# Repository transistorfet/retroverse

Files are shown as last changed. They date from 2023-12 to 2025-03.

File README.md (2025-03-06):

RetroVerse
==========

###### *Started August 06, 2023*

A collection of computer cards using the [VME bus](https://en.wikipedia.org/wiki/VMEbus) as a common
backplane, in the style of modular computer equipment, laboratory test equipment, and industrial
controls systems.  The project name is a combination of Retro-computers (newly designed and built
computers that are based on old CPUs and parts), and Versa (the V in VME, which stands for Versa
Module Eurocard).

I've always liked the VME bus for its adaptability.  It's an asynchronous bus with dynamic sizing,
so it can support both controllers and peripherals that require different signaling speeds and bus
widths to communicate, without requiring a specialized bus interface chip.  It supports multiple
controllers without the need for a special slot on the backplane, because it uses daisy chained
priority bus arbitration.  It's based on the Eurocard standard form factor, and uses standard and
readily available DIN41612 connectors, comes in a 3U variant, and it's possible to still buy
equipment that conforms to the standard, namely card cases and power supplies.  The 3U Eurocard
standard, which uses 160x100mm boards, is also fairly affordable for PCB printing, and it's possible
to make not-quite-standard 100x100mm cards, which can be printed for as low as $2.  The bus is
perhaps slow by modern standards, but for CPUs that are below 100MHz, it's the perfect bus to build
16-bit and 32-bit retro computers around.

So far, I have bought an off-the-shelf desktop card case from
[Schroff](https://schroff.nvent.com/en-de/products/enc24576-106) via Digikey (backordered), a used
Schroff 3U 11-slot backplane from eBay, and an affordable [MeanWell power
supply](https://www.meanwell.com/productPdf.aspx?i=488) to power it.  I've designed and built a CPU
card with a Motorola MC68030, onboard static RAM and Flash memory, and two serial ports, a small
16-bit memory card with up to 4MB of static RAM, and a board for handling the bus arbitration and
interrupt signals on the bus (separate from the CPU card since I intend to use multiple CPU cards in
the same system).  I've also built Tom Storey's CompactFlash card from
[COMET](https://github.com/tomstorey/COMET) to use as the main secondary storage for the system.
Before building these, I had also designed and built a generic card using an STM32 microcontroller
wired to the bus signals called
[BigBoy](https://github.com/transistorfet/retroverse/tree/main/components/bigboy), which I had hoped
to use as a bus analyzer, but it's a bit too slow for that, so I'll probably program it as a generic
peripheral instead.

I had originally intended to design and build my own backplane using 4-row connectors with some of
the P2 connector's signals on an extended P1, but I abandoned that idea in the interest of
interoperability with existing used VME equipment and ended up buying a used 11-slot Schroff
backplane from eBay.  Tom Storey has designed a 3-slot and 8-slot backplane as part of
[COMET](https://github.com/tomstorey/COMET) which is a good choice for those who wish to build their
own.

I also intend to eventually make an MC68010 version using only DIP chips and hopefully all hardwired
logic, so that there's no need for specialized PLD programmers.  I might also make cards with other
CPUs.  It should be possible for the system to support different CPUs in the same system at the same
time, running their own code.  My larger hope is for the VME bus to be used more broadly in the
hobbyist retro computer community as a common means of constructing systems.

Some of the design and build process was live-streamed and recordings are available at
[youtube.com/@transistorfet](https://www.youtube.com/@transistorfet)

Why VMEbus?
-----------

* it uses the eurocard form factor, and equipment such as cases can still be bought new or used

* it's asynchronous, so it can support devices operating at different speeds

* it supports dynamic bus sizing for 8-bit, 16-bit, and multiplexed 32-bit operations in 3U

* in the 6U form factor, it can also support full 32-bit or multiplexed 64-bit operations

* the DIN41612 connectors it uses are still widely available with solder tails

* supports cheap 3U board sizes of 100mm x 160mm or 100mm x 100mm

* also supports 6U board sizes for bigger and more complex devices

Why Not VMEBus?
---------------

* it can be a bit more complicated to interface to for simple 8-bit systems

* it's slower than newer buses like CompactPCI

* when using passive termination instead of active termination, it can draw a lot of current (2A+)
  with no cards

* each signal can draw a fair amount of current, which may be out of range for some logic chips (the
  standard requires that each pin can sink 48mA or more but typically it's <25mA in smaller and
  slower systems)

About VMEbus
------------

* [Understanding VMEBus](https://mdavidsaver.github.io/epics-doc/vme/understanding-vme.pdf)
* [VME FAQ from VITA](https://www.vita.com/VMEbus-FAQ)
* [VME P1 Connector Pinout](https://allpinouts.org/pinouts/connectors/buses/vme-versamodule-eurocard-p1/)
* [VME64](https://www.ge.infn.it/~musico/Vme/Vme64.pdf)

Other VME Projects
------------------

#### VMEbus prototyping card PCB:

* [https://github.com/rhaamo/VME](https://github.com/rhaamo/VME)

#### Proto Boards, Blanking Plates, Plate Adapters, ECB backplanes:

* [https://www.ebay.ca/usr/martenelectric](https://www.ebay.ca/usr/martenelectric)
* [https://www.martenelectric.cz/index.html](https://www.martenelectric.cz/index.html)

#### COMET backplane, prototyping card, and single board computer:

* [https://hackaday.io/project/192539-comet68k](https://hackaday.io/project/192539-comet68k)
* [https://github.com/tomstorey/COMET](https://github.com/tomstorey/COMET)
* computer card is missing bus arbitration, but the backplane supports it

[If you know of any other hobbyist VME components or projects that others can build, please get in
contact with me.  I'd love to add them to this list]

Single-CPU System
-----------------

This is generally where I'm at, as of March 2025.  I have a simple single-CPU system with
SystemBoard, k30p-VME, Tom Storey's CF Card, and MemBird Woodcock (although it's not used by the
software atm).  It can boot [Gloworm](https://github.com/transistorfet/gloworm), using the CF card
as the ATA device, and the FTDIs on k30p as the TTY and a SLIP connection for networking.  I can
ping it from my computer over SLIP, and run applications off the CF card.

![alt text](images/complete-single-cpu-system-front.jpg "A schroff 3U 63HP PropacPro case, looking face on and a bit downward at the front, which is trimmed in a very dark grey aluminum piece with two straight dull blue rounded aluminum top and bottom trim above and below where the cards are inserted.  The top of the case, which is barely showing, is light grey.  It has space for 15 slots spaced out horizontally, where cards can be inserted, oriented vertically, along bright red plastic guide rails.  Only 7 of the 10 guide rails are showing, with the others blocked by the front panels of 3 of the cards, with a gap of 3 slots between the second and third one.  The right 5 slots don't have guide rails.  The left-most slot has a blank aluminum plate with a few holes in it that allow a bright deep green LED inside to shine through.  Next to it is a white aluminum panel with black text that shows a partially obscured ComputieVME with a Motorola logo and k30p-VME below that.  It has 4 rows of pairs of LEDs and buttons, two USB-C ports with a mauve and a teal green cable plugged into each, and a white trapezoid handle below.  There's an empty slot and then Tom Storey's CF card is next to that with a CompactFlash card inserted in the front and no front panel.  Membird is next to it but not visible except for the dull green power LED.  BigBoy with a similar custom white aluminum front panel is next to it, with BigBoy in black text, 2 x 2 blue LEDs, a microSD slot, microB USB and RJ-11 jack labelled Ethernet on the front panel.  The right half of the 11-slot VME backplane is just visible, mounted in the left part of the case, with a space visible in the back where the remaining 4-slots-worth of space shows the back of the case, and the rear of the black power entry module.  Mounted in the right-most side of the case is a Meanwell powersupply taking up 8HP (2 slots), and the full 3U of height, wrapped in a thin metal shell with a diagonal pattern of round holes that expose most of the inside.  An 8HP blank plate with 4 knurled thumb-screws in the 4 corners and a trapezoid handle at the bottom and a protective film with 2 vertical blue lines still covering it, is mounted in the right most spot to block the power supply.")
![alt text](images/basic-single-cpu-system-angle.jpg "A green PCB backplane that says Schroff with white DIN41612 connectors, and 4 cards plugged into the first 4 of 11 slots.  The first and last are short 100mm long cards with the last being red and shown clearly while the first is black and is mostly obscured by the others.  The second card is purple with a white aluminum frontpanel that says 'ComputieVME', a Motorola logo, and 'k30p-VME' near the top in black text, with a trapezoid grey handle at the bottom, and two USB-C cables coming out of the frontpanel, the top one being a mauve and the the bottom being a light teal green.  The third card is green and has a compact flash card sticking out the top with no frontpanel.  The view is looking mostly down and to the left with the backplane flat on a black metal shelving unit about waist high, with the cards sticking upwards.  An oscilloscope can be be seen on the same shelf behind the backplane, and a small white fan is just out of view.")
![alt text](images/basic-single-cpu-system-side-angle.jpg "A green PCB backplane with white DIN41612 connectors, and 4 cards plugged into the first 4 of 11 slots.  The first and last are short 100mm long cards with the last being red and can mostly been seen while the first is black and is mostly obscured by the others.  The second card is purple with a white aluminum frontpanel with a trapezoid grey handle at the bottom, and two USB-C cables coming out of the frontpanel, the top one being a mauve and the the bottom being a light teal green.  The third card is green and has a compact flash card sticking out the top with no frontpanel.  The view is looking mostly sideways and a bit to the left, with backplane flat on a black metal shelving unit about waist high, with the cards sticking upwards.  An oscilloscope can be be seen on the same shelf behind the backplane, partially obscured by the cards.  A small white fan is just out of view, and a small teal desk lamp is in the foreground shining on the cards.")

Desktop Case
------------

I bought a brand new Schroff PropacPro 3U 63HP 266mm deep Unshielded Complete Desktop case.  I
initially requested a quote from Schroff, but unsurprisingly they sent me back a list of authorized
redistributors instead.  It turned out that Digikey did actually have the cases available for
backorder but the listing was uncategorized, so you had to search specifically for the part number
to find it.

* [https://schroff.nvent.com/en-ca/products/enc24576-006](https://schroff.nvent.com/en-ca/products/enc24576-006)
* [https://www.digikey.ca/en/products/detail/schroff/24576006/24659562](https://www.digikey.ca/en/products/detail/schroff/24576006/24659562)

I also bought a [Schurter Power Entry
Module](https://www.digikey.ca/en/products/detail/schurter-inc/4304-6091/2645678) and cut a hole in
the back aluminum panel to install it.  It's wired to the Meanwell RT-85B power supply, and power
from that is wired to the backplane.  I'd like to eventually add a current meter on the front,
mounted in an 8HP blanking plate I've bought, but I'm still waiting for parts to arrive.

![alt text](images/Schroff-case-and-backplane.jpg "A 3U 63HP desktop case with very dark grey front front and dull blue trim pieces made of rounded aluminum above and below the front card mounting rails, which have many small M2.5 screw holes horizontally, top and bottom, and are bright bare aluminum.  The left most 10-slots out of a maximum 15 have bright red card guides.  The case is empty of cards, but a Schroff 11-slot backplane is mounted in the rear of the case, most of the way back, and the rear panel is not in place.  The backplane is a green PCB with large white DIN41612 connectors that take up as much space as there is exposed green PCB.  The rest of the inside of the case is untreated bare aluminum.  A bundle of blue covered wire pair is just visible behind the case to the left, and a desk lamp and lego flowers are way in the background to the left, and a trans flag is barely visible to the right.")
![alt text](images/Schroff-case-and-backplane-rear.jpg "The rear of a 3U 63HP desktop case with no back panel looking inward, with a big green PCB with yellow silkscreen and yellow vertical through-hole resistor networks on the left and right sides, a white pin connector on the right most side, orange capacitors and metal screw terminals for power along the bottom edge, and the pins of the back sides of the DIN41612 sockets showing through.  It is covering most of the right side of the inside of the case, mounted on the rear rails inside the case.  The case is a light grey aluminum with vertical plastic rear feet/bumpers on the left and right sides.")
![alt text](images/Schroff-case-rear-panel-with-custom-switch.jpg "The rear of a 3U 63HP desktop case with no back panel looking inward, with a big green PCB with yellow silkscreen and yellow vertical through-hole resistor networks on the left and right sides, a white pin connector on the right most side, orange capacitors and metal screw terminals for power along the bottom edge, and the pins of the back sides of the DIN41612 sockets showing through.  It is covering most of the right side of the inside of the case, mounted on the rear rails inside the case.  The case is a light grey aluminum with vertical plastic rear feet/bumpers on the left and right sides.")

Backplane
---------

I bought a Schroff 23000-041 11-Slot backplane, used from eBay.  Luckily it has automatic
daisy-chaining, so when a slot doesn't have a card in it, the daisy-chained signals are shorted in
order to bypass that slot.  It also has active termination, which I have enabled with the jumpers,
so it takes only 10mA of 5V power without any cards connected.

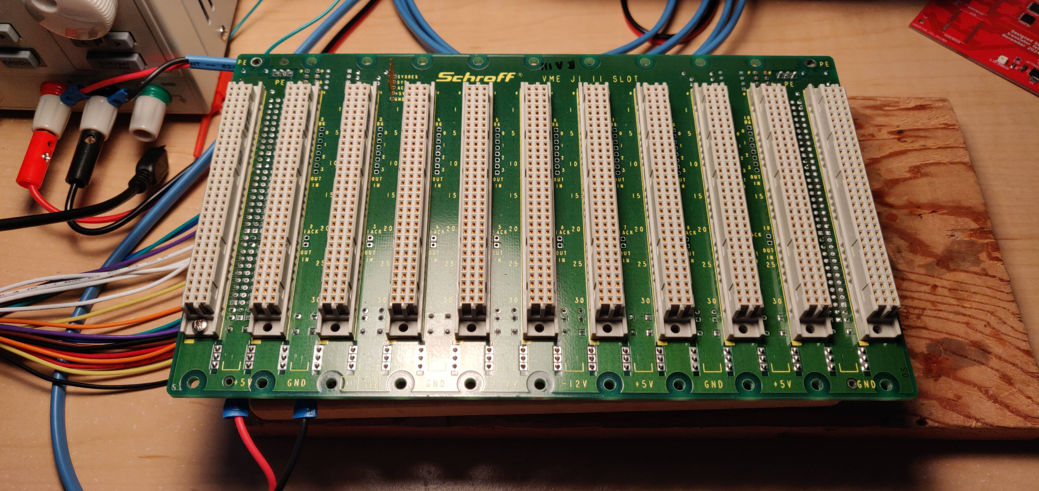
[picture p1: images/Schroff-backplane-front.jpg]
Schroff 23000-041 11-Slot VME Backplane with a green PCB and white DIN41612 connectors


k30p-VME
--------

A CPU card with a Motorola 68030 CPU, and an ATF1508AS CPLD for the control logic.  It has 2MB of
static RAM onboard, 512KB of Flash, a MC68681 dual serial port controller, with space for two
onboard FTDIs, and some push-button and LEDs that can be controlled by the serial controller.  The
CPLD can control the onboard transceivers to make a VME request from the CPU, based on the address
that the CPU is requesting.  I've tested it with 8-bit and 16-bit cycles, but I've designed it with
the transceivers that are required to make an A40/MD32 bus access, and hope to implement it soon
using BigBoy as the test peripheral.

While building the first revision, I found a number of issues.  The transceivers don't turn off when
the CPLD is being programmed, or when it's unprogrammed, and that means they write into each other,
and can damage each other.  I reworked in some pull-up resistors for the /OE signals to disable the
transceivers when the CPLD outputs are low or tri-stated.  I also originally had the FTDI powered by
the board, which meant it would disconnect from the computer every time the board was power cycled,
which was quite problematic when testing.  I tried to rework it so that it was powered by the USB
bus, but at first that didn't work.  After replacing the chip with an external FTDI, I tried
reworking it again and found that the USB-C cable only works in one orientation because I don't have
the main differential pair from each side of the USB-C connector jumped together.  The full errata
is here:
[k30p-VME-rev1-errata](https://github.com/transistorfet/retroverse/blob/main/components/computie-vme/hardware/k30p-VME/revisions/k30p-VME-rev1-errata.txt)

![alt text](images/k30p-VME-rev.1-reworked-assembled.jpg "The fully assembled and unplugged k30p-VME CPU Card, with purple solder mask, white silkscreen text, and a big greyish-white DIN41612 connector on the right side.  A big black plastic PGA chip in the centre reads MC68030RP33B.  There is some rework to the transceivers on the right, with some chip resistors and red 30AWG wire soldered in place, and some red 30AWG wire around the FTDIs on the left to power them from the USB bus.  A mauve-coloured USB-C cable is connected to the first USB port and a teal green USB-C cable is connected to the second USB port (bottom)")
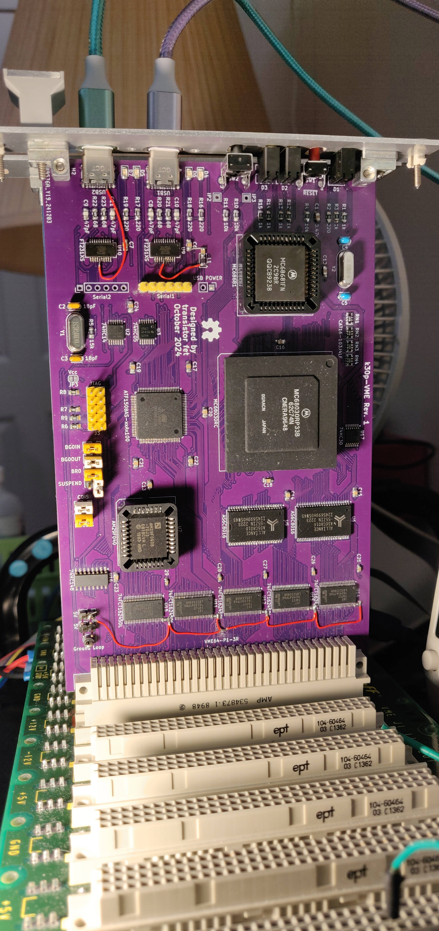
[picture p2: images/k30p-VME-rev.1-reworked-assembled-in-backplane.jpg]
The fully assembled k30p-VME CPU Card in the backplane, with purple solder mask and white silkscreen text

![alt text](images/k30p-rev.1-frontpanel.jpg "The bare aluminum back panel of the case, with vertical vent slots along the bottom.  The left ones have been cut away and a black power entry module is in the space, held in place by two screws above and below of the now-rotated module.  It has a big illuminated green rocket switch (powered off), a fuse holder, and a plug for an IEC power cable.  It's laying flat on the desk and just in view is the rear section of the inside frame of the case with the top and bottom panels removed showing the shiny aluminum rails with black silkscreen text showing the number markings from 1 to 63 HP, two rows which count in opposite directions and can be read in the orientation of ascending numbers (ie. the bottom row is right way up and the top row is upside down but could be read the right way from 1-63 if if the rail was turned around)")

MemBird Woodcock
----------------

A memory card with up to 4MB of either Static RAM or Pseudo-static RAM powered by either 5V or 3.3V,
which can be selected by a soldered jumper and by using different chips (memory and transceiver
chips in particular).  It can only respond to A24 cycles, and only 8-bit or 16-bit accesses, but
that should serve well enough as common memory for when I have multiple CPU cards.  In future I will
make another MemBird board with an FPGA and SDRAM to allow for 128MB+ of memory, but until then,
this will suffice.

The building of this board went really smoothly.  Soldering went better than normal for SMT parts.
I was using ChipQuik NoClean Liquid flux, which worked well.  I only had one chip that was visibly
unconnected on closer inspection, and I didn't find any unintended bridges.  The board was behaving
strangely when I first tested it before I cleaned the flux off, but once I cleaned it and let it dry
overnight, it worked perfectly.

It's named after the American Woodcock, a small bird that moves along with a slow rhythmic walk,
since this card only has a small amount of memory, and will be slower to access, being only 16-bits.

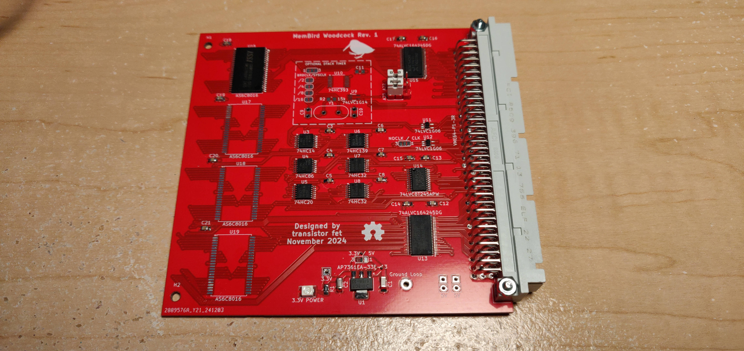
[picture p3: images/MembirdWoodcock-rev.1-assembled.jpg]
The fully assembled and unplugged MemBird Woodcock Memory Card, with red solder mask, white silkscreen text, and a big greyish-white DIN41612 connector on the right side. A silkscreen picture of an American Woodcock bird is near the top.

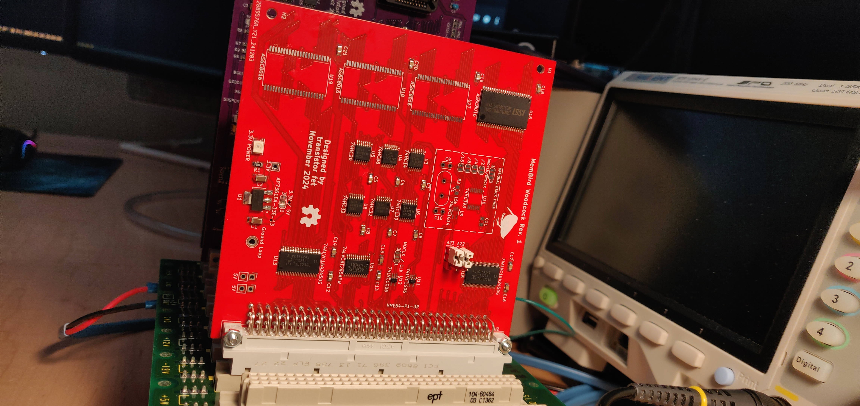
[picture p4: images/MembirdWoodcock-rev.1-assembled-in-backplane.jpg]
The fully assembled MemBird Woodcock Memory Card in the backplane, with red solder mask and white silkscreen text


SystemboardSMT
--------------

A system board with an ATF1508AS in the centre, and a clock, and that's about it.  It's primary
function is to handle the bus arbitration logic, but I can also use it as a dummy 8-bit peripheral
for testing.

I designed and built this board second, before the k30p and MemBird Woodcock, because it was simple
and would act as a test for the ATF1508, which I hadn't used before (other than in the devkit I
bought from Atmel).  The initial logic for the bus arbitration state machine turned out to be very
wrong, and that was causing problems for the k30p, which was hanging indefinitely.  I thought it was
the k30p's logic, but it turned out it wasn't receiving the bus grant from this card.

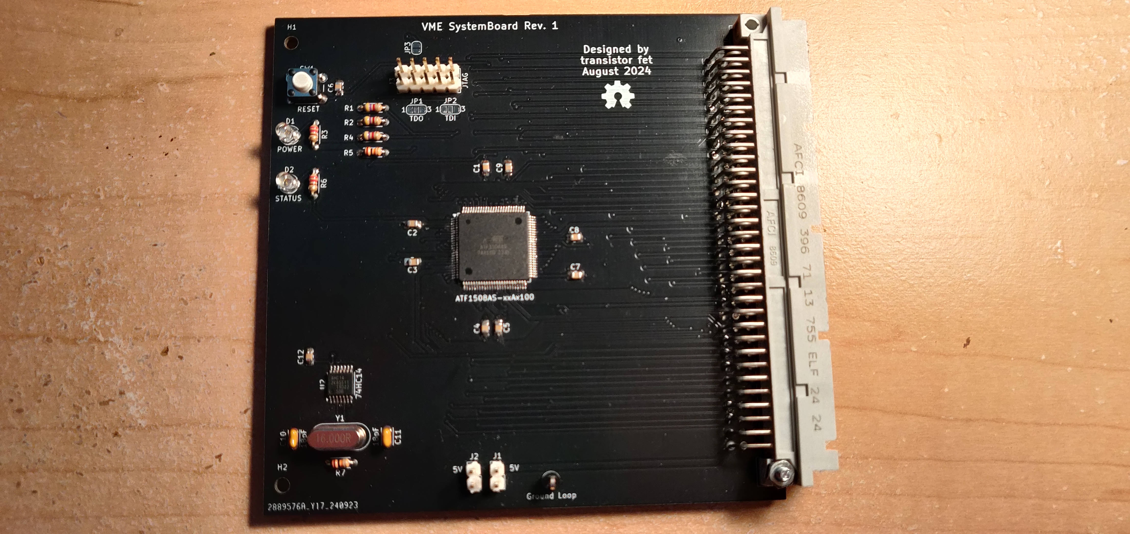
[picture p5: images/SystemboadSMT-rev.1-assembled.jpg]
The fully assembled and unplugged SystemboardSMT System Card, with matte black solder mask, white silkscreen text, and a big greyish-white DIN41612 connector on the right side.

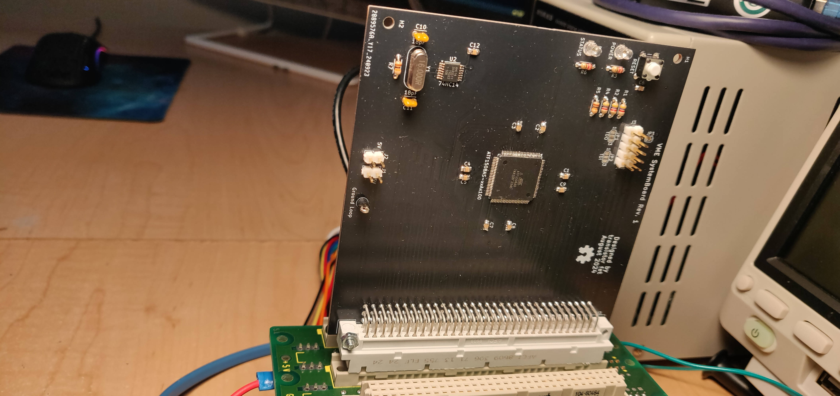
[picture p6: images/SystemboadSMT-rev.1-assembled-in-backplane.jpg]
The fully assembled SystemboardSMT System Card in the backplane, with matte black solder mask, white silkscreen text


BigBoy
------

This was the first card I made and I intended to use it as a bus analyzer among other things, but
it's a bit too slow to catch most cycles, so I think I'll need an FPGA card instead for that
function, but it can work as a slow peripheral.  It has an STM32H743 microcontroller in a 208 pin
QFP package in the centre with the 5V tolerant I/O connected directly to the VME bus for the control
signals, and through transceivers for the data and address signals.  On the board is also a 100BaseT
ethernet interface, a full speed USB port (so 12Mbps I assume is the fastest), a microSD card slot
(where I accidentally put the footprint on backwards), and a few headers for external FTDIs, I2C,
and SPI devices.

It's called BigBoy because it has the big boy microcontroller in the largest QFP package available,
with a big 4-row DIN41612 connector which was an idea to add an extra row to P1 for the upper data
and address signals of a 32-bit system, which is optional (the 4-row connector can be plugged into a
3-row or 4-row backplane).  I've mostly abandoned this idea in favour of sticking to the standard,
and using the A40/MD32 cycle on a 3U system, or perhaps eventually making a 6U system and cards if I
want full-sized, higher speed, 32- or 64-bit systems in the future, all while maintaining
interoperability with existing used backplanes.  The logo is of [Bronson the
Cat](https://www.instagram.com/iambronsoncat/?hl=en) who is *such a big boy*





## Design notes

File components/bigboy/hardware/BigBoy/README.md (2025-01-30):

BigBoy
======

Status: Built & Tested but with design issues (see errata)

Latest: Rev. 1

### About

A generic card with an STM32H7 microcontroller on it that interfaces to the VME bus using GPIO.
I had intended to use it as a bus analyzer, but it's a bit too slow for the k30p CPU at 12.5MHz.

The logo is of [Bronson the Cat](https://www.instagram.com/iambronsoncat/?hl=en)

[Revision 1 Notes & Errata](revisions/BigBoy-rev1-errata.txt)

[Revision 1 Schematic](revisions/BigBoy-rev1.pdf)

[Revision 1 Gerbers](revisions/BigBoy-rev1.zip)



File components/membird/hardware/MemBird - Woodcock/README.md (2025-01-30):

MemBird - Woodcock
==================

Status: Built & Tested

Latest: Rev. 1

### About

A 16-bit VME memory card with 4MB of Static RAM at either 5V or 3.3V

It's named after the American Woodcock, a small bird that moves along with a slow rhythmic walk,
since this card only has a small amount of memory, and will be slower to access, being only 16-bits.

They are very cute birds, with an adorable walk, and a funny call
https://www.youtube.com/watch?v=fpCO6CUH8Zc
https://www.youtube.com/watch?v=97nnyyvXzmA

[Revision 1 Notes & Errata](revisions/MemBird%20-%20Woodcock-rev1-errata.txt)

[Revision 1 Schematic](revisions/MemBird%20-%20Woodcock-rev1.pdf)

[Revision 1 Gerbers](revisions/MemBird%20-%20Woodcock-rev1.zip)

The fully assembled and unplugged MemBird Woodcock Memory Card, with red solder mask, white silkscreen text, and a big greyish-white DIN41612 connector on the right side. A silkscreen picture of an American Woodcock bird is near the top.
The fully assembled MemBird Woodcock Memory Card in the backplane, with red solder mask and white silkscreen text

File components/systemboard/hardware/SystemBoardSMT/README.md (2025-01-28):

SystemBoard
===========

Status: Built & Tested, with minor issues (see errata)

Latest: Rev. 1

### About

A somewhat generic card with an ATF1508 programmable logic device, which is intended to act as the
system board of the VME bus, handling the resolution and granting of the bus during bus
arbitration, and interrupt acknowledging.  It has a clock and a reset button, which can be
programmed in the logic to reset all devices on the bus.

[Revision 1 Notes & Errata](revisions/SystemBoardSMT-rev1-errata.txt)

[Revision 1 Schematic](revisions/SystemBoardSMT-rev1.pdf)

[Revision 1 Gerbers](revisions/SystemBoardSMT-rev1.zip)

The fully assembled and unplugged SystemboardSMT System Card, with matte black solder mask, white silkscreen text, and a big greyish-white DIN41612 connector on the right side.

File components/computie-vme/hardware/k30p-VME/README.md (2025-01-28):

k30p-VME
========

Status: Built & Tested but with many design issues (see errata)

Latest: Rev. 1

### About

A CPU card for a VME-based computer system using an MC68030 with some onboard RAM and Flash, and a
onboard serial ports with integrated FTDI Serial-to-USB controllers, and a programmable ATF1508
CPLD for glue logic.  The 'p' in the name stands for Programmable due to the CPLD.

I've built and tested Rev. 1 but had to do some rework to get it running, and there are some
uncorrectable issues with the design that will require a new revision.  The full list of issues is
available in the errata linked below.  I intend to make a Rev. 2 in the next few months

[Revision 1 Notes & Errata](revisions/k30p-VME-rev1-errata.txt)

[Revision 1 Schematic](revisions/k30p-VME-rev1.pdf)

[Revision 1 Gerbers](revisions/k30p-VME-rev1.zip)



Sourcing Parts
--------------

- MC68681
    - eBay, AliExpress, or other resellers are the only sources for these chips
- MC68030RC or MC68030RP:
    - eBay, AliExpress, or other resellers are the only sources for these chips

- 128-pin 13x13 PGA Socket
    - Phoenix Enterprise Connectors: https://www.peconnectors.com/sockets-pga-cpu-and-memory/hws4514/
    - Digikey: https://www.digikey.ca/en/products/detail/mill-max-manufacturing-corp/510-43-128-13-041001/7753825
    - Mouser: https://www.mouser.ca/ProductDetail/Aries-Electronics/128-PGM13039-10
    - (Not sure if correct pin arrangement) https://www.mouser.ca/ProductDetail/Preci-dip/510-87-128-13-041101

- everything else is currently in production (as of 2025) and should be available at Digikey or Mouser

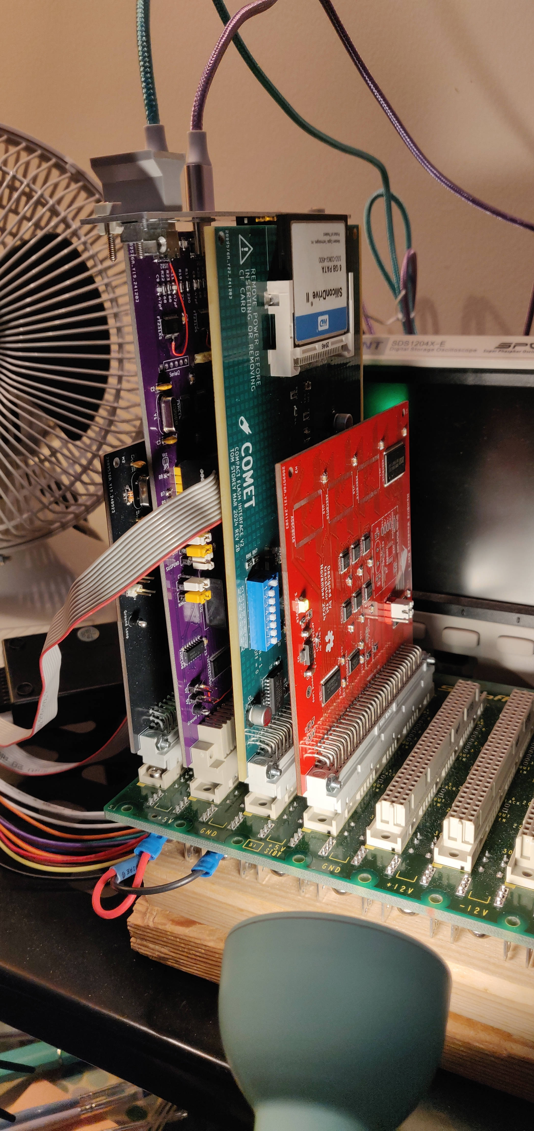
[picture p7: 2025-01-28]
images/basic-single-cpu-system-side-angle.jpg

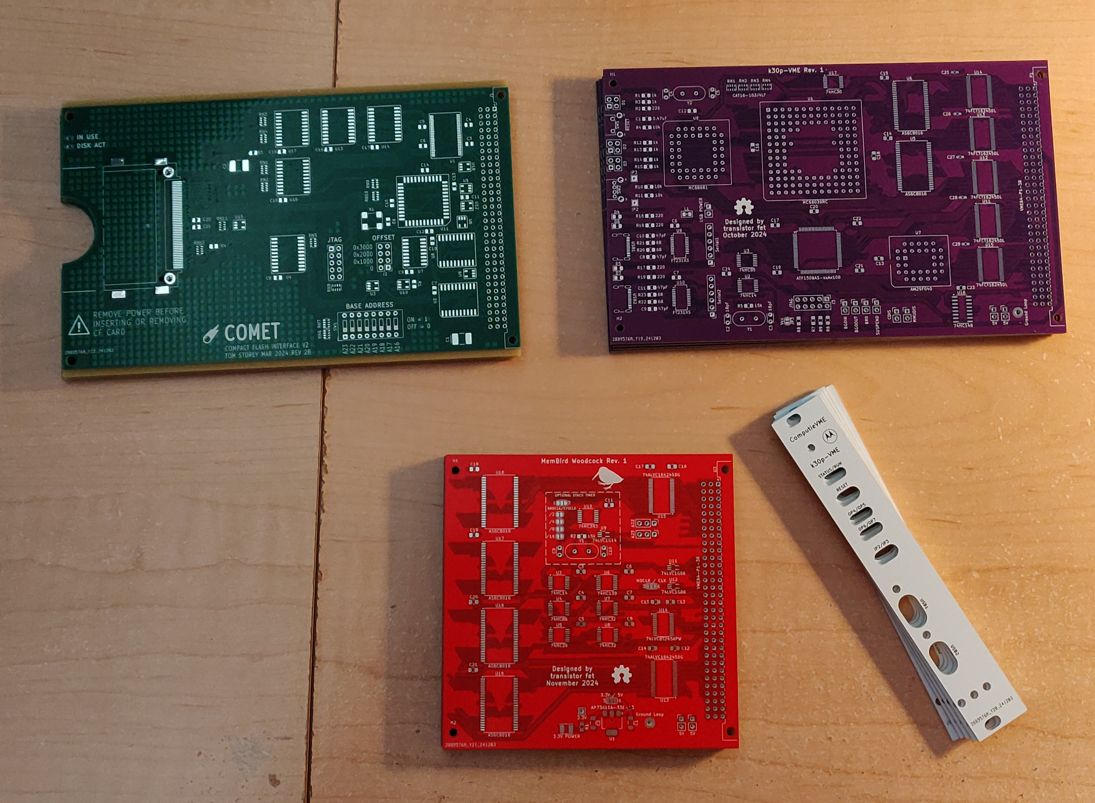
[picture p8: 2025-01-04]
images/boards.jpg

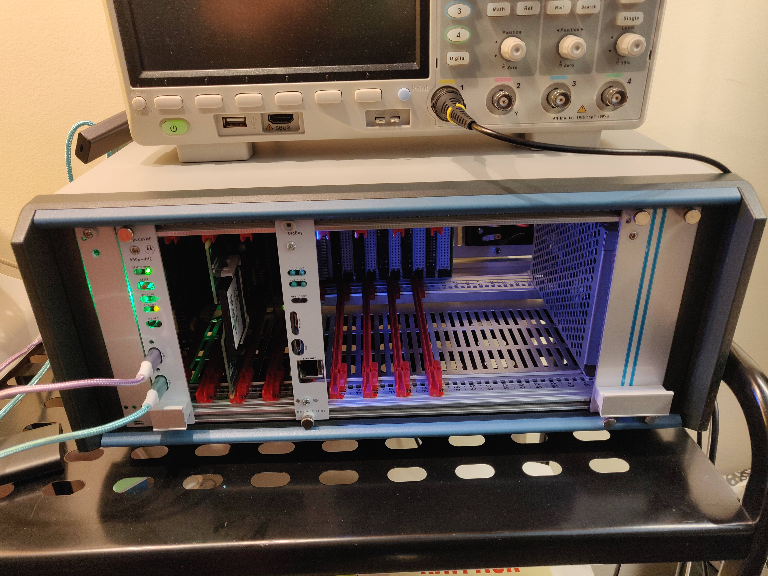
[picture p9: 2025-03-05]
images/complete-single-cpu-system-front-wide.jpg

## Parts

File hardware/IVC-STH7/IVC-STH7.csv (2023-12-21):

Source: | /media/work/ivy/hardware/IVC-STH7/IVC-STH7.kicad_sch
Date: | Tue 19 Dec 2023 10:53:34 AM
Tool: | Eeschema 7.0.9+dfsg-1
Generator: | /usr/share/kicad/plugins/bom_csv_grouped_by_value_with_fp.py
Component Count: | 120
Ref | Qnty | Value | Cmp name | Footprint | Description | Vendor | DNP
C1, C2 | 2 | 4.7uF | C_Small | Capacitor_SMD:C_1206_3216Metric_Pad1.33x1.80mm_HandSolder | Unpolarized capacitor, small symbol
C3, C5, C7, C8, C10, C11, C12, C13, C14, C15, C16, C17, C18, C19, C20, C21, C22, C23, C24, C25, C28, C29, C30, C31, C32, C34, C35, C36, C37, C38, C39, C40, C41, C42, C43, C44 | 36 | 0.1uF | C_Small | Capacitor_SMD:C_0805_2012Metric_Pad1.18x1.45mm_HandSolder | Unpolarized capacitor, small symbol
C4 | 1 | 1uF | C_Small | Capacitor_SMD:C_0805_2012Metric_Pad1.18x1.45mm_HandSolder | Unpolarized capacitor, small symbol
C6, C9 | 2 | 2.2uF | C_Small | Capacitor_SMD:C_0805_2012Metric_Pad1.18x1.45mm_HandSolder | Unpolarized capacitor, small symbol
C26, C27 | 2 | 5pF | C_Small | Capacitor_SMD:C_0805_2012Metric_Pad1.18x1.45mm_HandSolder | Unpolarized capacitor, small symbol
C33 | 1 | 10uF | C_Small | Capacitor_SMD:C_0805_2012Metric_Pad1.18x1.45mm_HandSolder | Unpolarized capacitor, small symbol
D1 | 1 | POWER | LED | LED_SMD:LED_PLCC-2_3.4x3.0mm_KA | Light emitting diode
D2 | 1 | Dialight 5530188F | LED_Dual_KAKA | Computie_Miscellaneous:Dialight 553-0xxxF | Dual LED, cathodes on pins 1 and 3
D3 | 1 | Dialight 5530177F | LED_Dual_KAKA | Computie_Miscellaneous:Dialight 553-0xxxF | Dual LED, cathodes on pins 1 and 3
H1, H2 | 2 | MountingHole | MountingHole | MountingHole:MountingHole_2.7mm_M2.5_DIN965 | Mounting Hole without connection
J1, J2, J4 | 3 | 5V | Conn_01x02 | Connector_PinHeader_2.54mm:PinHeader_1x02_P2.54mm_Vertical | Generic connector, single row, 01x02, script generated (kicad-library-utils/schlib/autogen/connector/)
J3, J5 | 2 | 3.3V | Conn_01x02 | Connector_PinHeader_2.54mm:PinHeader_1x02_P2.54mm_Vertical | Generic connector, single row, 01x02, script generated (kicad-library-utils/schlib/autogen/connector/)
J6 | 1 | Conn_ST_STDC14 | Conn_ST_STDC14 | Connector_PinHeader_1.27mm:PinHeader_2x07_P1.27mm_Vertical_SMD | ST Debug Connector, standard ARM Cortex-M SWD and JTAG interface plus UART
J7 | 1 | Hirose DM3D-S | Micro_SD_Card_Det1 | Connector_Card:microSD_HC_Hirose_DM3D-SF | Micro SD Card Socket with one card detection pin
J8 | 1 | Amphenol 10118194-0001LF | USB_B_Micro | Connector_USB:USB_Micro-B_Amphenol_10118194_Horizontal | USB Micro Type B connector
J9 | 1 | Bel SI-60062-F | RJ45_Bel_SI-60062-F | Connector_RJ:RJ45_Bel_SI-60062-F | 1 Port RJ45 Magjack Connector Through Hole 10/100 Base-T, AutoMDIX
J10 | 1 | SPI2 | Conn_01x06 | Connector_PinHeader_2.54mm:PinHeader_1x06_P2.54mm_Vertical | Generic connector, single row, 01x06, script generated (kicad-library-utils/schlib/autogen/connector/)
J11 | 1 | USART1 | Conn_01x06 | Connector_PinHeader_2.54mm:PinHeader_1x06_P2.54mm_Vertical | Generic connector, single row, 01x06, script generated (kicad-library-utils/schlib/autogen/connector/)
J12 | 1 | I^{2}C1 | Conn_01x04 | Connector_PinHeader_2.54mm:PinHeader_1x04_P2.54mm_Vertical | Generic connector, single row, 01x04, script generated (kicad-library-utils/schlib/autogen/connector/)
J13 | 1 | USART2 | Conn_01x06 | Connector_PinHeader_2.54mm:PinHeader_1x06_P2.54mm_Vertical | Generic connector, single row, 01x06, script generated (kicad-library-utils/schlib/autogen/connector/)
JP1 | 1 | BOOT | Jumper_3_Bridged12 | Connector_PinHeader_2.54mm:PinHeader_1x03_P2.54mm_Vertical | Jumper, 3-pole, pins 1+2 closed/bridged
JP2 | 1 | USB POWER | Jumper_2_Open | Connector_PinHeader_2.54mm:PinHeader_1x02_P2.54mm_Vertical | Jumper, 2-pole, open
JP3 | 1 | USART1 | Jumper_3_Bridged12 | Connector_PinHeader_2.54mm:PinHeader_1x03_P2.54mm_Vertical | Jumper, 3-pole, pins 1+2 closed/bridged
JP4 | 1 | SPI1 | Jumper_3_Bridged12 | Connector_PinHeader_2.54mm:PinHeader_1x03_P2.54mm_Vertical | Jumper, 3-pole, pins 1+2 closed/bridged
JP5 | 1 | USART2 | Jumper_3_Bridged12 | Connector_PinHeader_2.54mm:PinHeader_1x03_P2.54mm_Vertical | Jumper, 3-pole, pins 1+2 closed/bridged
JP6 | 1 | I^{2}C1 | Jumper_3_Bridged12 | Connector_PinHeader_2.54mm:PinHeader_1x03_P2.54mm_Vertical | Jumper, 3-pole, pins 1+2 closed/bridged
L1, L2 | 2 | 600Ω @ 100MHz (MI0805K601R-10) | L_Ferrite_Small | PCM_Ferrite_SMD_Handsoldering_AKL:Ferrite_0805_2012Metric_Pad1.15x1.40mm_BigPads | Inductor with ferrite core, small symbol
R1, R3, R8, R9, R14, R15, R16, R21, R22, R31, R32 | 11 | 10k | R_Small | Resistor_SMD:R_0805_2012Metric_Pad1.20x1.40mm_HandSolder | Resistor, small symbol
R2, R4, R5, R6, R7, R33, R34 | 7 | 220 | R_Small | Resistor_SMD:R_0805_2012Metric_Pad1.20x1.40mm_HandSolder | Resistor, small symbol
R10, R11, R12, R17, R18, R19, R20 | 7 | 33 | R_Small | Resistor_SMD:R_0805_2012Metric_Pad1.20x1.40mm_HandSolder | Resistor, small symbol
R13 | 1 | 51 | R_Small | Resistor_SMD:R_0805_2012Metric_Pad1.20x1.40mm_HandSolder | Resistor, small symbol
R23 | 1 | 1.5k | R_Small | Resistor_SMD:R_0805_2012Metric_Pad1.20x1.40mm_HandSolder | Resistor, small symbol
R24 | 1 | 12.1k | R_Small | Resistor_SMD:R_0805_2012Metric_Pad1.20x1.40mm_HandSolder | Resistor, small symbol
R25, R26, R27, R28 | 4 | 50 | R_Small | Resistor_SMD:R_0805_2012Metric_Pad1.20x1.40mm_HandSolder | Resistor, small symbol
R29, R30 | 2 | 68 | R_Small | Resistor_SMD:R_0805_2012Metric_Pad1.20x1.40mm_HandSolder | Resistor, small symbol
R35, R36 | 2 | 4.7k | R_Small | Resistor_SMD:R_0805_2012Metric_Pad1.20x1.40mm_HandSolder | Resistor, small symbol
SW1 | 1 | UB1/2 | SW_Push_Dual_x2 | Computie_Miscellaneous:E-Switch TL2243 | Push button switch, generic, separate symbols, four pins
SW2 | 1 | ~{RESET} | SW_Push | Button_Switch_THT:SW_PUSH_6mm | Push button switch, generic, two pins
TP1 | 1 | 3.3V | TestPoint | TestPoint:TestPoint_THTPad_2.0x2.0mm_Drill1.0mm | test point
U1 | 1 | AP7361EA-33E-13 | AP7361C-33E | Package_TO_SOT_SMD:SOT-223 | 1A Low Dropout regulator, positive, 3.3V fixed output, SOT-223
U2 | 1 | STM32H743BITx | STM32H743BITx | Package_QFP:LQFP-208_28x28mm_P0.5mm | STMicroelectronics Arm Cortex-M7 MCU, 2048KB flash, 1024KB RAM, 480 MHz, 1.62-3.6V, 168 GPIO, LQFP208
U3 | 1 | KC3225Z25.0000C1KX00 | KC2520Z | Crystal:Crystal_SMD_3225-4Pin_3.2x2.5mm_HandSoldering | 1.8432MHz ~ 125MHz Crystal Oscillator
U4 | 1 | LAN8742A | LAN8742A | Package_DFN_QFN:VQFN-24-1EP_4x4mm_P0.5mm_EP2.5x2.5mm_ThermalVias | LAN8720 Ethernet PHY with RMII interface, QFN-24
U5, U6, U7, U8, U9 | 5 | 74ALVC16245DG | 74ALVC16245DG | Computie_SMT:TSSOP-48_6.1x12.5mm_P0.5mm | 16-Bit Dual Supply Bidirectional Translating Transceiver with 5V Tolerant Inputs and Outputs, TSSOP-48
U10 | 1 | Hirose PCN10-128P-2.54DS(72) | VME64-P1-4R-NS | Computie_Connectors:DIN41612_C_4x32_Male_Horizontal_THT | VME64 P1 (Board-side Headers), 4 Row (Non-Standard) DIN41612 Connector
Y1 | 1 | 32,768Hz | Crystal | Crystal:Crystal_SMD_3225-4Pin_3.2x2.5mm_HandSoldering | Two pin crystal

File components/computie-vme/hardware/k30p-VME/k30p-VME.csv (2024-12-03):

Reference | Value | Datasheet | Footprint | Qty | DNP
C1 | 0.47uF | ~ | Capacitor_SMD:C_0805_2012Metric_Pad1.18x1.45mm_HandSolder | 1
C2,C3 | 18pF | ~ | Capacitor_THT:C_Disc_D3.0mm_W2.0mm_P2.50mm | 2
C4 | 15pF | ~ | Capacitor_THT:C_Disc_D3.0mm_W2.0mm_P2.50mm | 1
C5 | 5pF | ~ | Capacitor_THT:C_Disc_D3.0mm_W2.0mm_P2.50mm | 1
C6,C7,C12,C13,C14,C15,C16,C17,C18,C19,C20,C21,C22,C23,C24,C25,C26,C27,C28,C29,C30,C31,C32,C33 | 0.1uF | ~ | -- mixed values -- | 24
C8,C9,C10,C11 | 47pF | ~ | Capacitor_SMD:C_0805_2012Metric_Pad1.18x1.45mm_HandSolder | 4
D1 | Harvatek HV-32H307B | ~ | Computie_Miscellaneous:Harvatek_HV-32312-260-2SUB | 1
D2,D3 | Harvatek HV-32312 | ~ | Computie_Miscellaneous:Harvatek_HV-32312-260-2SUB | 2
D4,D5 | IN | ~ | LED_SMD:LED_0805_2012Metric_Pad1.15x1.40mm_HandSolder | 2
D6,D7 | OUT | ~ | LED_SMD:LED_0805_2012Metric_Pad1.15x1.40mm_HandSolder | 2
H1,H2 | MountingHole | ~ | MountingHole:MountingHole_2.7mm_M2.5_DIN965 | 2
J1,J2 | 5V | ~ | Connector_PinHeader_2.54mm:PinHeader_1x02_P2.54mm_Vertical | 2
J3 | JTAG | ~ | Connector_PinHeader_2.54mm:PinHeader_2x05_P2.54mm_Vertical | 1
J4 | Serial1 | ~ | Connector_PinHeader_2.54mm:PinHeader_1x06_P2.54mm_Vertical | 1
J5 | Serial2 | ~ | Connector_PinHeader_2.54mm:PinHeader_1x06_P2.54mm_Vertical | 1
JP1 | CDIS | ~ | Connector_PinHeader_2.54mm:PinHeader_1x02_P2.54mm_Vertical | 1
JP2 | MMUDIS | ~ | Connector_PinHeader_2.54mm:PinHeader_1x02_P2.54mm_Vertical | 1
JP4 | USB POWER | ~ | Connector_PinHeader_2.54mm:PinHeader_1x02_P2.54mm_Vertical | 1
JP5 | BG0IN | ~ | Connector_PinHeader_2.54mm:PinHeader_1x02_P2.54mm_Vertical | 1
JP6 | BG0OUT | ~ | Connector_PinHeader_2.54mm:PinHeader_1x02_P2.54mm_Vertical | 1
JP7 | BR0 | ~ | Connector_PinHeader_2.54mm:PinHeader_1x02_P2.54mm_Vertical | 1
JP8 | SUSPEND | ~ | Connector_PinHeader_2.54mm:PinHeader_1x02_P2.54mm_Vertical | 1
L1 | MI0805K601R-10 | ~ | PCM_Ferrite_SMD_Handsoldering_AKL:Ferrite_0805_2012Metric_Pad1.15x1.40mm_BigPads | 1
P1 | VME64-P1-3R |  | Connector_DIN:DIN41612_C_3x32_Male_Horizontal_THT | 1
R1,R3,R12,R13,R14,R15 | 1k | ~ | Resistor_SMD:R_0805_2012Metric_Pad1.20x1.40mm_HandSolder | 6
R2,R16,R17,R18,R19 | 220 | ~ | Resistor_SMD:R_0805_2012Metric_Pad1.20x1.40mm_HandSolder | 5
R4,R9,R10,R11 | 10k | ~ | Resistor_SMD:R_0805_2012Metric_Pad1.20x1.40mm_HandSolder | 4
R5 | 15k | ~ | Resistor_SMD:R_0805_2012Metric_Pad1.20x1.40mm_HandSolder | 1
R6,R7,R8 | 4.7k | ~ | Resistor_SMD:R_0805_2012Metric_Pad1.20x1.40mm_HandSolder | 3
R20,R21,R22,R23 | 68 | ~ | Resistor_SMD:R_0805_2012Metric_Pad1.20x1.40mm_HandSolder | 4
RN1,RN2,RN3,RN4 | CAT16-103J4LF | ~ | Resistor_SMD:R_Cat16-4 | 4
S1 | Logo_Open_Hardware_Small | ~ | Symbol:OSHW-Symbol_6.7x6mm_SilkScreen | 1
SW1 | ~{RESET} | ~ | Computie_Miscellaneous:E-Switch_TL1105 | 1
SW2 | E-Switch TL2243 | ~ | Computie_Miscellaneous:E-Switch_TL2243 | 1
TP1 | Ground Loop | ~ | TestPoint:TestPoint_Loop_D2.60mm_Drill1.6mm_Beaded | 1
TP5 | IP3 | ~ | TestPoint:TestPoint_THTPad_2.0x2.0mm_Drill1.0mm | 1
TP6 | IP2 | ~ | TestPoint:TestPoint_THTPad_2.0x2.0mm_Drill1.0mm | 1
U1 | MC68030RC |  | Computie_THT:PGA-128_13x13_THT-Socket | 1
U2 | 74HC14 | http://www.ti.com/lit/gpn/sn74HC14 | Package_SO:TSSOP-14_4.4x5mm_P0.65mm | 1
U3 | 74HC05 | http://www.ti.com/lit/gpn/sn74LS05 | Package_SO:TSSOP-14_4.4x5mm_P0.65mm | 1
U4 | ATF1508AS-xxAx100 | https://ww1.microchip.com/downloads/en/DeviceDoc/doc0784.pdf | Package_QFP:TQFP-100_14x14mm_P0.5mm | 1
U5,U6 | AS6C8016 | https://www.alliancememory.com/wp-content/uploads/pdf/lp_sram/AS6C8016.pdf | Package_SO:TSOP-II-44_10.16x18.41mm_P0.8mm | 2
U7 | AM29F040 | https://www.mouser.ca/datasheet/2/196/spansion_inc_am29f040b_eol_21445e8-3004346.pdf | Package_LCC:PLCC-32_THT-Socket | 1
U8 | MC68681 |  | Package_LCC:PLCC-44_THT-Socket | 1
U9,U10 | FT231XS | https://www.ftdichip.com/Support/Documents/DataSheets/ICs/DS_FT231X.pdf | Package_SO:SSOP-20_3.9x8.7mm_P0.635mm | 2
U11,U12,U13,U14,U15 | 74FCT16245DL | https://www.renesas.com/en/document/dst/5474fct16245t-datasheet | Package_SO:TSSOP-48_6.1x12.5mm_P0.5mm | 5
U16 | 74HC148 | http://www.ti.com/lit/gpn/sn74LS148 | Package_SO:SOIC-16_3.9x9.9mm_P1.27mm | 1
U17 | 74HC30 | http://www.ti.com/lit/gpn/sn74LS30 | Package_SO:TSSOP-14_4.4x5mm_P0.65mm | 1
USB1,USB2 | USB_C_Plug_USB2.0 | https://www.usb.org/sites/default/files/documents/usb_type-c.zip | Connector_USB:USB_C_Receptacle_GCT_USB4105-xx-A_16P_TopMnt_Horizontal | 2
Y1,Y2 | Crystal | ~ | Crystal:Crystal_HC49-4H_Vertical | 2

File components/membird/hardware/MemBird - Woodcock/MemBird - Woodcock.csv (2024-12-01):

Reference | Value | Datasheet | Footprint | Qty | DNP
C1,C2 | 4.7uF | ~ | Capacitor_SMD:C_1206_3216Metric_Pad1.33x1.80mm_HandSolder | 2
C3,C4,C5,C6,C7,C8,C11,C12,C13,C14,C15,C16,C17,C18,C19,C20,C21 | 0.1uF | ~ | Capacitor_SMD:C_0805_2012Metric_Pad1.18x1.45mm_HandSolder | 17
C9,C10 | 18pF | ~ | Capacitor_THT:C_Disc_D3.0mm_W2.0mm_P2.50mm | 2
D1 | POWER | ~ | LED_SMD:LED_PLCC-2_3.4x3.0mm_KA | 1
H1,H2 | MountingHole | ~ | MountingHole:MountingHole_2.7mm_M2.5_DIN965 | 2
J2,J3 | 5V | ~ | Connector_PinHeader_2.54mm:PinHeader_1x02_P2.54mm_Vertical | 2
R1 | 220 | ~ | Resistor_SMD:R_0805_2012Metric_Pad1.20x1.40mm_HandSolder | 1
R2 | 15k | ~ | Resistor_SMD:R_0805_2012Metric_Pad1.20x1.40mm_HandSolder | 1
S1 | Logo_Open_Hardware_Small | ~ | Symbol:OSHW-Symbol_6.7x6mm_SilkScreen | 1
TP1 | Ground Loop | ~ | TestPoint:TestPoint_Loop_D2.60mm_Drill1.6mm_Beaded | 1
TP2 | 3.3V | ~ | TestPoint:TestPoint_THTPad_2.0x2.0mm_Drill1.0mm | 1
U1 | AP7361EA-33E-13 | https://www.diodes.com/assets/Datasheets/AP7361C.pdf | Package_TO_SOT_SMD:SOT-223 | 1
U2 | VME64-P1-3R |  | Connector_DIN:DIN41612_C_3x32_Male_Horizontal_THT | 1
U3 | 74HC14 | http://www.ti.com/lit/gpn/sn74HC14 | Package_SO:TSSOP-14_4.4x5mm_P0.65mm | 1
U4 | 74HC86 | http://www.ti.com/lit/gpn/sn74HC86 | Package_SO:TSSOP-14_4.4x5mm_P0.65mm | 1
U5 | 74HC20 | http://www.ti.com/lit/gpn/sn74LS20 | Package_SO:TSSOP-14_4.4x5mm_P0.65mm | 1
U6 | 74HC139 | http://www.ti.com/lit/ds/symlink/sn74ls139a.pdf | Package_SO:TSSOP-16_4.4x5mm_P0.65mm | 1
U7,U8 | 74HC32 | http://www.ti.com/lit/gpn/sn74LS32 | Package_SO:TSSOP-14_4.4x5mm_P0.65mm | 2
U9 | 74LVC1G14 | https://www.diodes.com/assets/Datasheets/74LVC1G14.pdf | Package_TO_SOT_SMD:SOT-353_SC-70-5_Handsoldering | 1
U10 | 74LS393 | 74xx\74LS393.pdf | Package_SO:TSSOP-14_4.4x5mm_P0.65mm | 1
U11,U12 | 74LVC1G06 | https://assets.nexperia.com/documents/data-sheet/74LVC1G06.pdf | Package_TO_SOT_SMD:SOT-353_SC-70-5_Handsoldering | 2
U13,U15 | 74ALVC164245DG | https://assets.nexperia.com/documents/data-sheet/74ALVC164245.pdf | Package_SO:TSSOP-48_6.1x12.5mm_P0.5mm | 2
U14 | 74LVC8T245APW | https://assets.nexperia.com/documents/data-sheet/74LVC_LVCH8T245.pdf | Package_SO:TSSOP-24_4.4x7.8mm_P0.65mm | 1
U16,U17,U18,U19 | AS6C8016 | https://www.alliancememory.com/wp-content/uploads/pdf/lp_sram/AS6C8016.pdf | Package_SO:TSOP-II-44_10.16x18.41mm_P0.8mm | 4
Y1 | Crystal | ~ | Crystal:Crystal_HC49-4H_Vertical | 1

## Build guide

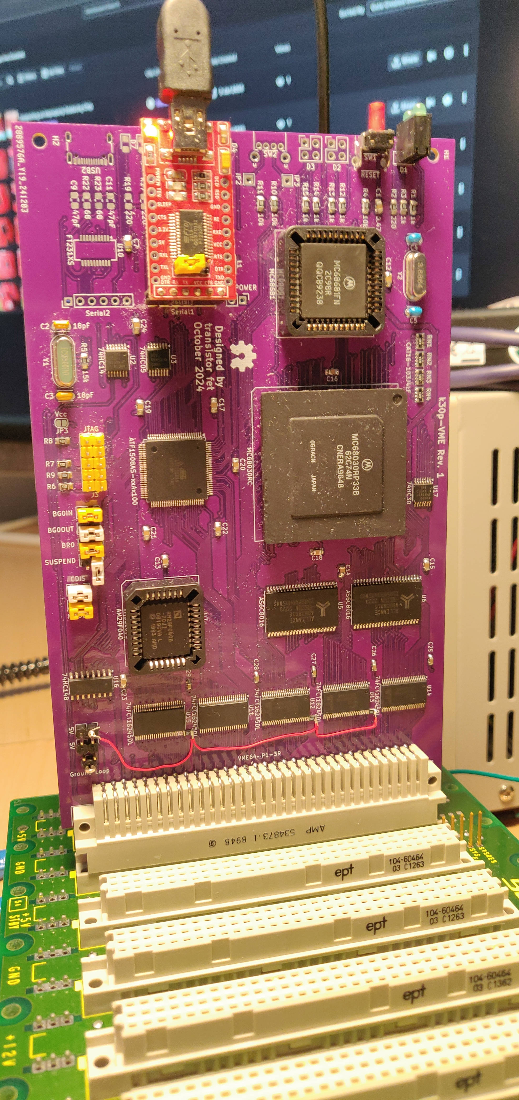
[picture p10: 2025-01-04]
images/k30p-VME-rev.1-assembled-in-backplane.jpg

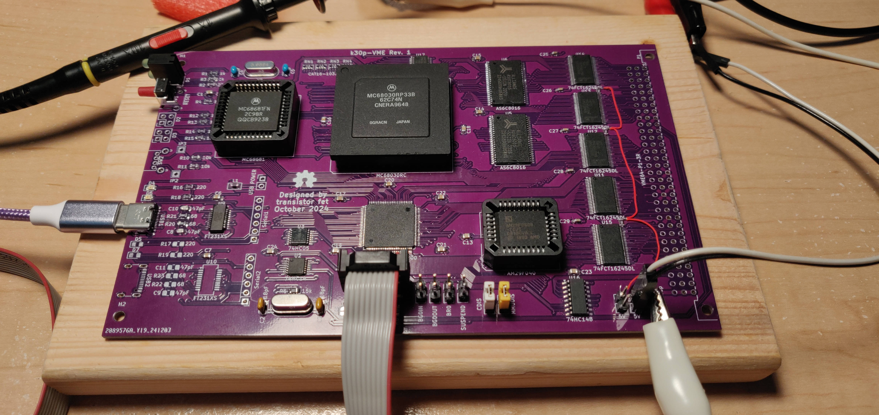
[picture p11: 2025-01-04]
images/k30p-VME-rev.1-assembled-bench.jpg

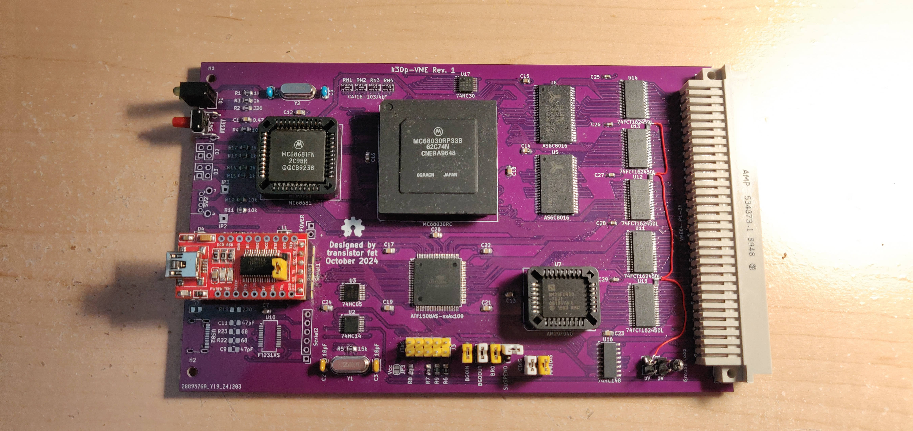
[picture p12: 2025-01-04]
images/k30p-VME-rev.1-assembled.jpg

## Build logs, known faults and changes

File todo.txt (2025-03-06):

* update the cover picture on jabberwocky.ca
* update the pictures of k30p with ones after the FTDI rework

* add damping resistors to the clock lines

* figure out why it doesn't boot correctly when first powered on.  Maybe the CPLD needs a special reset line, or it needs to be
  programmed to reset more than it does, or it needs to hold the reset low or something.  If it can't be solved in logic, I'll need
  to find a hardware solution

* add support for interrupts on the VME bus, which will require those extra address pins you connected
* add the unmapped address thing which should cause a bus error on unmapped
* make a simple peripheral with bigboy, possibly even a dummy ATA device to help with driver writing

* commit changes to CF Card and put it on github
* design a frontpanel for the CF Card, or else you could try cutting one, but I don't expect it to be easy or pretty if I do (do I
  need to build my own CNC machine?)

* make an extension board for membird that extend it to 160mm without needing the connectors that the riser board has
  It could have a power switch so the board under test can be cycled without cycling the system, and add headers near the front so
  you can connect a logic analyzer without needing to open the back of the case
* make an extension board that goes on the other end of the board, unlike the one with the two connectors, which cost more.  Just
  make one that somehow bolts to the existing 100mm card's frontpanel holes, and then has its own frontpanel bracket holes for the
  actual bracket and frontpanel

* test one of the real VME cards to see if it has the BERR blip too when AS is asserted too fast (I think it does)
* can you somehow fix the glitch on membird woodcock with berr being asserted.  Is the actual fix to delay the assertion of AS on
  the CPU card, since it's supposed to be 35ns delay, which would be more than enough to avoid this race condition

* add support for the A40 cycle to CPU card
* turn bigboy into an ethernet card

* figure out how you want to fix the upper addressing issue with the CPLD

* write a post about something

* design sdram card with ice40 fpga, printed in yellow?  called MemBird - Raven?  Something else if it's not black solder mask?
* design a board that uses a raspi compute module?  so basically the VME interface?
* make a breakout board, which you can design now and use with the components on order, to connect a logic analyzer

* if you put a right angle toggle switch for power on the front of the board (I guess bottom frontpanel would be easiest), then you
  could power off the board when it's in the slot, and pull it out without powering off the whole backplane.  It's probably only
  useful for CPU cards and might be more hassle in routing than it's worth, but would be a nice feature
* could add a microcontroller that monitors power and halt and resets the CPU after a period if it's locked up, and possibly other
  functions.  It might not be easy to make it accessible to the CPU on the controller card, but it could possibly be hooked up to
  the serial bus and communicate with other peripherals

BigBoy:

    * add ADC voltage monitor to big boy or a bus arbiter board to give a failure signal if the voltage is not within range I've had
      issues in testing where the voltage sagged due to the wire I was using, which could have been low enough to damage a sensitive
      board, so best if I had a signal for that
    * for future revisions, add a voltage and current monitoring circuit (at least current that bigboy is using)
    * should you replace the microUSB with USB-C?  I probably have a bunch of existing microUSB-B connectors, since I used that on fidget...
    * add detection for the extra bus pins on the 4th row.  If there's no power or something present, then assume it's not connected and
      the onboard logic can only do multiplexed operations

68k DIP Board:

    * for a future 68k cpu card, use a gpio from the serial controller to swap ram and flash, so it can be used for ProcessorTests validation

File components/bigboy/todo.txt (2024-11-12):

* in order to prevent transceivers from driving the same outputs, you'd need a dual 2-4 decoder, some invertors, and maybe an or/and gate for taking into account direction

* make a mode that you can at least manually select, where an external device can write data to the local bus with the cpu suspended, either using the A24/D16 cycle or the A32/D32
  cycle.  The A40/MD32 cycle is not possible without additional latches for the address, unless... you can use a transparent bidirectional latch, there is 74ABT16646 but it's in a
  56-pin package, and requires a clock, which makes it less of a drop in replacement

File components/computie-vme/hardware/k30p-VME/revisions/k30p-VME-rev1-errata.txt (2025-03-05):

Revision 1 Errata and Notes
===========================

- I put all the surface mount chips on first without programming the CPLD, and it caused almost 1.5A
  of current draw from the transceivers outputting into each other (very bad).  This also happens
  when programming the CPLD, because the /OE signals are active low, and when those outputs (driven
  by the CPLD) are high impedence during programming, it causes them to output into eachother again
  and get hot enough to burn my fingers.  I absolutely need to add logic to only enable one at a
  time, or pull the /OE signals high when not driven low.

- the JTAG connector labels are misleading and there's no pin 1 indicator, so it would be easy to
  connect it backwards

- inrush current is about 1.4A even though in only takes 100mA without the socketed chips.  Maybe
  I should add a 100 ohm resistor to limit the inrush, at least for select components

- the oscillator with a 50MHz crystal seems to be running at 16.666 MHz instead, and I think it's
  related to the 15k resistor across the crystal.  I'm seeing 1M ohm or even higher used in a lot of
  places, but if I put a big resistor in parallel (which should actually reduce the resistance below
  15k), it starts running at 50MHz, so it's definitely related to the resistor, but I'll have to play
  with sizes.  It turns out a 1K worked instead

- I've hooked up the USB-C connector incorrectly.  I only wired up one differential pair, but I
  should have jumped them to the matching pair, which are broken out as separate pins, and I also
  needed to add 5.1k pull down resistors to the CC1 and CC2 signals.  Apparently these are required.
  That said, I'm using a cable that only has the 4 pin USB-A connector on the other end, so I'm not
  sure this alone can explain why it's not enumerating at all.  As it turned out, it's working now,
  and I haven't tested it since I reflowed the FTDI so maybe that fixed it. [Ed: I've since determined
  that it depends on what orientation the USB-C connector is connected in, since the adjacent pairs
  are not jumped on the board, and they seem to not be jumped in the cable or in the connector, which
  I would have expected given that it's supposed to be for USB 2.0, but I guess it's up to the board
  to choose to connect them]

- the FTDI disconnects whenever power is cycled to the board, unlike the other boards I've had.
  This is because I wired it up as a self-powered device and not a bus-powered device like the
  adapter boards I have.  This could be annoying in practice, so I should consider changing how the
  FTDI itself is powered

- the jumper silkscreen labels aren't clear with respect to the logic value, and the symbol doesn't
  reflect whether the jumper should be installed or not

- the VRESET signal was not connected to the bus, so it wasn't pulled up during initial bringup and
  that was causing the CPU to reset sporadically, which was difficult to narrow down except by
  recognizing that touching the board was somehow causing it, but unreliably, and looking at what
  was connected around those areas

- if I had a power jumper for all 5V for the board (on every board, not just this one), I could
  figure out which board is drawing what current

- the CPLD can't directly see the upper 8 address lines, besides knowing that they're all high, so
  it can't determine if all the upper 8 address lines are all low, which means it can't properly
  select the local peripherals leaving the A40 space free.  Instead, it can only keep the A24 space
  free but if any request is in the range of the local peripherals (XX00_0000 to XX30_0000 for rom
  and ram, XX70_0000 for serial), it will issue a local request instead of an A40 VME request

- the serial interrupt requires a pull-up resistor or else it will always register as low.  The
  ATF1508 does have internal pull-ups from the looks of it, so I'll have to install an external one.
  It was previously directly connected to the CPU's IPL1 signal

- the footprint for the FTDI 20-SSOP doesn't really have enough visible pad space for soldering
  properly, which might be why it needed to be reflowed.  A footprint with longer pads would really
  help with hand soldering

- now that I have the FTDIs powered by the USB cable, when I power cycle the CPU or especially when
  I first power it on, it either doesn't run or spits out garbage characters.  I think it's a
  problem with the reset not being long enough.  I'll need to investigate more

- it would be really handy if I could have a 100MHz clock somehow.  I don't think a crystal can go
  high enough, so I might need a dedicated clock PLL chip, which I'm hesitant to use

- it might be good to put some series damping resistors in the clock traces, which might improve
  the clock signal a bit

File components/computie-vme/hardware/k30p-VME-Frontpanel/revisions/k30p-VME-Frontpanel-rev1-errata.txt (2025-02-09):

Revision 1 Errata and Notes
===========================

- the holes that connect to the board are slightly too far apart, so the panel has a tendency to bow
  outwards unless the holes are manually adjusted with a file

- since I printed it in 1.6mm thick aluminum instead of 2mm thick like the VME spec uses, the
  alignment posts for the fixed handle that's part of the Schroff 20818018 3U 4HP frontpanel kit
  have to be filed down or else it will interfere with the metal bracket pieces and not lay flat

- the holes for the LEDs and two-button piece are slightly too far to the left.  The LEDs fit, but
  are right against the right-hand edge of the hole, and there's about a millimeter of space on the
  left-hand side, so sliding them over just a smidge to the right would help (or sliding the
  board mounting holes to the left a bit, but I'll have to check how it lines up with the case
  before I'll know which is the better solution)

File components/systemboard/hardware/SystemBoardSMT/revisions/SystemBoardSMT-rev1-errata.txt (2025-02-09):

Revision 1 Errata and Notes
===========================

- the reset button doesn't have a pull-up resistor on it, so it always reads as low

- the silkscreen label for JP3 doesn't say its function (VCC for JTAG)

- the capacitor on the reset button is way too low.  I need to test with some intermediate values,
  but 0.1 or even 0.47uF is too low for a power-on reset to be detected by the CPLD.  10uF
  definitely works and will reset the whole system when powered, but maybe a 1uF ceramic would be
  enough.  I'll have test more

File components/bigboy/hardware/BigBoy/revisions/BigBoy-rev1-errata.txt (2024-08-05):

Revision 1 Errata and Notes
===========================

- the text on the chip is aligned so that pin 1 is in the lower left corner, but that is the top of
  the chip on the board, so the text is upside down but it's a minor issue

- the UART headers are oriented the wrong way, such that the extension boards I have face inward
  towards the main chip.  I have other header cables, but it should be fixed on the next revision 

- the transceiver OE and DIR inputs for the address and data bus are swapped between address and
  data, so AL_OE and AL_DIR control the lower data bus signals, and the DL_OE and DL_DIR signals
  control the lower address bus signals.  In this case, it really only affects the labels since
  each of those transceiver control signals are driven directly by I/Os.  It's a good thing in
  hindsight that I didn't try to combine them using function-specific assumptions that would have
  required a more substantial workaround, but it came at the expense of more I/Os 

- a minor improvement would have been to route all the 5V from the bus through a jumper so, which
  would have allowed current measurements of what's being drawn from the bus.  Same for the 3.3V
  regulator, to know what the load on the LDO is at any given time.

- it would have helped to have an I/O connected to 5V through a resistor, so it could use it as an
  analog input and assert the SYSRESET signal in software until the voltage is above the minimum
  of 4.85V

- the microSD card slot is backwards, so the card has be inserted from the board-side, instead of
  the being accessible through the slot opening. It's still possible to get the card in, but hard
  to get it out.  I haven't tried accessing it though, so I don't know if it works electrically

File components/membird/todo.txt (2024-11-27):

* make an sdram card with fpga for the controller

TODO: if you did MD32, you'd have two more 16-bit transcievers
(these are using positive logic, so need to be translated)
B0OE <- CS_ANY & (!LWORD & !A1 | LWORD) & DS0
B1OE <- CS_ANY & (!LWORD & !A1 | LWORD) & DS1
B2LOE <- CS_ANY & !LWORD & A1 & DS0
B3LOE <- CS_ANY & !LWORD & A1 & DS1
B2UOE <- CS_ANY & LWORD
B3UOE <- CS_ANY & LWORD

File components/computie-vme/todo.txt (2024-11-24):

To Do for ComputieVME
=====================

- should you used 0603 caps for space saving?

- make a fully static design if possible, possibly removing the A40/MD32 cycle if it's too complex

- looking more into the other signals, DBEN doesn't look as valuable, because it mostly mirrors either AS or DS depending on a read or write
  but ECS might be valuable because it goes low before AS does, which could be used to request the bus and put the address information on the
  bus before the AS signal goes low (by one half clock)
- should you use the DBEN output or DS in the logic to control the data bus transceivers

- use AVEC to end an interrupt cycle
- use the serial controller's GPIO as flags to change the selected bus access type or just generally some kind of programmable hardware/register flag/switch, without needing the data bus on the PL

- do you need a phase locked loop to go even higher, to 100MHz? to drive the logic fast enough, or is it ok to go at a minimum of 3 clock cycles per operation
- You'll probably want a 50MHz clock, which you can convert either to a 25MHz clock, or just output it at 50MHz for the CPU, since the clock doesn't go directly to the CPU

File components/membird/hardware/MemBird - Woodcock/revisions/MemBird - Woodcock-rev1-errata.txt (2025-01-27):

Revision 1 Errata and Notes
===========================

- the logic that drives BERR has a ringing that dips below the ON threshold causing a small blip in
  BERR, which could very well be interpreted as a failure.  It doesn't seem to be caught in time by
  the k30p, but it's definitely incorrect.  It's likely caused by the delay between the two inputs,
  which have to both be on at the same time in order for the request to be "valid" (ie. not BERR).
  This may not actually be the fault of this card though, as the CPU card is not delaying the
  assertion of AS until 35ns after the address and address mod signals become active

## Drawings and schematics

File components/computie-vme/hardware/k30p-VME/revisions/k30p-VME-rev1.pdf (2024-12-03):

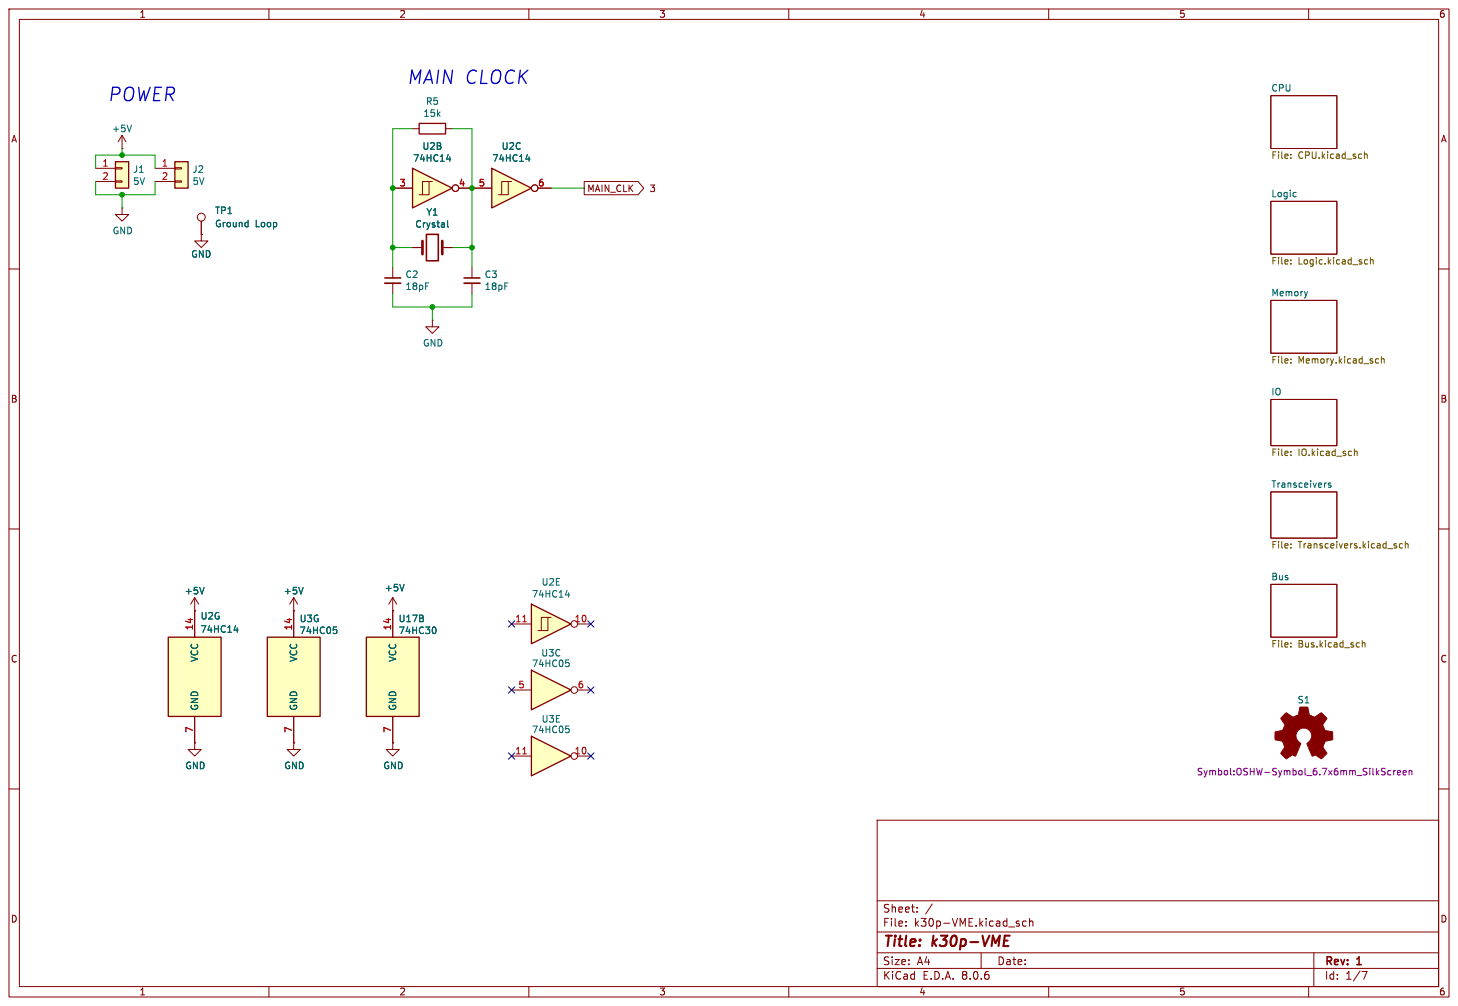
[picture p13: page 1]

CPU
Logic File: Logic.kicad_sch Transceivers File: Transceivers.kicad_sch Memory File: Memory.kicad_sch

74HC14 Y1 Crystal GND VCC 14 GND

File: IO.kicad_sch Bus File: Bus.kicad_sch +5V

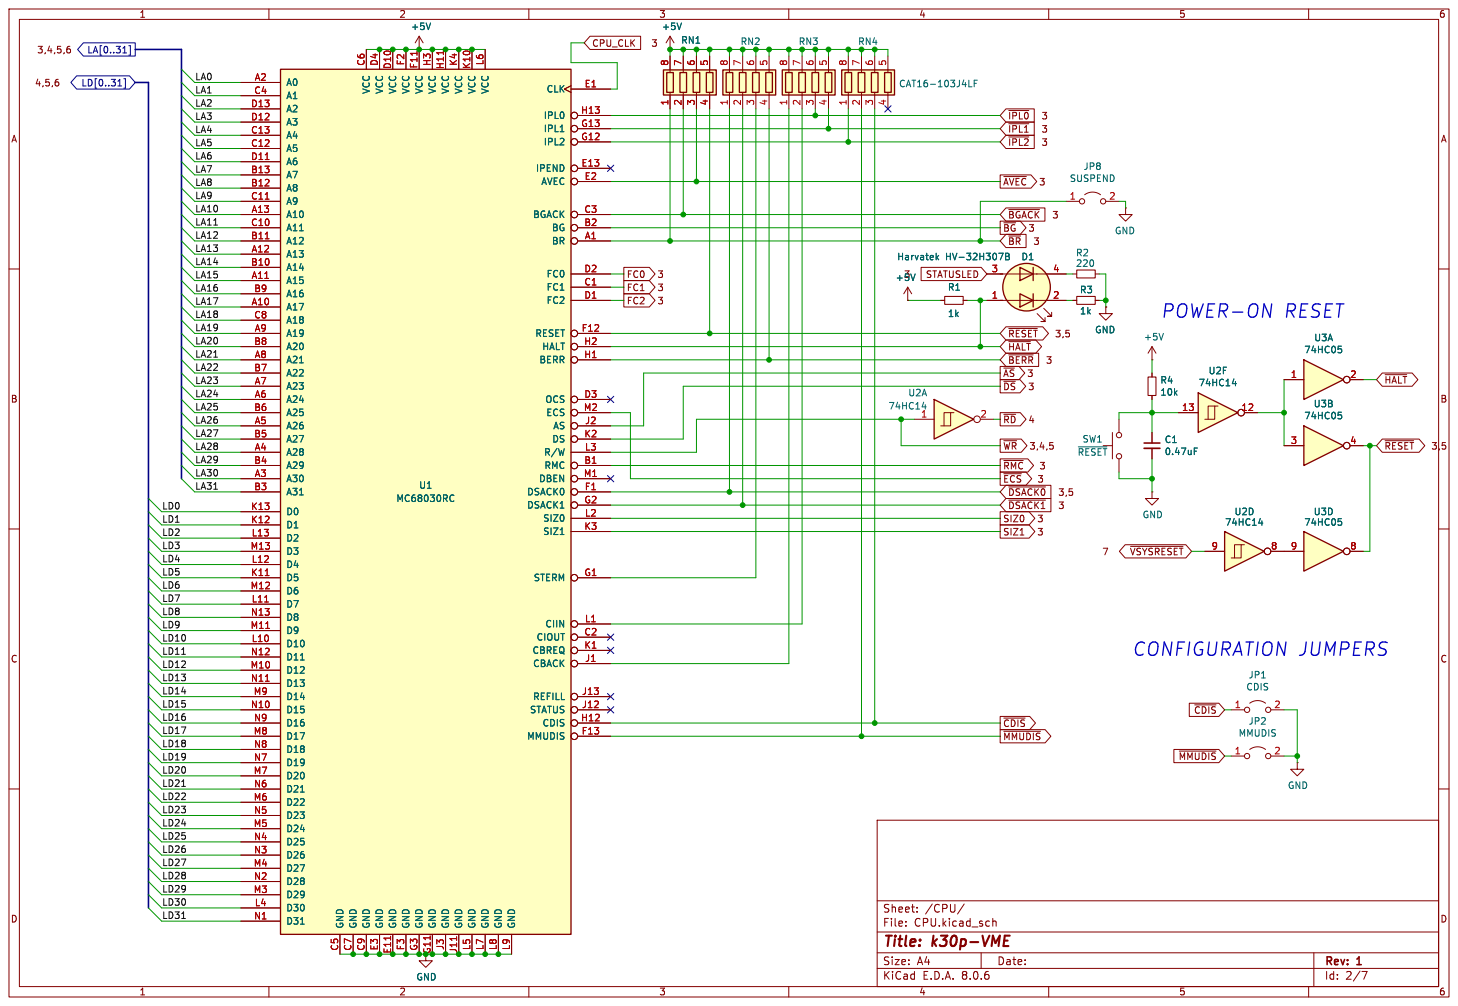
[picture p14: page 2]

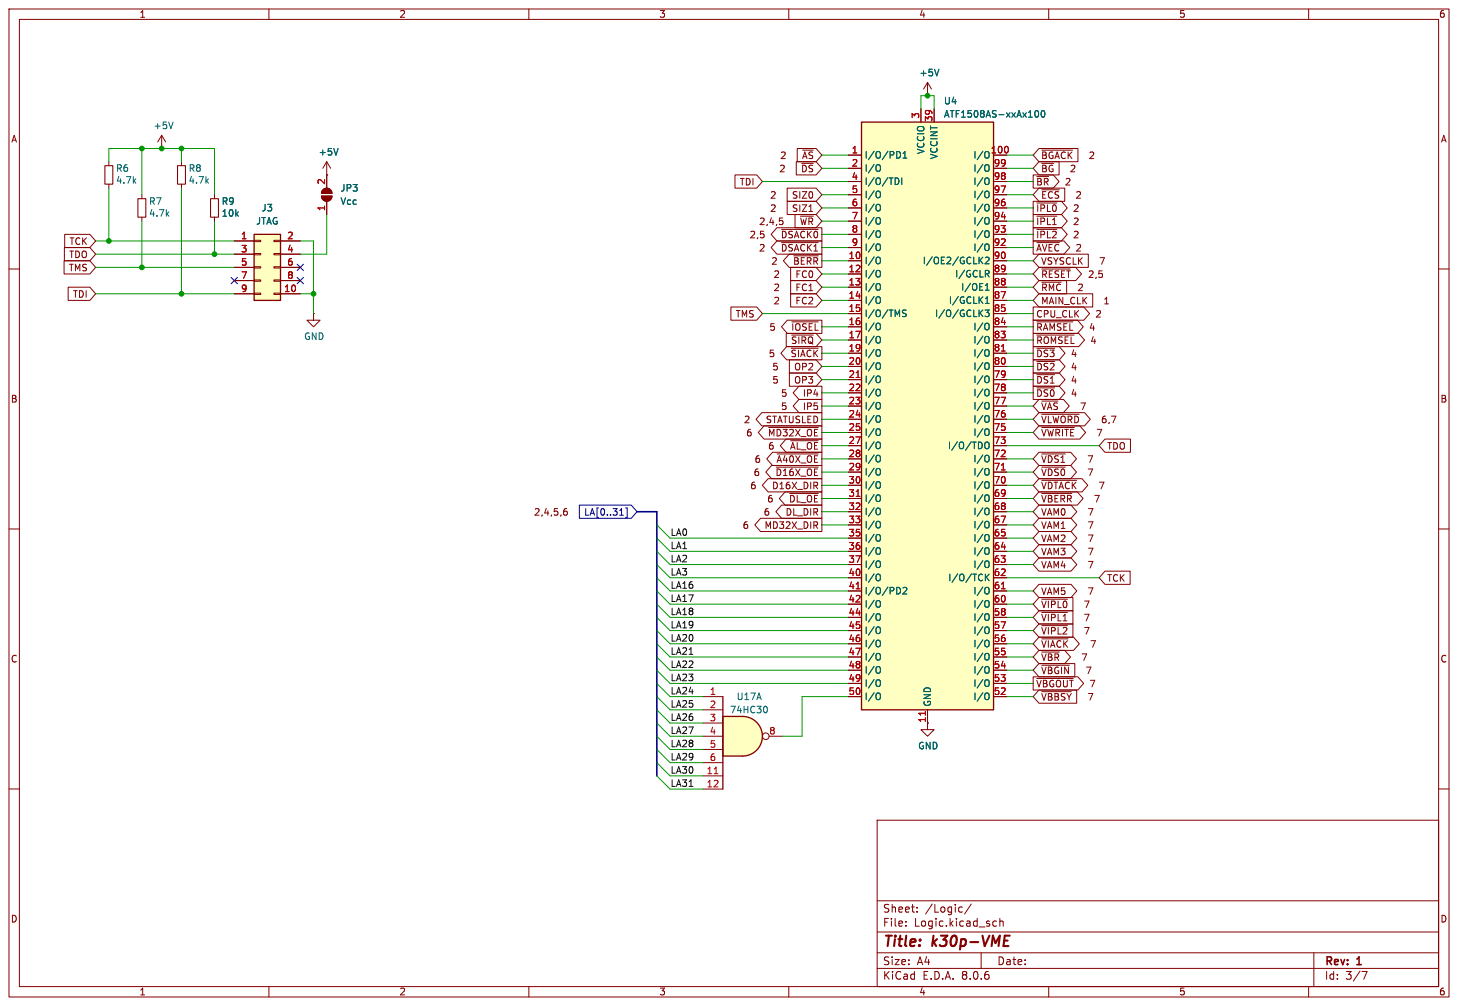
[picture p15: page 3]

File: Logic.kicad_sch Sheet: /Logic/ 1

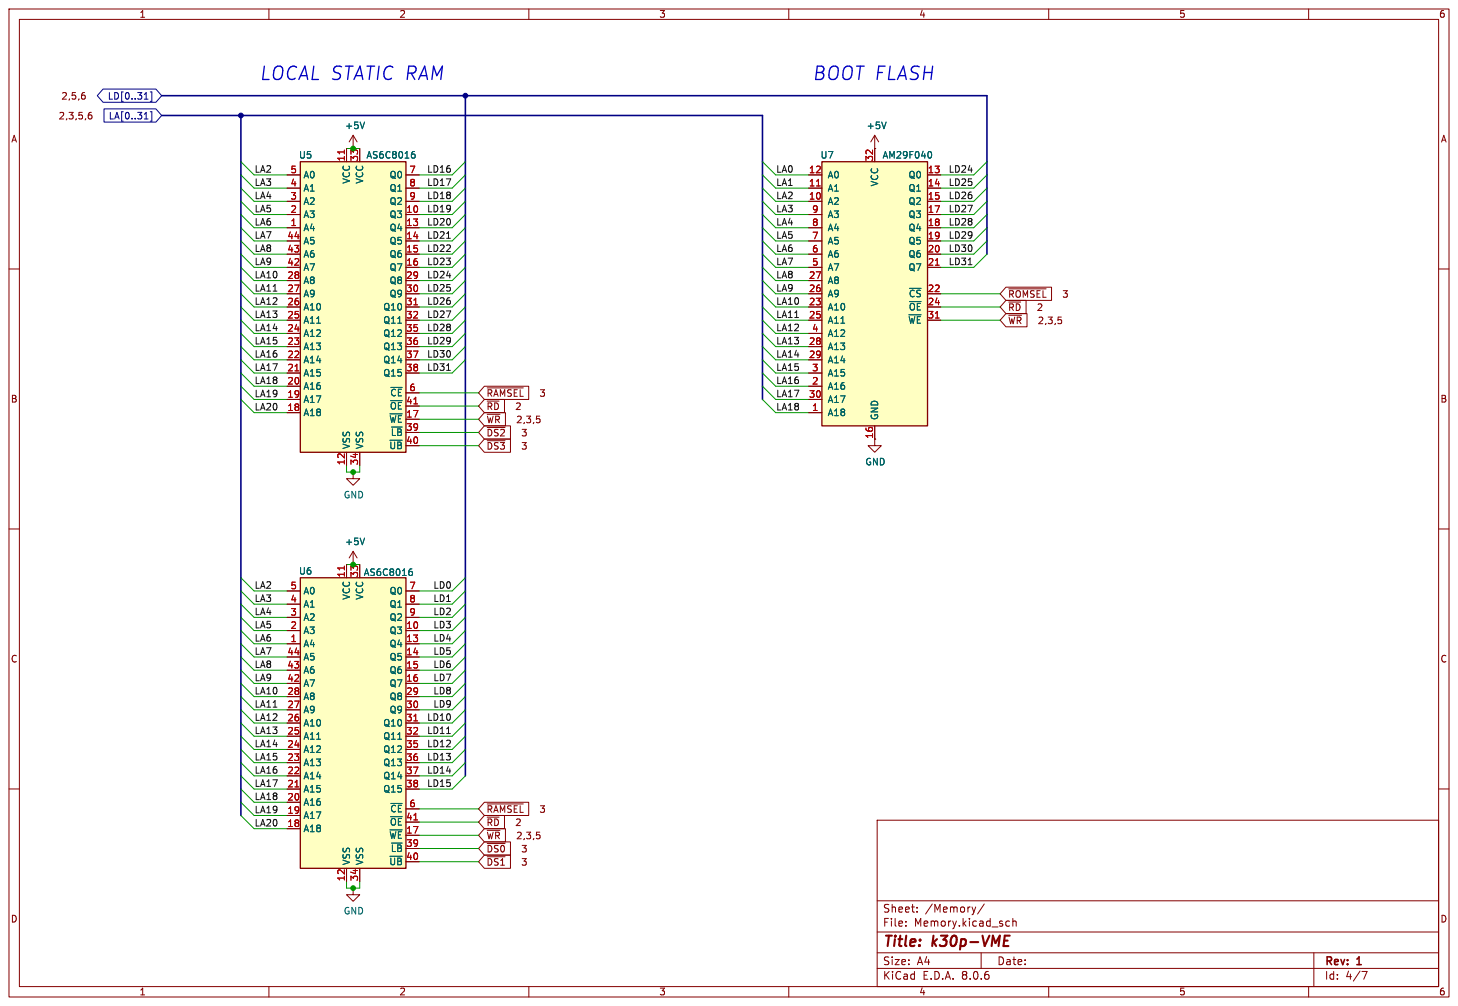
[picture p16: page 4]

File: Memory.kicad_sch Sheet: /Memory/
Id: 4/7 Title: k30p-VME

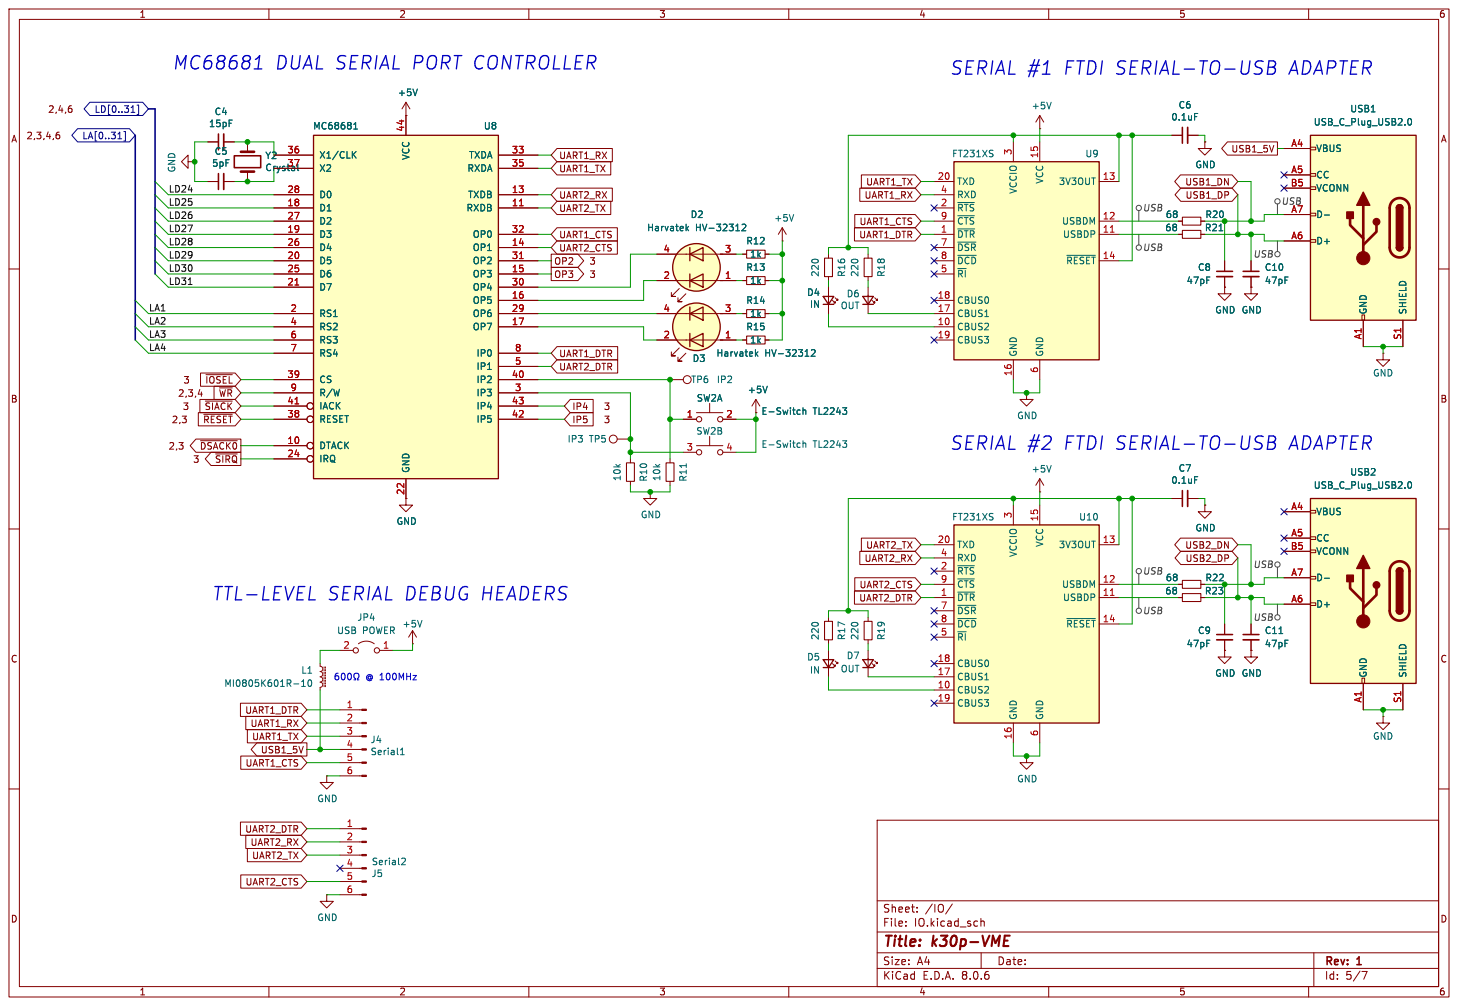
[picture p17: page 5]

File: IO.kicad_sch Sheet: /IO/
Id: 5/7 Title: k30p-VME

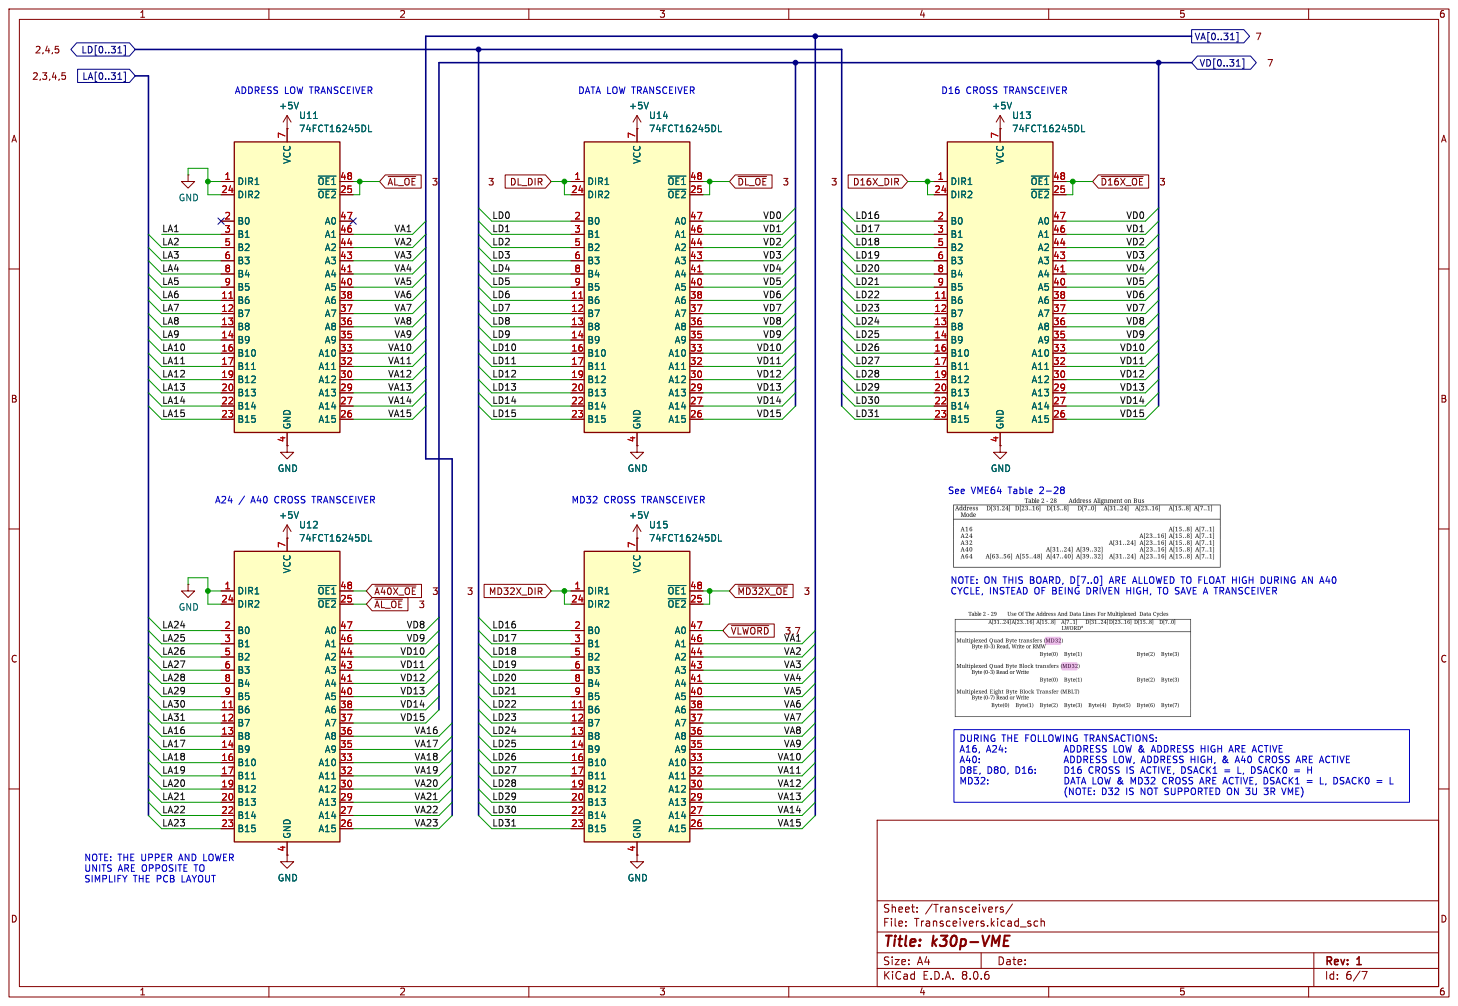
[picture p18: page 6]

DATA LOW TRANSCEIVER MD32 CROSS TRANSCEIVER

SIMPLIFY THE PCB LAYOUTA24 / A40 CROSS TRANSCEIVER

NOTE: THE UPPER AND LOWER
UNITS ARE OPPOSITE TO

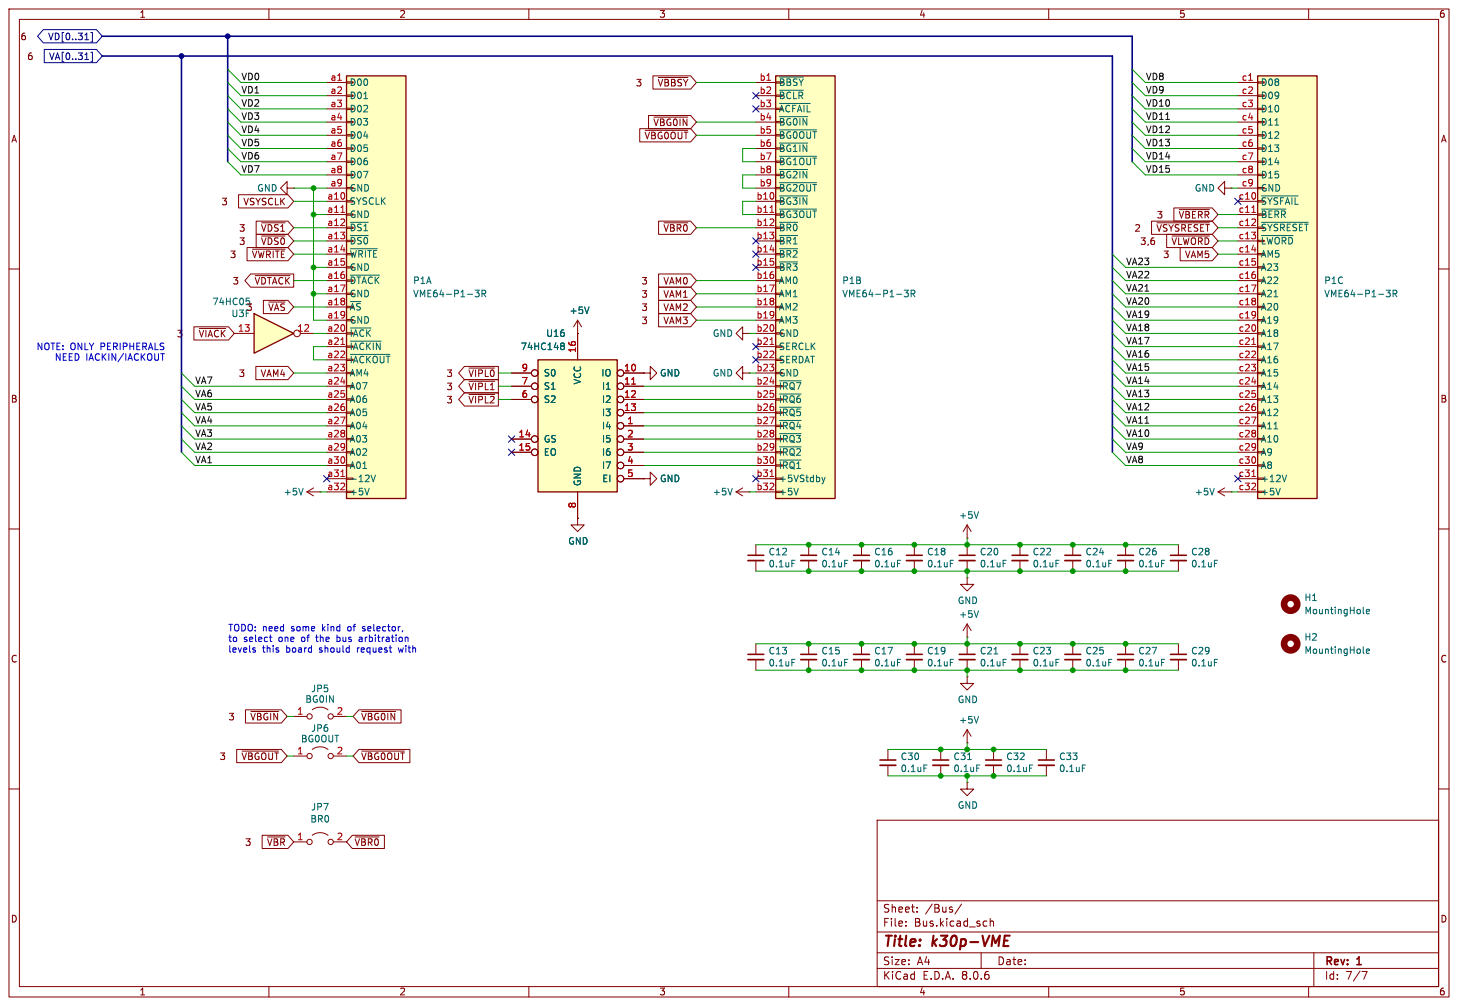
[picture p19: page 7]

D00 a1 SYSCLK a10 GND a11 ~{DS1} a12 ~{DS0} a13 ~{WRITE} a14 GND a15 ~{DTACK} a16 GND a17 ~{AS} a18 GND a19 D01 a2 ~{IACK} a20 ~{IACKIN} a21 ~{IACKOUT} a22 AM4 a23 A07 a24 A06 a25 A05 a26 A04 a27 A03 a28 A02 a29 D02 a3 A01 a30

TODO: need some kind of selector,
to select one of the bus arbitration

File: Bus.kicad_sch Sheet: /Bus/
Id: 7/7 Title: k30p-VME

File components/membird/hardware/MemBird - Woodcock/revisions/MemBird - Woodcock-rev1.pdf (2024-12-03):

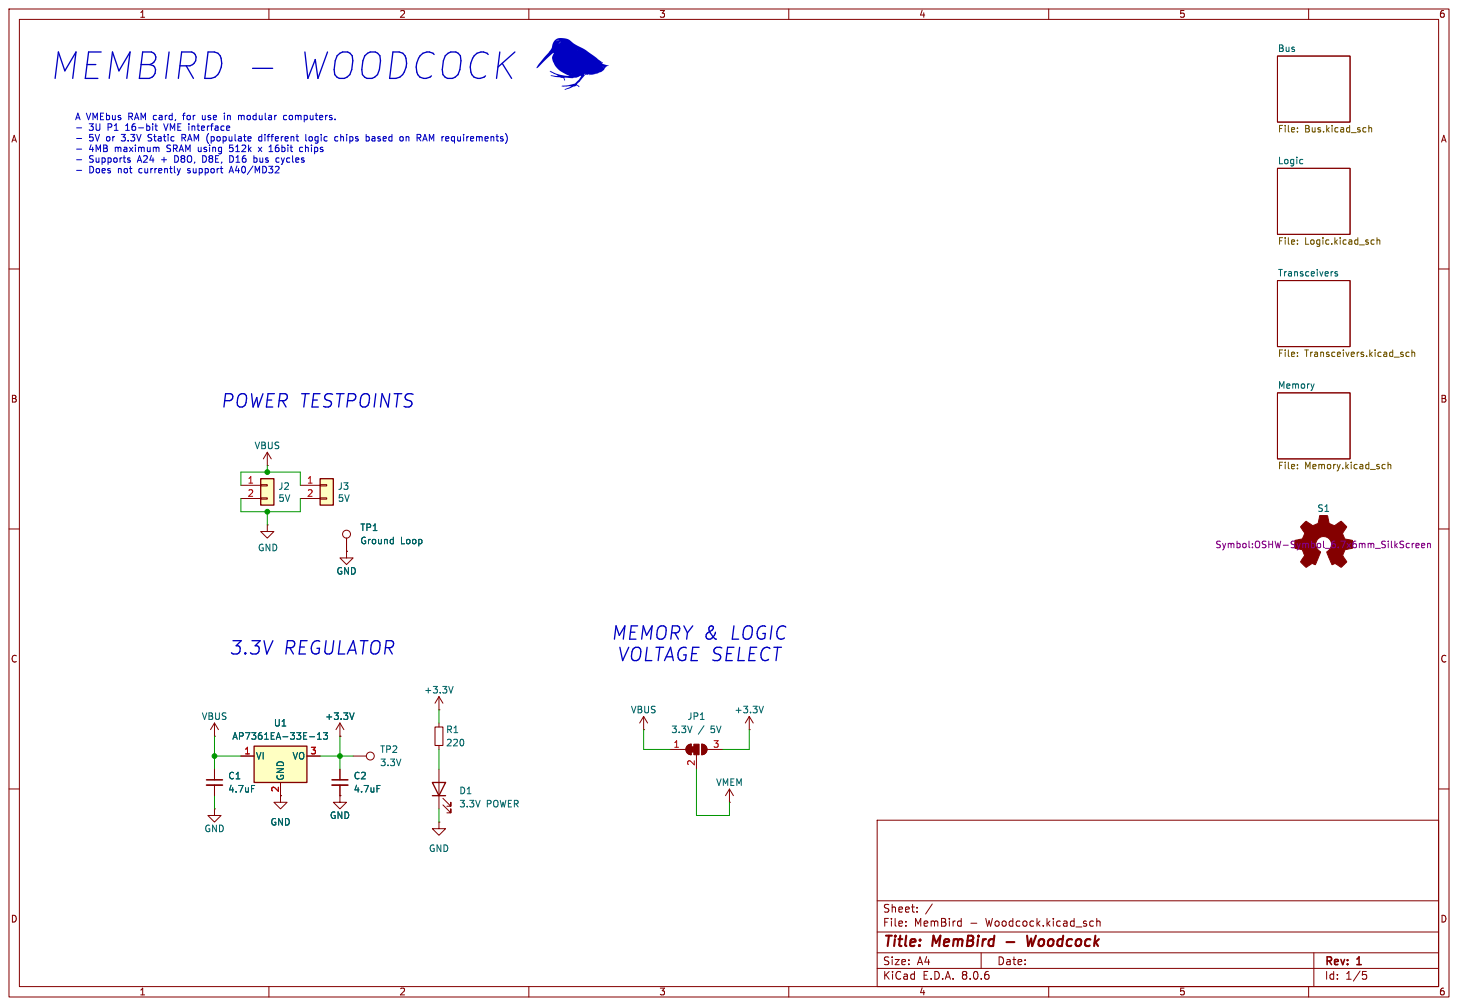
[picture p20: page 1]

TP1 Ground Loop GND MEMBIRD - WOODCOCK

Logic File: Logic.kicad_sch Transceivers File: Transceivers.kicad_sch Memory File: Memory.kicad_sch Bus File: Bus.kicad_sch GND GND

Id: 1/5 Title: MemBird - Woodcock

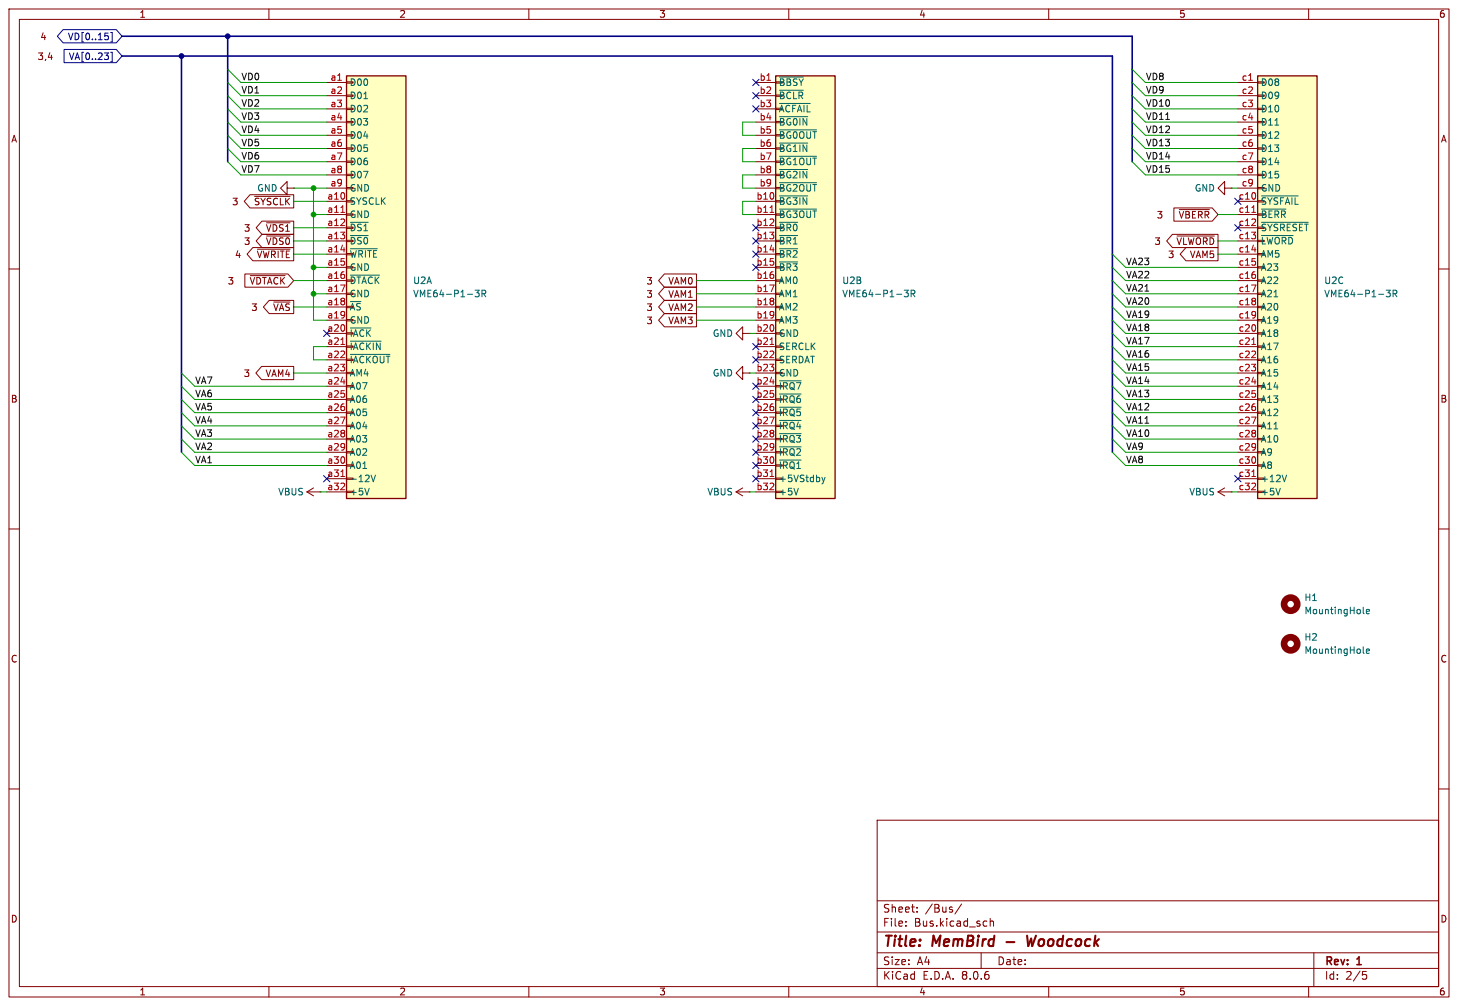
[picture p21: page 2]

File: Bus.kicad_sch Sheet: /Bus/
Id: 2/5 Title: MemBird - Woodcock

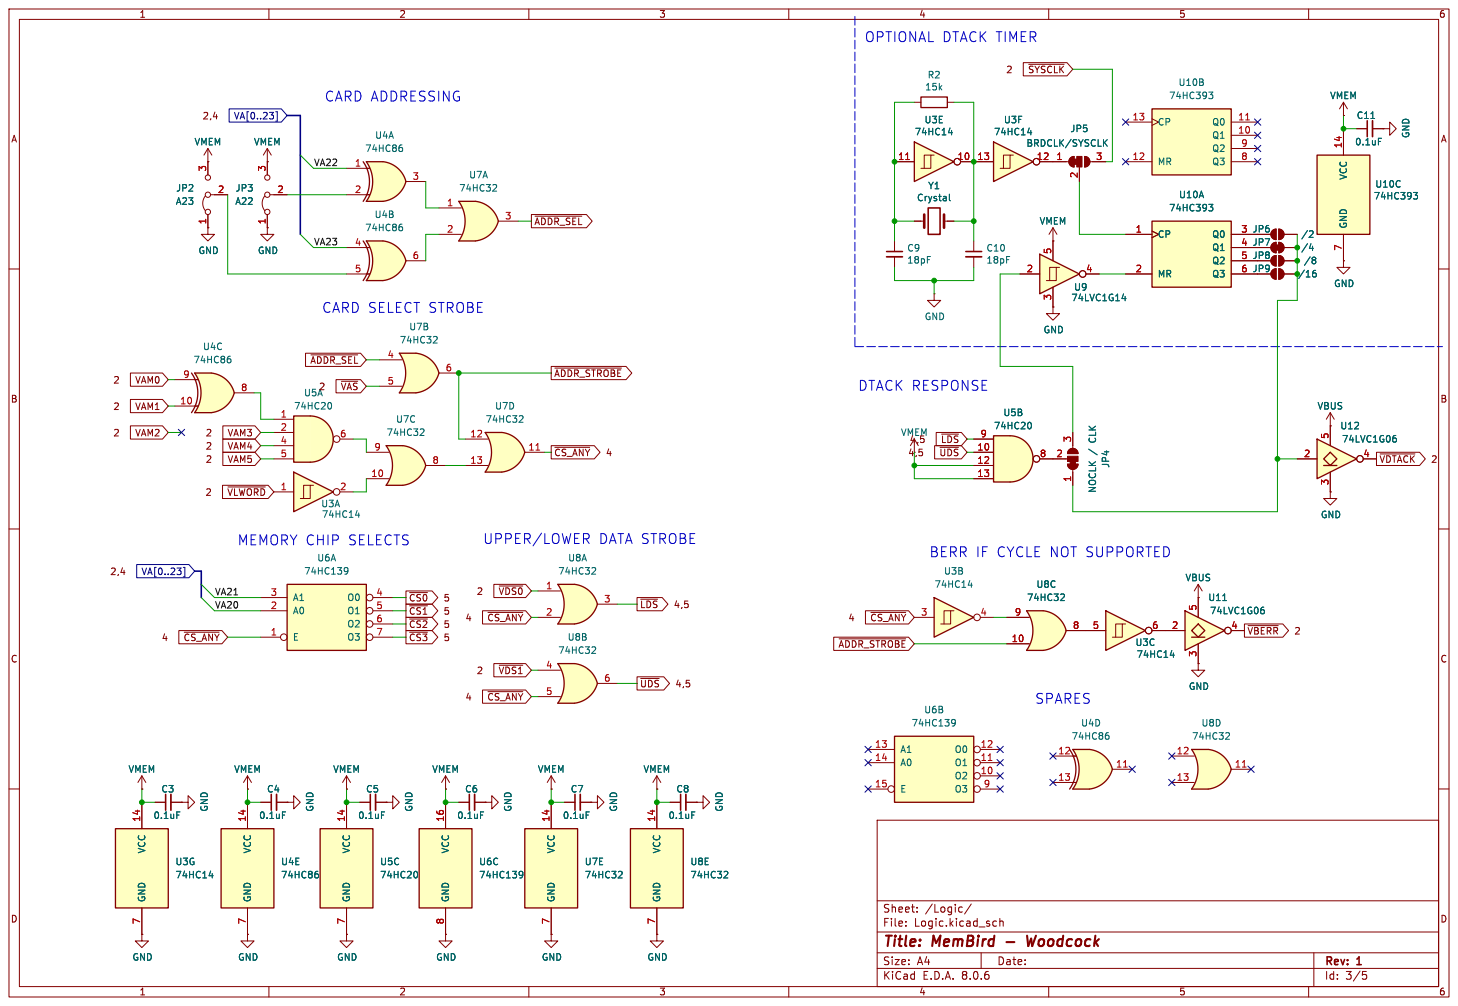
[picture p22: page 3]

UPPER/LOWER DATA STROBE

BERR IF CYCLE NOT SUPPORTED

File: Logic.kicad_sch Sheet: /Logic/
Id: 3/5 Title: MemBird - Woodcock

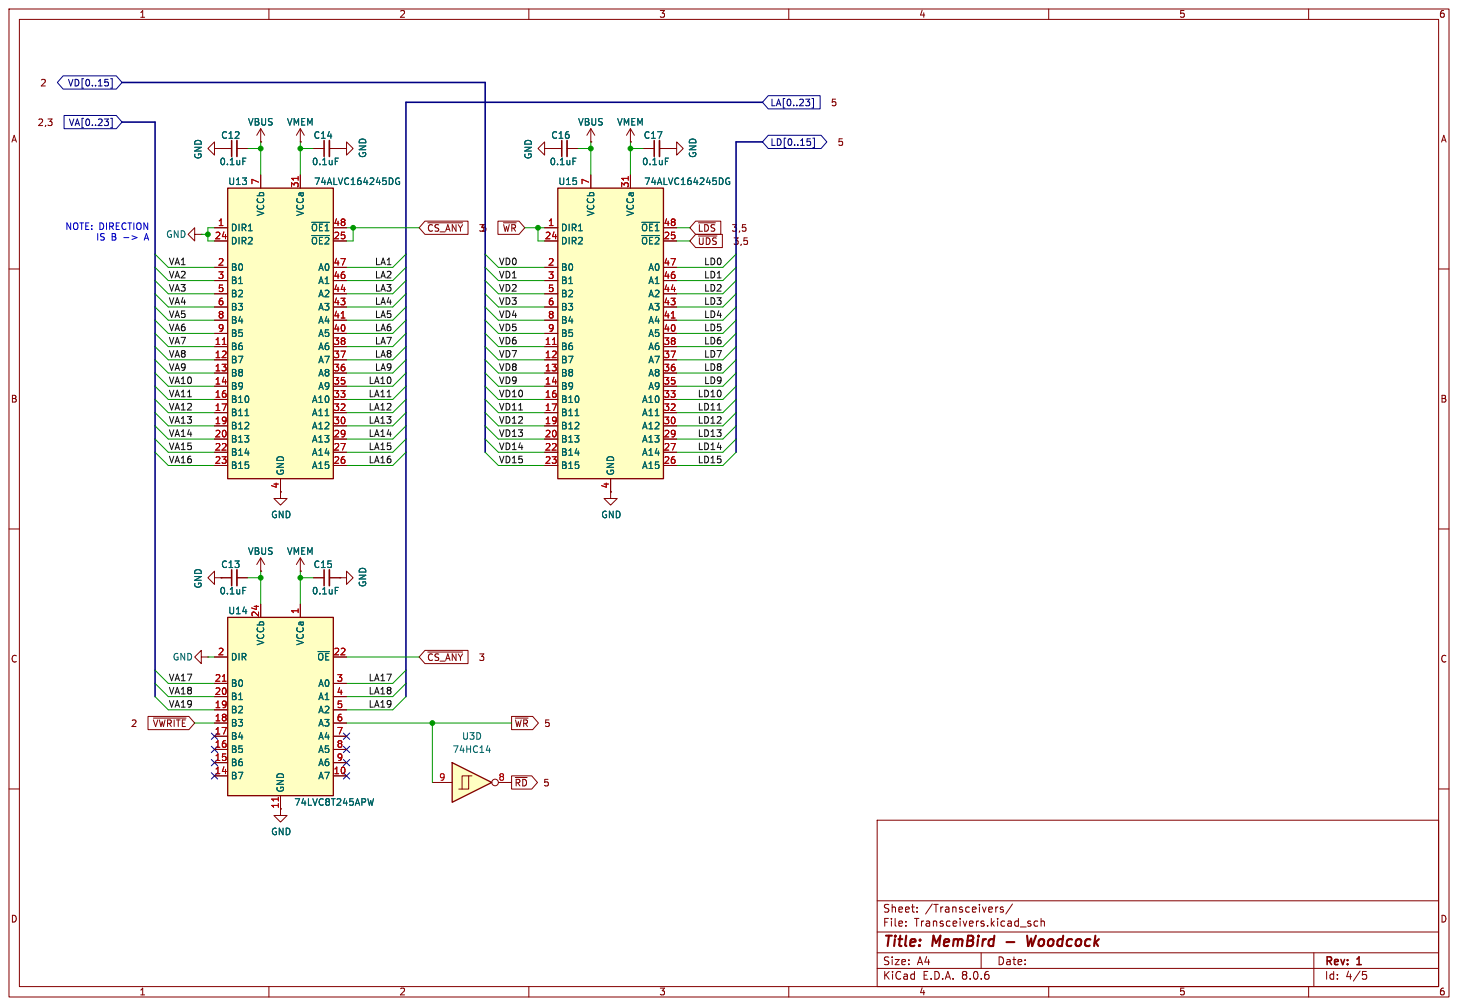
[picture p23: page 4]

1 A7 10 GND 11 B7 14 B6 15 B5 16 B4 17 B3 18 B2 19 DIR 2 B1 20 B0 21 ~{OE} 22 VCCb 24 A0 3 A1 4 A2 5 A3 6 A4 7 A5 8 A6 9 U14

1 A7 10 GND 11 B7 14 B6 15 B5 16 B4 17 B3 18 B2 19 DIR 2 B1 20 B0 21 ~{OE} 22 VCCb 24 A0 3 A1 4 A2 5 A3 6 A4 7 A5 8 A6 9 GND

File: Transceivers.kicad_sch Sheet: /Transceivers/
Id: 4/5 Title: MemBird - Woodcock

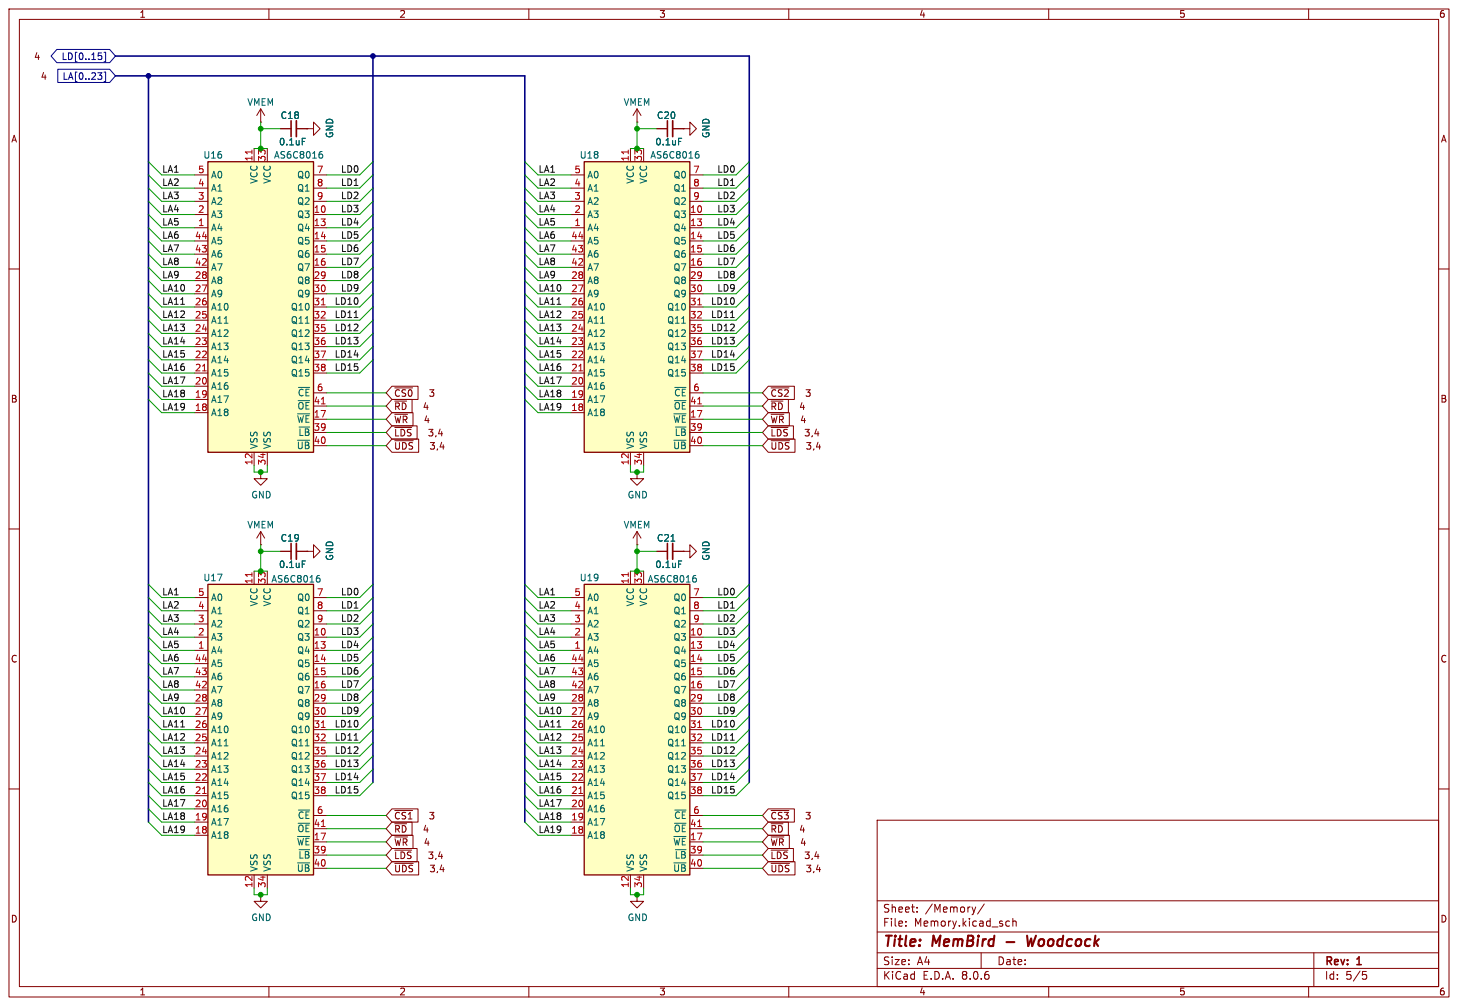
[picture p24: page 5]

Id: 5/5 Title: MemBird - Woodcock

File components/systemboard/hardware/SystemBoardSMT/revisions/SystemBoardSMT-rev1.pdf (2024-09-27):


Bus File: Bus.kicad_sch Y1 Crystal GND

File: SystemBoardSMT.kicad_sch Sheet: /
Id: 1/2 Title: VME SystemBoard


File: Bus.kicad_sch Sheet: /Bus/
Id: 2/2 Title: VME SystemBoard

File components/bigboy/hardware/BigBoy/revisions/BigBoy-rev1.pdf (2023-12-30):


Low ESR POWER SUPPLY
JP1 BOOT R7

Bus File: Bus.kicad_sch Controller File: Controller.kicad_sch

H1 MountingHole H2 MountingHole S1 Symbol:OSHW-Symbol_6.7x6mm_SilkScreen GND

File: IO.kicad_sch Transceivers File: Transceivers.kicad_sch

PROGRAMMING CONNECTOR POWER & RESET


File: Controller.kicad_sch Sheet: /Controller/
Id: 2/5 Title: BigBoy


LED2/~{INTSEL}2 TXN 20 TXP 21 RXN 22 RXP 23 RBIAS 24 VSS 25

1 RXER/PHYAD0 10 CRS_DV/MODE2 11 MDIO 12 MDC 13 ~{INT}/REFCLKO 14 ~{RST} 15 TXEN 16 TXD0 17 TXD1 18 VDD1A 19

CTS MicroSD CARD SLOT

File: IO.kicad_sch Sheet: /IO/
Id: 3/5 Title: BigBoy


File: Transceivers.kicad_sch Sheet: /Transceivers/ C38


D00 a1 SYSCLK a10 GND a11 ~{DS1} a12 ~{DS0} a13 ~{WRITE} a14 GND a15 ~{DTACK} a16 GND a17 ~{AS} a18 GND a19 D01 a2 ~{IACK} a20 ~{IACKIN} a21 ~{IACKOUT} a22 AM4 a23 A07 a24 A06 a25 A05 a26 A04 a27 A03 a28 A02 a29 D02 a3 A01 a30

File: Bus.kicad_sch Sheet: /Bus/ +5V

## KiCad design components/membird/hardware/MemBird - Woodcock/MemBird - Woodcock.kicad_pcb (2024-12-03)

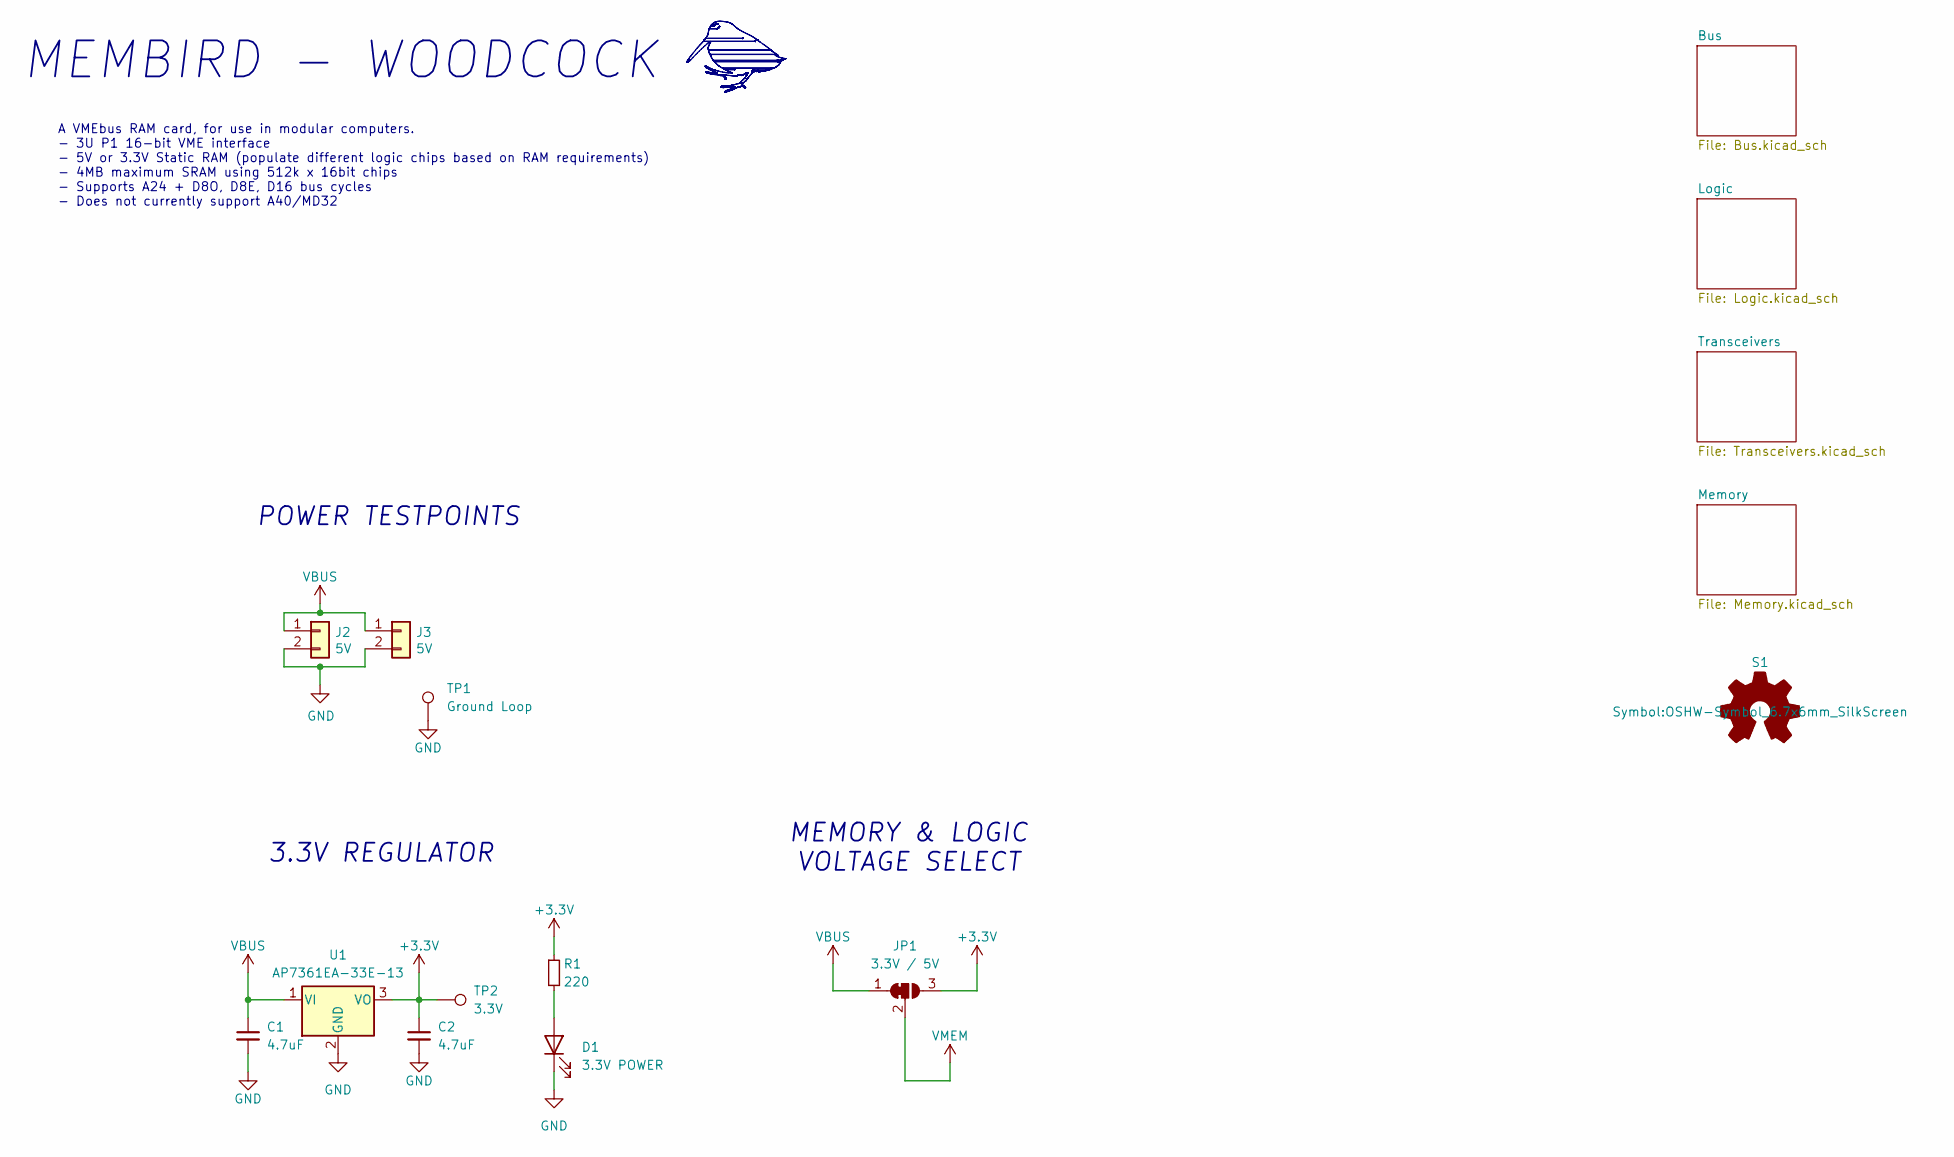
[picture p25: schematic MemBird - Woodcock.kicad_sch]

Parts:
C1, C2: 4.7uF; C_1206_3216Metric_Pad1.33x1.80mm_HandSolder
D1: 3.3V POWER; LED_PLCC-2_3.4x3.0mm_KA
J2, J3: 5V; PinHeader_1x02_P2.54mm_Vertical
JP1: 3.3V / 5V; SolderJumper-3_P1.3mm_Bridged12_RoundedPad1.0x1.5mm_NumberL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
R1: 220; R_0805_2012Metric_Pad1.20x1.40mm_HandSolder
S1: Logo_Open_Hardware_Small; OSHW-Symbol_6.7x6mm_SilkScreen
TP1: Ground Loop; TestPoint_Loop_D2.60mm_Drill1.6mm_Beaded
TP2: 3.3V; TestPoint_THTPad_2.0x2.0mm_Drill1.0mm
U1: AP7361EA-33E-13; SOT-223

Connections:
+3.3V: C2.1, JP1.3 (B), R1.1, TP2.1, U1.3 (VO)
GND: C1.2, C2.2, D1.1 (K), J2.2, J3.2, TP1.1, U1.2 (GND); also elsewhere on the board
unnamed: D1.2 (A), R1.2
VBUS: C1.1, J2.1, J3.1, JP1.1 (A), U1.1 (VI); also elsewhere on the board
VMEM: JP1.2 (C); also elsewhere on the board

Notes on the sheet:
MEMBIRD - WOODCOCK
A VMEbus RAM card, for use in modular computers. - 3U P1 16-bit VME interface - 5V or 3.3V Static RAM (populate different logic chips based on RAM requirements) - 4MB maximum SRAM using 512k x 16bit chips - Supports A24 + D8O, D8E, D16 bus cycles - Does not currently support A40/MD32
3.3V REGULATOR
POWER TESTPOINTS
MEMORY & LOGIC VOLTAGE SELECT

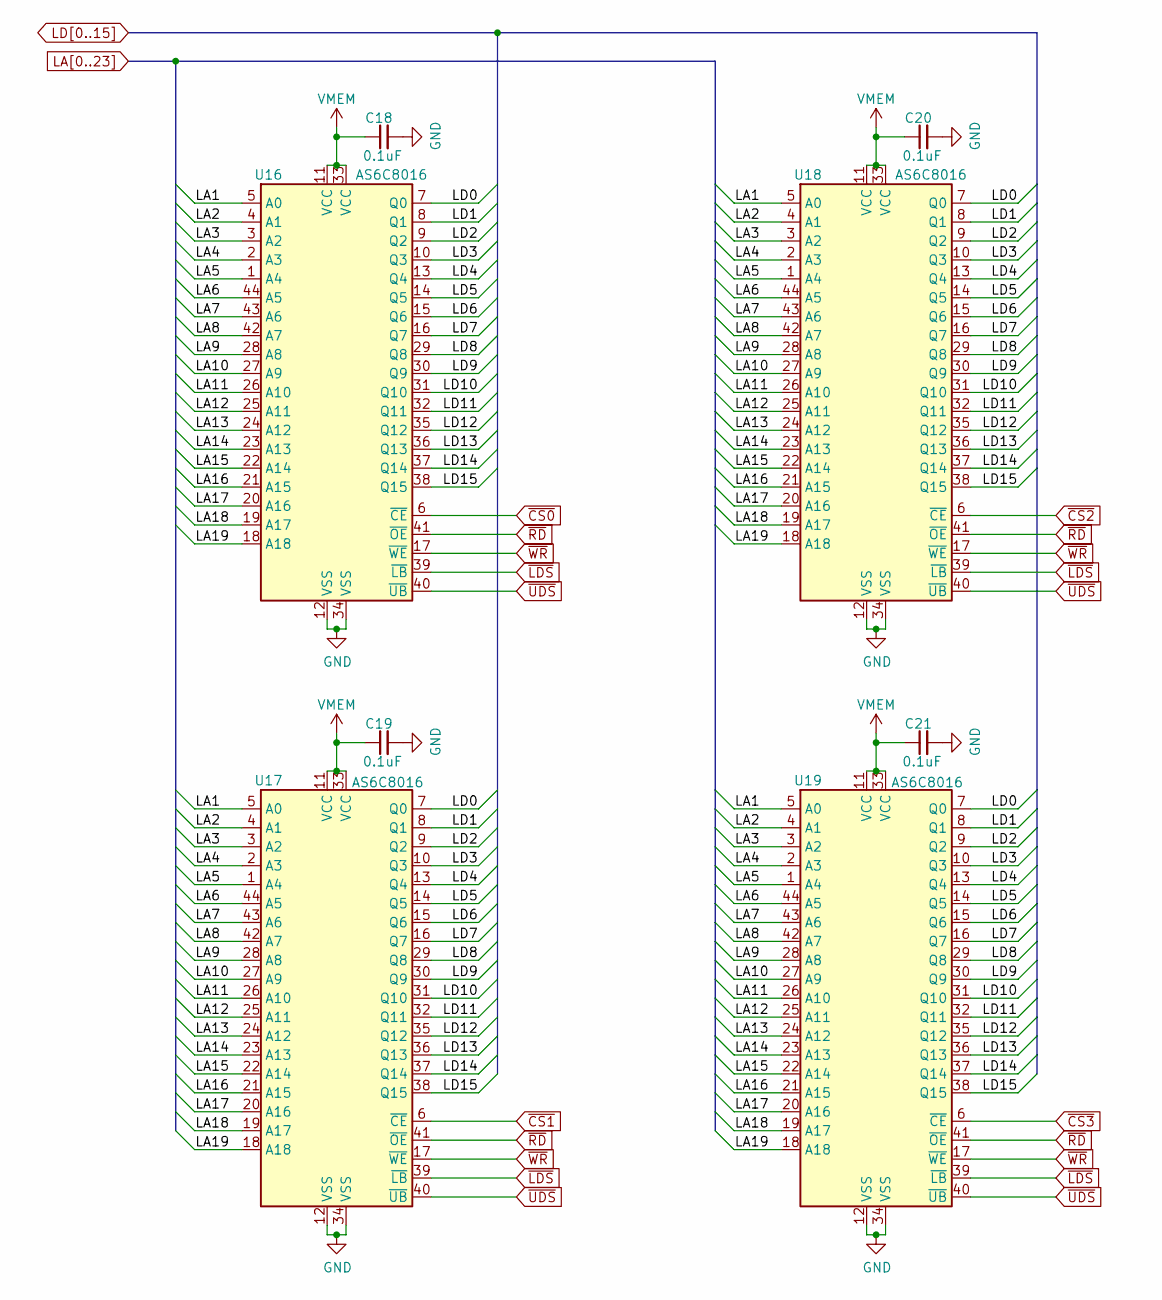
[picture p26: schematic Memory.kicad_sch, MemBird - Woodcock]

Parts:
C18, C19, C20, C21: 0.1uF; C_0805_2012Metric_Pad1.18x1.45mm_HandSolder
U16, U17, U18, U19: AS6C8016; TSOP-II-44_10.16x18.41mm_P0.8mm

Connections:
GND: C18.2, C19.2, C20.2, C21.2, U16.12 (VSS), U16.34 (VSS), U17.12 (VSS), U17.34 (VSS), U18.12 (VSS), U18.34 (VSS), U19.12 (VSS), U19.34 (VSS); also elsewhere on the board
LA1: U16.5 (A0), U17.5 (A0), U18.5 (A0), U19.5 (A0); also elsewhere on the board
LA2: U16.4 (A1), U17.4 (A1), U18.4 (A1), U19.4 (A1); also elsewhere on the board
LA3: U16.3 (A2), U17.3 (A2), U18.3 (A2), U19.3 (A2); also elsewhere on the board
LA4: U16.2 (A3), U17.2 (A3), U18.2 (A3), U19.2 (A3); also elsewhere on the board
LA5: U16.1 (A4), U17.1 (A4), U18.1 (A4), U19.1 (A4); also elsewhere on the board
LA6: U16.44 (A5), U17.44 (A5), U18.44 (A5), U19.44 (A5); also elsewhere on the board
LA7: U16.43 (A6), U17.43 (A6), U18.43 (A6), U19.43 (A6); also elsewhere on the board
LA8: U16.42 (A7), U17.42 (A7), U18.42 (A7), U19.42 (A7); also elsewhere on the board
LA9: U16.28 (A8), U17.28 (A8), U18.28 (A8), U19.28 (A8); also elsewhere on the board
LA10: U16.27 (A9), U17.27 (A9), U18.27 (A9), U19.27 (A9); also elsewhere on the board
LA11: U16.26 (A10), U17.26 (A10), U18.26 (A10), U19.26 (A10); also elsewhere on the board
LA12: U16.25 (A11), U17.25 (A11), U18.25 (A11), U19.25 (A11); also elsewhere on the board
LA13: U16.24 (A12), U17.24 (A12), U18.24 (A12), U19.24 (A12); also elsewhere on the board
LA14: U16.23 (A13), U17.23 (A13), U18.23 (A13), U19.23 (A13); also elsewhere on the board
LA15: U16.22 (A14), U17.22 (A14), U18.22 (A14), U19.22 (A14); also elsewhere on the board
LA16: U16.21 (A15), U17.21 (A15), U18.21 (A15), U19.21 (A15); also elsewhere on the board
LA17: U16.20 (A16), U17.20 (A16), U18.20 (A16), U19.20 (A16); also elsewhere on the board
LA18: U16.19 (A17), U17.19 (A17), U18.19 (A17), U19.19 (A17); also elsewhere on the board
LA19: U16.18 (A18), U17.18 (A18), U18.18 (A18), U19.18 (A18); also elsewhere on the board
LD0: U16.7 (Q0), U17.7 (Q0), U18.7 (Q0), U19.7 (Q0); also elsewhere on the board
LD1: U16.8 (Q1), U17.8 (Q1), U18.8 (Q1), U19.8 (Q1); also elsewhere on the board
LD2: U16.9 (Q2), U17.9 (Q2), U18.9 (Q2), U19.9 (Q2); also elsewhere on the board
LD3: U16.10 (Q3), U17.10 (Q3), U18.10 (Q3), U19.10 (Q3); also elsewhere on the board
LD4: U16.13 (Q4), U17.13 (Q4), U18.13 (Q4), U19.13 (Q4); also elsewhere on the board
LD5: U16.14 (Q5), U17.14 (Q5), U18.14 (Q5), U19.14 (Q5); also elsewhere on the board
LD6: U16.15 (Q6), U17.15 (Q6), U18.15 (Q6), U19.15 (Q6); also elsewhere on the board
LD7: U16.16 (Q7), U17.16 (Q7), U18.16 (Q7), U19.16 (Q7); also elsewhere on the board
LD8: U16.29 (Q8), U17.29 (Q8), U18.29 (Q8), U19.29 (Q8); also elsewhere on the board
LD9: U16.30 (Q9), U17.30 (Q9), U18.30 (Q9), U19.30 (Q9); also elsewhere on the board
LD10: U16.31 (Q10), U17.31 (Q10), U18.31 (Q10), U19.31 (Q10); also elsewhere on the board
LD11: U16.32 (Q11), U17.32 (Q11), U18.32 (Q11), U19.32 (Q11); also elsewhere on the board
LD12: U16.35 (Q12), U17.35 (Q12), U18.35 (Q12), U19.35 (Q12); also elsewhere on the board
LD13: U16.36 (Q13), U17.36 (Q13), U18.36 (Q13), U19.36 (Q13); also elsewhere on the board
LD14: U16.37 (Q14), U17.37 (Q14), U18.37 (Q14), U19.37 (Q14); also elsewhere on the board
LD15: U16.38 (Q15), U17.38 (Q15), U18.38 (Q15), U19.38 (Q15); also elsewhere on the board
VMEM: C18.1, C19.1, C20.1, C21.1, U16.11 (VCC), U16.33 (VCC), U17.11 (VCC), U17.33 (VCC), U18.11 (VCC), U18.33 (VCC), U19.11 (VCC), U19.33 (VCC); also elsewhere on the board
~CS0: U16.6 (~CE); also elsewhere on the board
~CS1: U17.6 (~CE); also elsewhere on the board
~CS2: U18.6 (~CE); also elsewhere on the board
~CS3: U19.6 (~CE); also elsewhere on the board
~LDS: U16.39 (~LB), U17.39 (~LB), U18.39 (~LB), U19.39 (~LB); also elsewhere on the board
~RD: U16.41 (~OE), U17.41 (~OE), U18.41 (~OE), U19.41 (~OE); also elsewhere on the board
~UDS: U16.40 (~UB), U17.40 (~UB), U18.40 (~UB), U19.40 (~UB); also elsewhere on the board
~WR: U16.17 (~WE), U17.17 (~WE), U18.17 (~WE), U19.17 (~WE); also elsewhere on the board

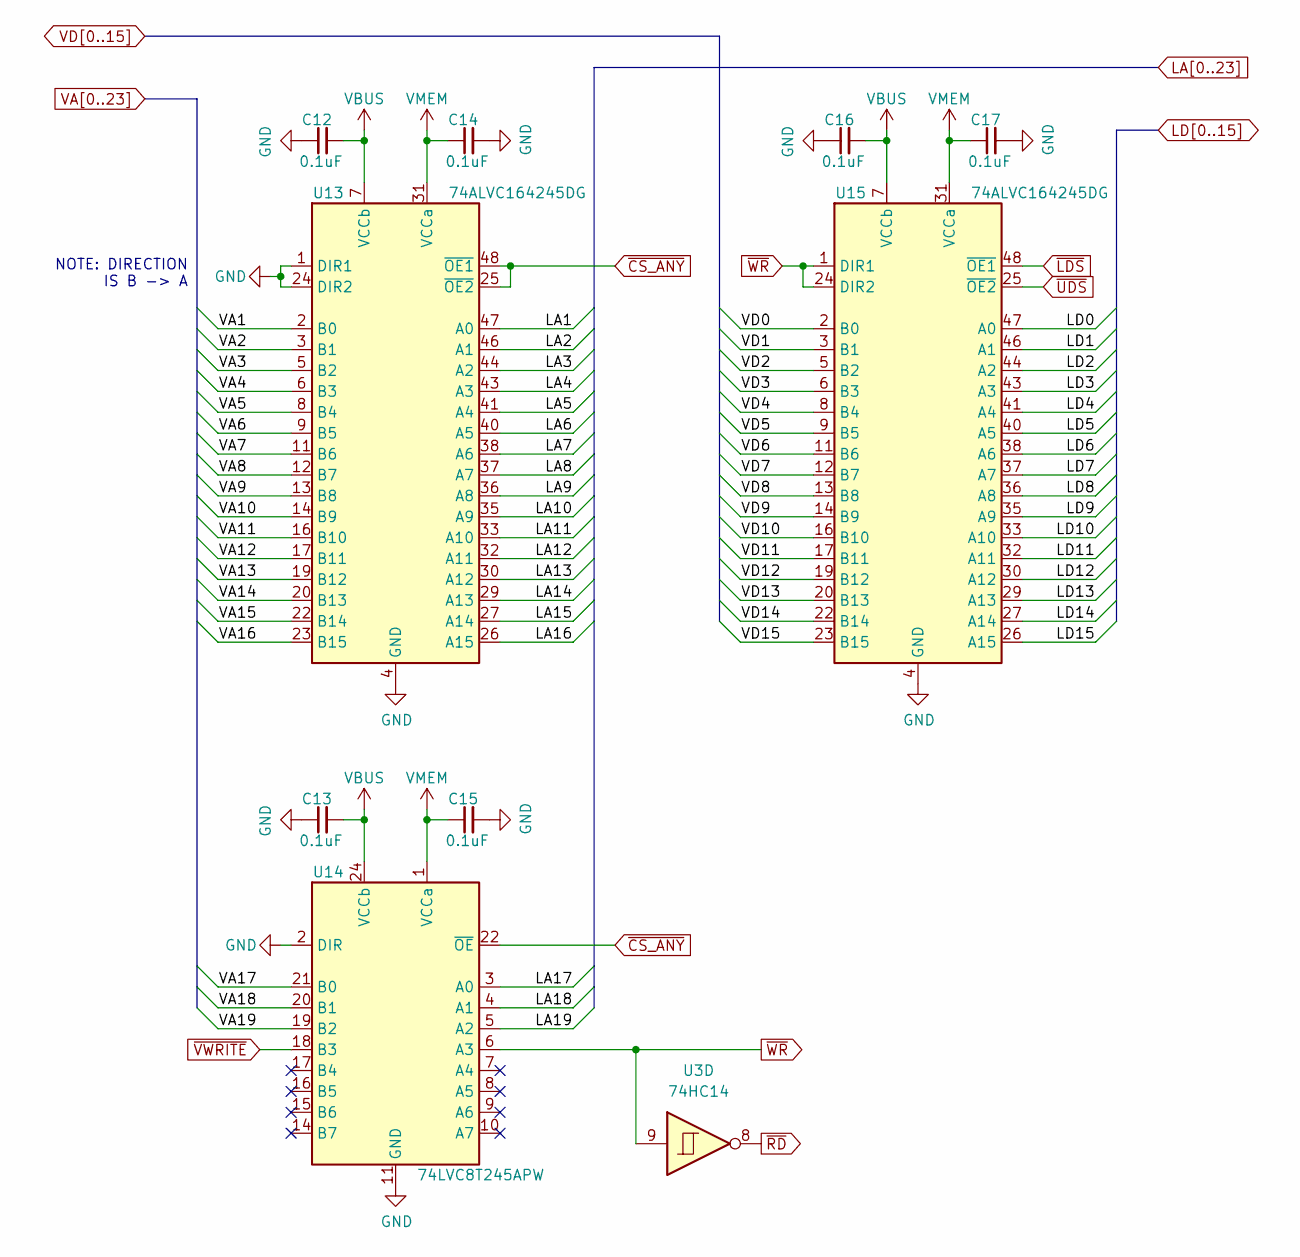
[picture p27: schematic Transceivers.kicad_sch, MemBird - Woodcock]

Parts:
C12, C13, C14, C15, C16, C17: 0.1uF; C_0805_2012Metric_Pad1.18x1.45mm_HandSolder
U3: 74HC14; TSSOP-14_4.4x5mm_P0.65mm
U13, U15: 74ALVC164245DG; TSSOP-48_6.1x12.5mm_P0.5mm
U14: 74LVC8T245APW; TSSOP-24_4.4x7.8mm_P0.65mm

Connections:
GND: C12.1, C13.1, C14.2, C15.2, C16.1, C17.2, U13.1 (DIR1), U13.4 (GND), U13.10 (GND), U13.15 (GND), U13.21 (GND), U13.24 (DIR2), U13.28 (GND), U13.34 (GND), U13.39 (GND), U13.45 (GND), U14.2 (DIR), U14.11 (GND), U14.12 (GND), U14.13 (GND), U15.4 (GND), U15.10 (GND), U15.15 (GND), U15.21 (GND), U15.28 (GND), U15.34 (GND), U15.39 (GND), U15.45 (GND); also elsewhere on the board
LA1: U13.47 (A0); also elsewhere on the board
LA2: U13.46 (A1); also elsewhere on the board
LA3: U13.44 (A2); also elsewhere on the board
LA4: U13.43 (A3); also elsewhere on the board
LA5: U13.41 (A4); also elsewhere on the board
LA6: U13.40 (A5); also elsewhere on the board
LA7: U13.38 (A6); also elsewhere on the board
LA8: U13.37 (A7); also elsewhere on the board
LA9: U13.36 (A8); also elsewhere on the board
LA10: U13.35 (A9); also elsewhere on the board
LA11: U13.33 (A10); also elsewhere on the board
LA12: U13.32 (A11); also elsewhere on the board
LA13: U13.30 (A12); also elsewhere on the board
LA14: U13.29 (A13); also elsewhere on the board
LA15: U13.27 (A14); also elsewhere on the board
LA16: U13.26 (A15); also elsewhere on the board
LA17: U14.3 (A0); also elsewhere on the board
LA18: U14.4 (A1); also elsewhere on the board
LA19: U14.5 (A2); also elsewhere on the board
LD0: U15.47 (A0); also elsewhere on the board
LD1: U15.46 (A1); also elsewhere on the board
LD2: U15.44 (A2); also elsewhere on the board
LD3: U15.43 (A3); also elsewhere on the board
LD4: U15.41 (A4); also elsewhere on the board
LD5: U15.40 (A5); also elsewhere on the board
LD6: U15.38 (A6); also elsewhere on the board
LD7: U15.37 (A7); also elsewhere on the board
LD8: U15.36 (A8); also elsewhere on the board
LD9: U15.35 (A9); also elsewhere on the board
LD10: U15.33 (A10); also elsewhere on the board
LD11: U15.32 (A11); also elsewhere on the board
LD12: U15.30 (A12); also elsewhere on the board
LD13: U15.29 (A13); also elsewhere on the board
LD14: U15.27 (A14); also elsewhere on the board
LD15: U15.26 (A15); also elsewhere on the board
VA1: U13.2 (B0); also elsewhere on the board
VA2: U13.3 (B1); also elsewhere on the board
VA3: U13.5 (B2); also elsewhere on the board
VA4: U13.6 (B3); also elsewhere on the board
VA5: U13.8 (B4); also elsewhere on the board
VA6: U13.9 (B5); also elsewhere on the board
VA7: U13.11 (B6); also elsewhere on the board
VA8: U13.12 (B7); also elsewhere on the board
VA9: U13.13 (B8); also elsewhere on the board
VA10: U13.14 (B9); also elsewhere on the board
VA11: U13.16 (B10); also elsewhere on the board
VA12: U13.17 (B11); also elsewhere on the board
VA13: U13.19 (B12); also elsewhere on the board
VA14: U13.20 (B13); also elsewhere on the board
VA15: U13.22 (B14); also elsewhere on the board
VA16: U13.23 (B15); also elsewhere on the board
VA17: U14.21 (B0); also elsewhere on the board
VA18: U14.20 (B1); also elsewhere on the board
VA19: U14.19 (B2); also elsewhere on the board
VBUS: C12.2, C13.2, C16.2, U13.7 (VCCb), U13.18 (VCCb), U14.23 (VCCb), U14.24 (VCCb), U15.7 (VCCb), U15.18 (VCCb); also elsewhere on the board
VD0: U15.2 (B0); also elsewhere on the board
VD1: U15.3 (B1); also elsewhere on the board
VD2: U15.5 (B2); also elsewhere on the board
VD3: U15.6 (B3); also elsewhere on the board
VD4: U15.8 (B4); also elsewhere on the board
VD5: U15.9 (B5); also elsewhere on the board
VD6: U15.11 (B6); also elsewhere on the board
VD7: U15.12 (B7); also elsewhere on the board
VD8: U15.13 (B8); also elsewhere on the board
VD9: U15.14 (B9); also elsewhere on the board
VD10: U15.16 (B10); also elsewhere on the board
VD11: U15.17 (B11); also elsewhere on the board
VD12: U15.19 (B12); also elsewhere on the board
VD13: U15.20 (B13); also elsewhere on the board
VD14: U15.22 (B14); also elsewhere on the board
VD15: U15.23 (B15); also elsewhere on the board
VMEM: C14.1, C15.1, C17.1, U13.31 (VCCa), U13.42 (VCCa), U14.1 (VCCa), U15.31 (VCCa), U15.42 (VCCa); also elsewhere on the board
~CS_ANY: U13.25 (~OE2), U13.48 (~OE1), U14.22 (~OE); also elsewhere on the board
~LDS: U15.48 (~OE1); also elsewhere on the board
~RD: U3.8; also elsewhere on the board
~UDS: U15.25 (~OE2); also elsewhere on the board
~VWRITE: U14.18 (B3); also elsewhere on the board
~WR: U3.9, U14.6 (A3), U15.1 (DIR1), U15.24 (DIR2); also elsewhere on the board

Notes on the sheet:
NOTE: DIRECTION IS B -> A

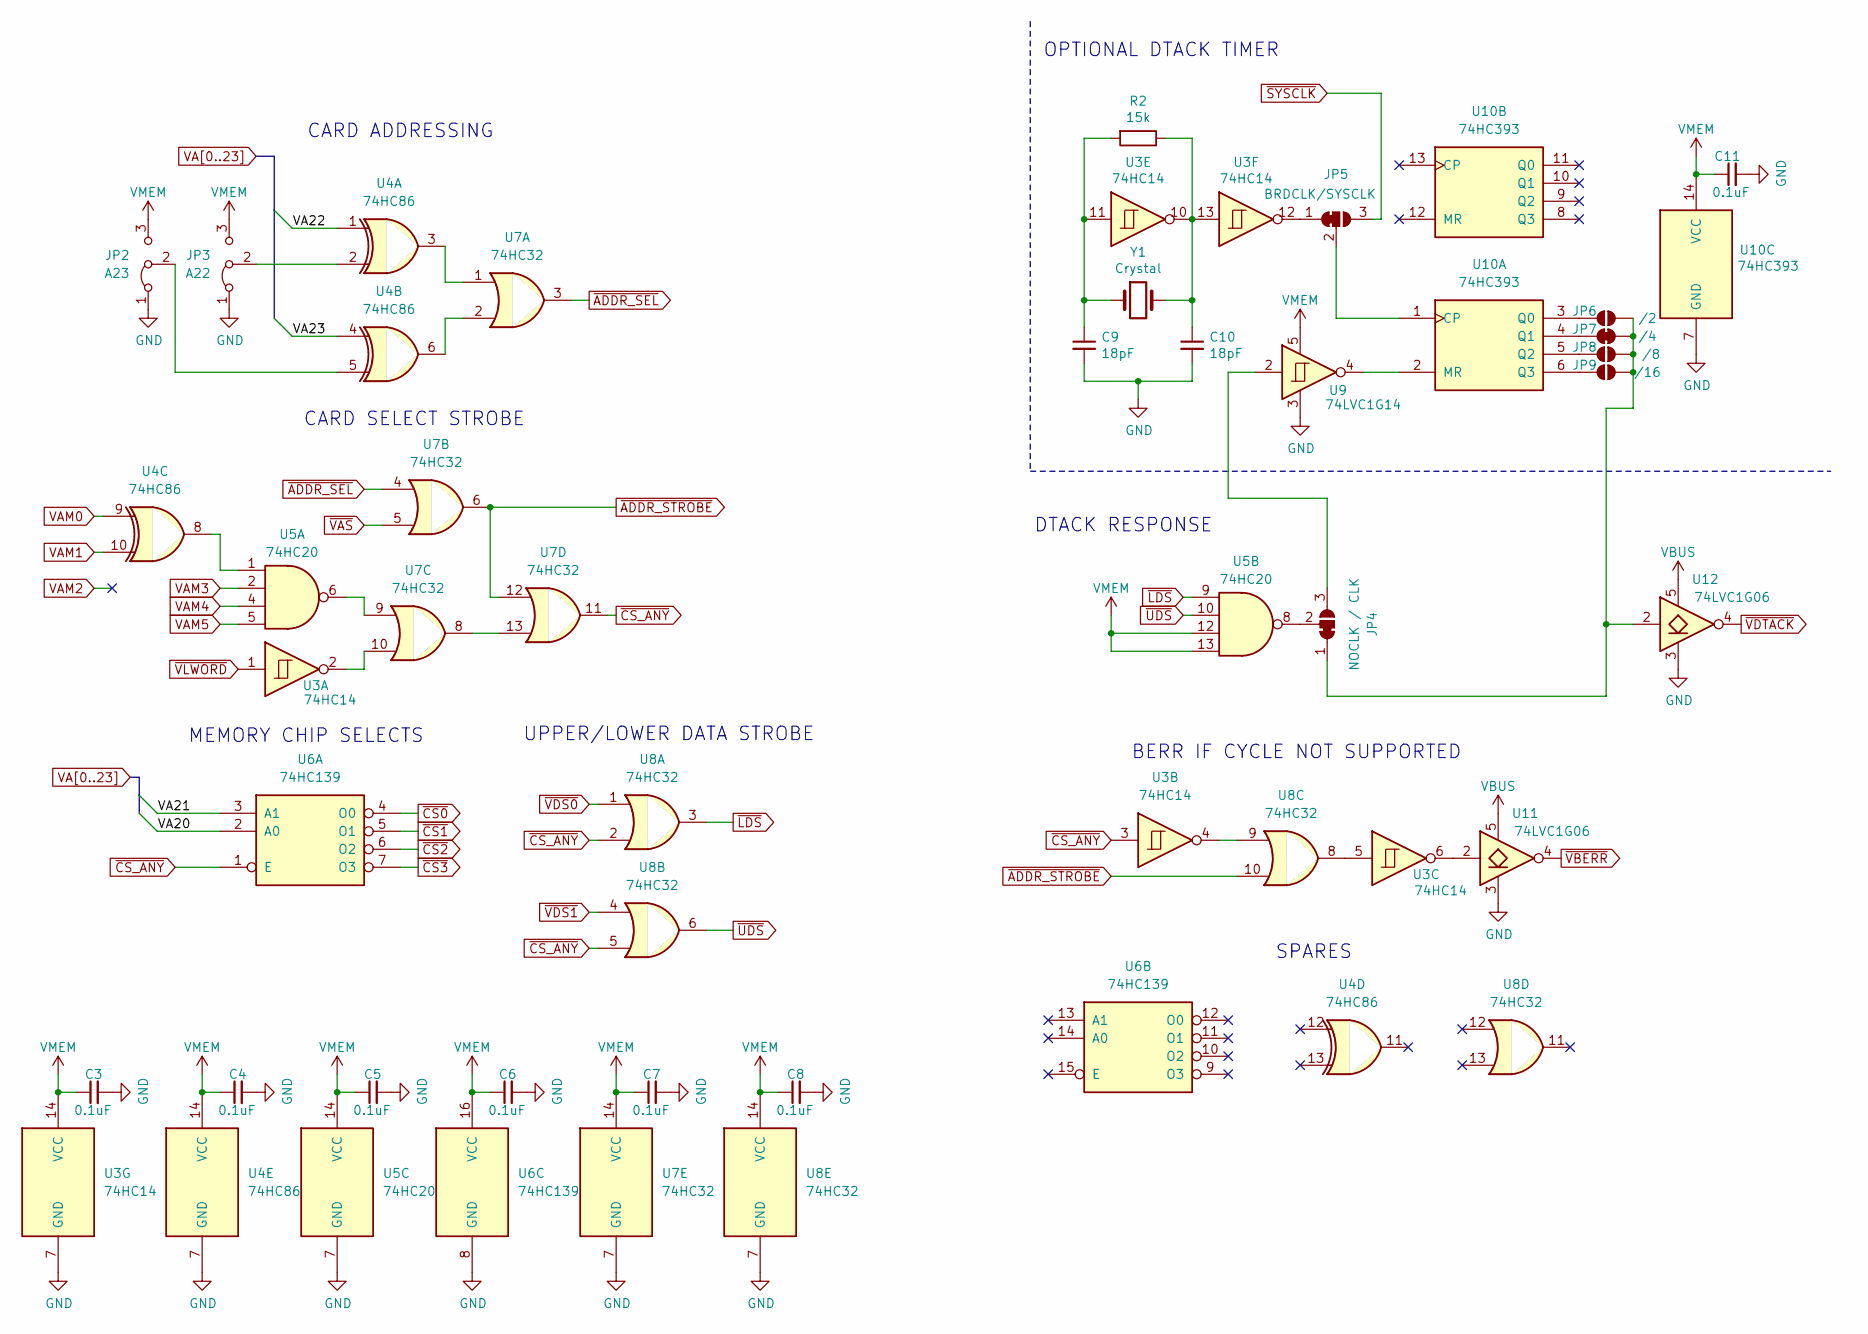
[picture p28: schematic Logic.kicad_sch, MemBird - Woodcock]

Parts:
C3, C4, C5, C6, C7, C8, C11: 0.1uF; C_0805_2012Metric_Pad1.18x1.45mm_HandSolder
C9, C10: 18pF; C_Disc_D3.0mm_W2.0mm_P2.50mm
JP2: A23; PinHeader_1x03_P2.54mm_Vertical
JP3: A22; PinHeader_1x03_P2.54mm_Vertical
JP4: NOCLK / CLK; SolderJumper-3_P1.3mm_Bridged12_RoundedPad1.0x1.5mm_NumberL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
JP5: BRDCLK/SYSCLK; SolderJumper-3_P1.3mm_Bridged12_RoundedPad1.0x1.5mm_NumberL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
JP6: /2; SolderJumper-2_P1.3mm_Open_RoundedPad1.0x1.5mm
JP7: /4; SolderJumper-2_P1.3mm_Bridged_RoundedPad1.0x1.5mm
JP8: /8; SolderJumper-2_P1.3mm_Open_RoundedPad1.0x1.5mm
JP9: /16; SolderJumper-2_P1.3mm_Open_RoundedPad1.0x1.5mm
R2: 15k; R_0805_2012Metric_Pad1.20x1.40mm_HandSolder
U3: 74HC14; TSSOP-14_4.4x5mm_P0.65mm
U4: 74HC86; TSSOP-14_4.4x5mm_P0.65mm
U5: 74HC20; TSSOP-14_4.4x5mm_P0.65mm
U6: 74HC139; TSSOP-16_4.4x5mm_P0.65mm
U7, U8: 74HC32; TSSOP-14_4.4x5mm_P0.65mm
U9: 74LVC1G14; SOT-353_SC-70-5_Handsoldering
U10: 74HC393; TSSOP-14_4.4x5mm_P0.65mm
U11, U12: 74LVC1G06; SOT-353_SC-70-5_Handsoldering
Y1: Crystal; Crystal_HC49-4H_Vertical

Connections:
GND: C3.2, C4.2, C5.2, C6.2, C7.2, C8.2, C9.2, C10.2, C11.2, JP2.1 (A), JP3.1 (A), U3.7 (GND), U4.7 (GND), U5.7 (GND), U6.8 (GND), U7.7 (GND), U8.7 (GND), U9.3, U10.7 (GND), U11.3, U12.3; also elsewhere on the board
unnamed: C9.1, R2.2, U3.11, Y1.1
unnamed: C10.1, R2.1, U3.10, U3.13, Y1.2
unnamed: JP2.2 (C), U4.5
unnamed: JP3.2 (C), U4.2
unnamed: JP4.1 (A), JP6.2 (B), JP7.2 (B), JP8.2 (B), JP9.2 (B), U12.2
unnamed: JP4.3 (B), U9.2
unnamed: JP4.2 (C), U5.8
unnamed: JP5.1 (A), U3.12
unnamed: JP5.2 (C), U10.1 (CP)
unnamed: JP6.1 (A), U10.3 (Q0)
unnamed: JP7.1 (A), U10.4 (Q1)
unnamed: JP8.1 (A), U10.5 (Q2)
unnamed: JP9.1 (A), U10.6 (Q3)
unnamed: U3.2, U7.10
unnamed: U3.4, U8.9
unnamed: U3.5, U8.8
unnamed: U4.3, U7.1
unnamed: U4.6, U7.2
unnamed: U4.8, U5.1
unnamed: U5.6, U7.9
unnamed: U7.8, U7.13
unnamed: U9.4, U10.2 (MR)
unnamed: U3.6, U11.2
VA20: U6.2 (A0); also elsewhere on the board
VA21: U6.3 (A1); also elsewhere on the board
VA22: U4.1; also elsewhere on the board
VA23: U4.4; also elsewhere on the board
VAM0: U4.9; also elsewhere on the board
VAM1: U4.10; also elsewhere on the board
VAM3: U5.2; also elsewhere on the board
VAM4: U5.4; also elsewhere on the board
VAM5: U5.5; also elsewhere on the board
VBUS: U11.5, U12.5; also elsewhere on the board
VMEM: C3.1, C4.1, C5.1, C6.1, C7.1, C8.1, C11.1, JP2.3 (B), JP3.3 (B), U3.14 (VCC), U4.14 (VCC), U5.12, U5.13, U5.14 (VCC), U6.16 (VCC), U7.14 (VCC), U8.14 (VCC), U9.5, U10.14 (VCC); also elsewhere on the board
~ADDR_SEL: U7.3, U7.4
~ADDR_STROBE: U7.6, U7.12, U8.10
~CS0: U6.4 (O0); also elsewhere on the board
~CS1: U6.5 (O1); also elsewhere on the board
~CS2: U6.6 (O2); also elsewhere on the board
~CS3: U6.7 (O3); also elsewhere on the board
~CS_ANY: U3.3, U6.1 (E), U7.11, U8.2, U8.5; also elsewhere on the board
~LDS: U5.9, U8.3; also elsewhere on the board
~SYSCLK: JP5.3 (B); also elsewhere on the board
~UDS: U5.10, U8.6; also elsewhere on the board
~VAS: U7.5; also elsewhere on the board
~VBERR: U11.4; also elsewhere on the board
~VDS0: U8.1; also elsewhere on the board
~VDS1: U8.4; also elsewhere on the board
~VDTACK: U12.4; also elsewhere on the board
~VLWORD: U3.1; also elsewhere on the board

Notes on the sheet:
MEMORY CHIP SELECTS
BERR IF CYCLE NOT SUPPORTED
SPARES
DTACK RESPONSE
OPTIONAL DTACK TIMER
CARD ADDRESSING
CARD SELECT STROBE
UPPER/LOWER DATA STROBE

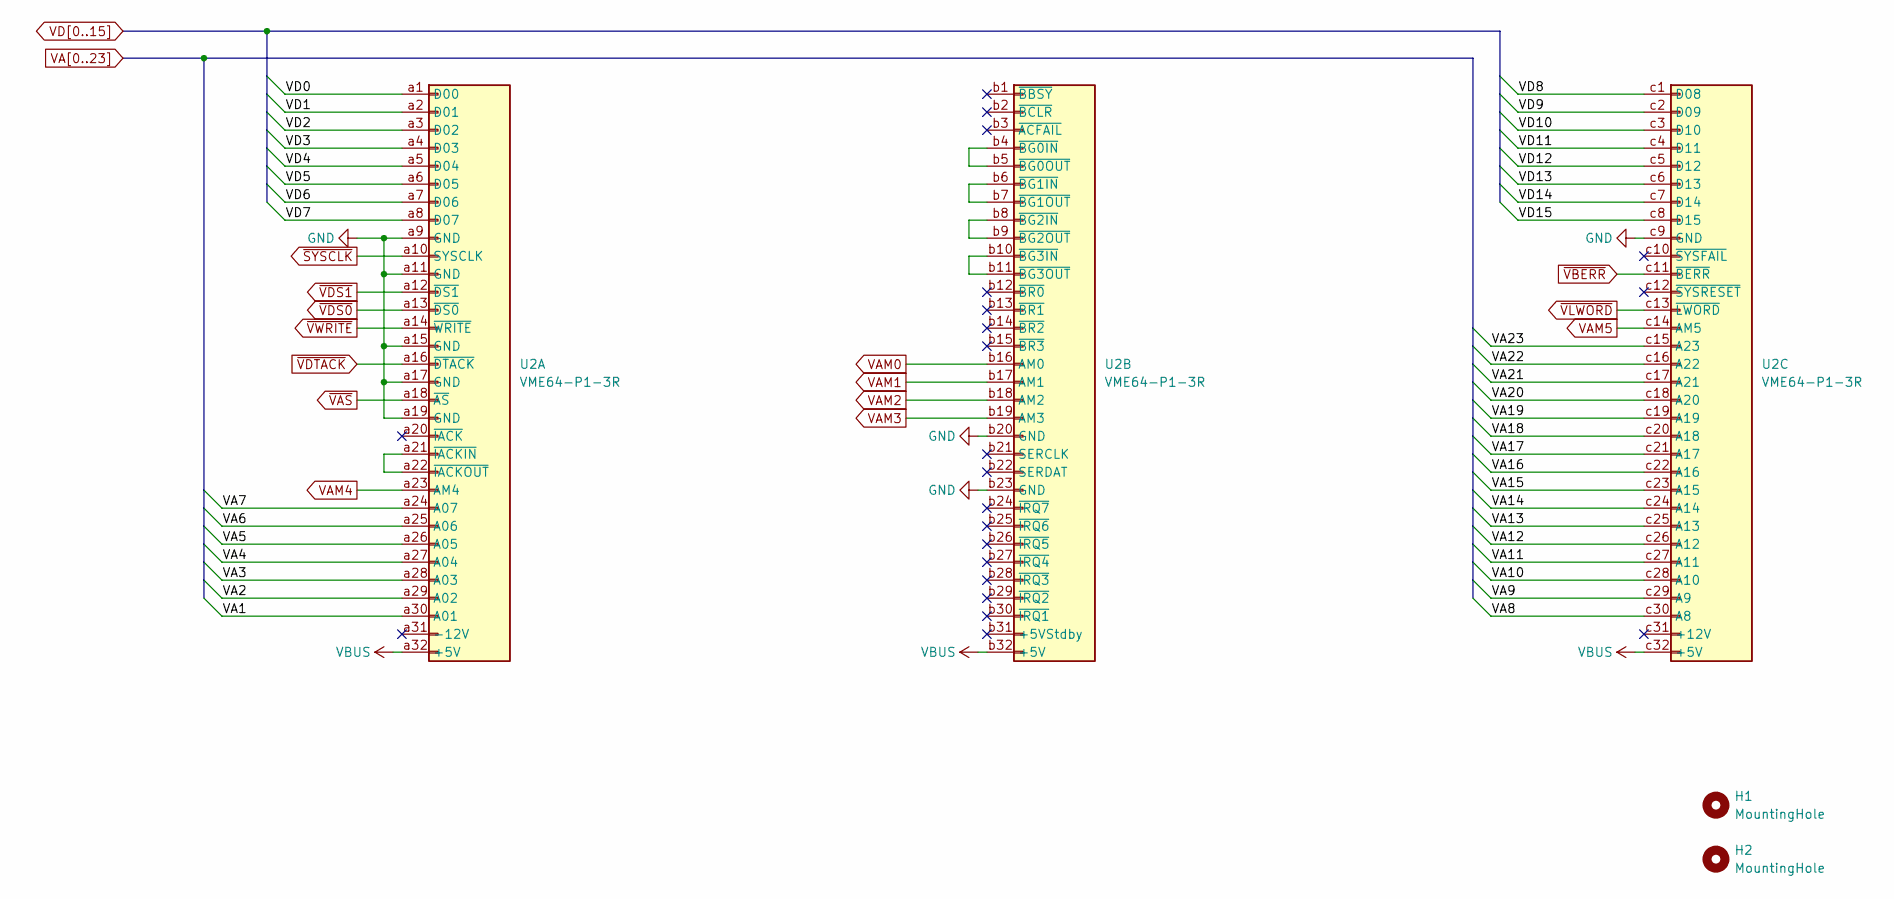
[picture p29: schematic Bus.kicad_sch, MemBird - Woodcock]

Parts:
H1, H2: MountingHole; MountingHole_2.7mm_M2.5_DIN965
U2: VME64-P1-3R; DIN41612_C_3x32_Male_Horizontal_THT

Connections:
GND: U2.a9 (GND), U2.a11 (GND), U2.a15 (GND), U2.a17 (GND), U2.a19 (GND), U2.b20 (GND), U2.b23 (GND), U2.c9 (GND); also elsewhere on the board
unnamed: U2.a21 (~IACKIN), U2.a22 (~IACKOUT)
unnamed: U2.b4 (~BG0IN), U2.b5 (~BG0OUT)
unnamed: U2.b6 (~BG1IN), U2.b7 (~BG1OUT)
unnamed: U2.b8 (~BG2IN), U2.b9 (~BG2OUT)
unnamed: U2.b10 (~BG3IN), U2.b11 (~BG3OUT)
VA1: U2.a30 (A01); also elsewhere on the board
VA2: U2.a29 (A02); also elsewhere on the board
VA3: U2.a28 (A03); also elsewhere on the board
VA4: U2.a27 (A04); also elsewhere on the board
VA5: U2.a26 (A05); also elsewhere on the board
VA6: U2.a25 (A06); also elsewhere on the board
VA7: U2.a24 (A07); also elsewhere on the board
VA8: U2.c30 (A8); also elsewhere on the board
VA9: U2.c29 (A9); also elsewhere on the board
VA10: U2.c28 (A10); also elsewhere on the board
VA11: U2.c27 (A11); also elsewhere on the board
VA12: U2.c26 (A12); also elsewhere on the board
VA13: U2.c25 (A13); also elsewhere on the board
VA14: U2.c24 (A14); also elsewhere on the board
VA15: U2.c23 (A15); also elsewhere on the board
VA16: U2.c22 (A16); also elsewhere on the board
VA17: U2.c21 (A17); also elsewhere on the board
VA18: U2.c20 (A18); also elsewhere on the board
VA19: U2.c19 (A19); also elsewhere on the board
VA20: U2.c18 (A20); also elsewhere on the board
VA21: U2.c17 (A21); also elsewhere on the board
VA22: U2.c16 (A22); also elsewhere on the board
VA23: U2.c15 (A23); also elsewhere on the board
VAM0: U2.b16 (AM0); also elsewhere on the board
VAM1: U2.b17 (AM1); also elsewhere on the board
VAM2: U2.b18 (AM2)
VAM3: U2.b19 (AM3); also elsewhere on the board
VAM4: U2.a23 (AM4); also elsewhere on the board
VAM5: U2.c14 (AM5); also elsewhere on the board
VBUS: U2.a32 (+5V), U2.b32 (+5V), U2.c32 (+5V); also elsewhere on the board
VD0: U2.a1 (D00); also elsewhere on the board
VD1: U2.a2 (D01); also elsewhere on the board
VD2: U2.a3 (D02); also elsewhere on the board
VD3: U2.a4 (D03); also elsewhere on the board
VD4: U2.a5 (D04); also elsewhere on the board
VD5: U2.a6 (D05); also elsewhere on the board
VD6: U2.a7 (D06); also elsewhere on the board
VD7: U2.a8 (D07); also elsewhere on the board
VD8: U2.c1 (D08); also elsewhere on the board
VD9: U2.c2 (D09); also elsewhere on the board
VD10: U2.c3 (D10); also elsewhere on the board
VD11: U2.c4 (D11); also elsewhere on the board
VD12: U2.c5 (D12); also elsewhere on the board
VD13: U2.c6 (D13); also elsewhere on the board
VD14: U2.c7 (D14); also elsewhere on the board
VD15: U2.c8 (D15); also elsewhere on the board
~SYSCLK: U2.a10 (SYSCLK); also elsewhere on the board
~VAS: U2.a18 (~AS); also elsewhere on the board
~VBERR: U2.c11 (~BERR); also elsewhere on the board
~VDS0: U2.a13 (~DS0); also elsewhere on the board
~VDS1: U2.a12 (~DS1); also elsewhere on the board
~VDTACK: U2.a16 (~DTACK); also elsewhere on the board
~VLWORD: U2.c13 (~LWORD); also elsewhere on the board
~VWRITE: U2.a14 (~WRITE); also elsewhere on the board

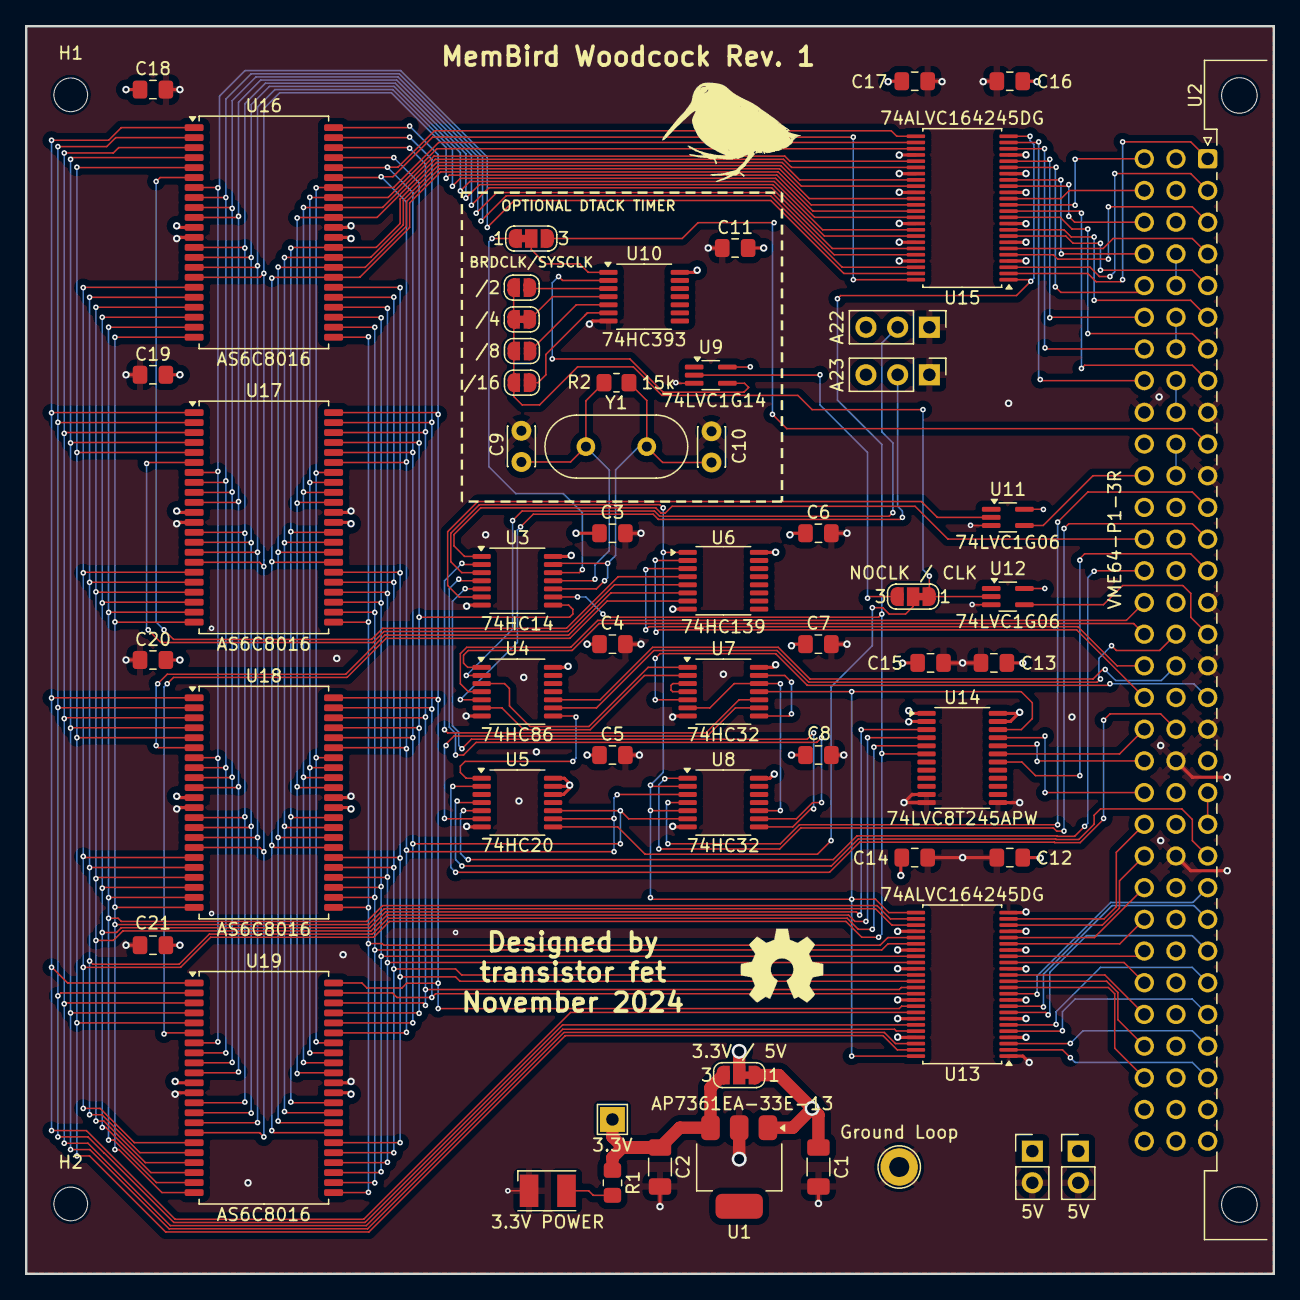
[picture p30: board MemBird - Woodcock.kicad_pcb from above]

Board: 4 copper layers, 100.0 x 100.0 mm, 60 parts (0 on the bottom side), 131 nets.

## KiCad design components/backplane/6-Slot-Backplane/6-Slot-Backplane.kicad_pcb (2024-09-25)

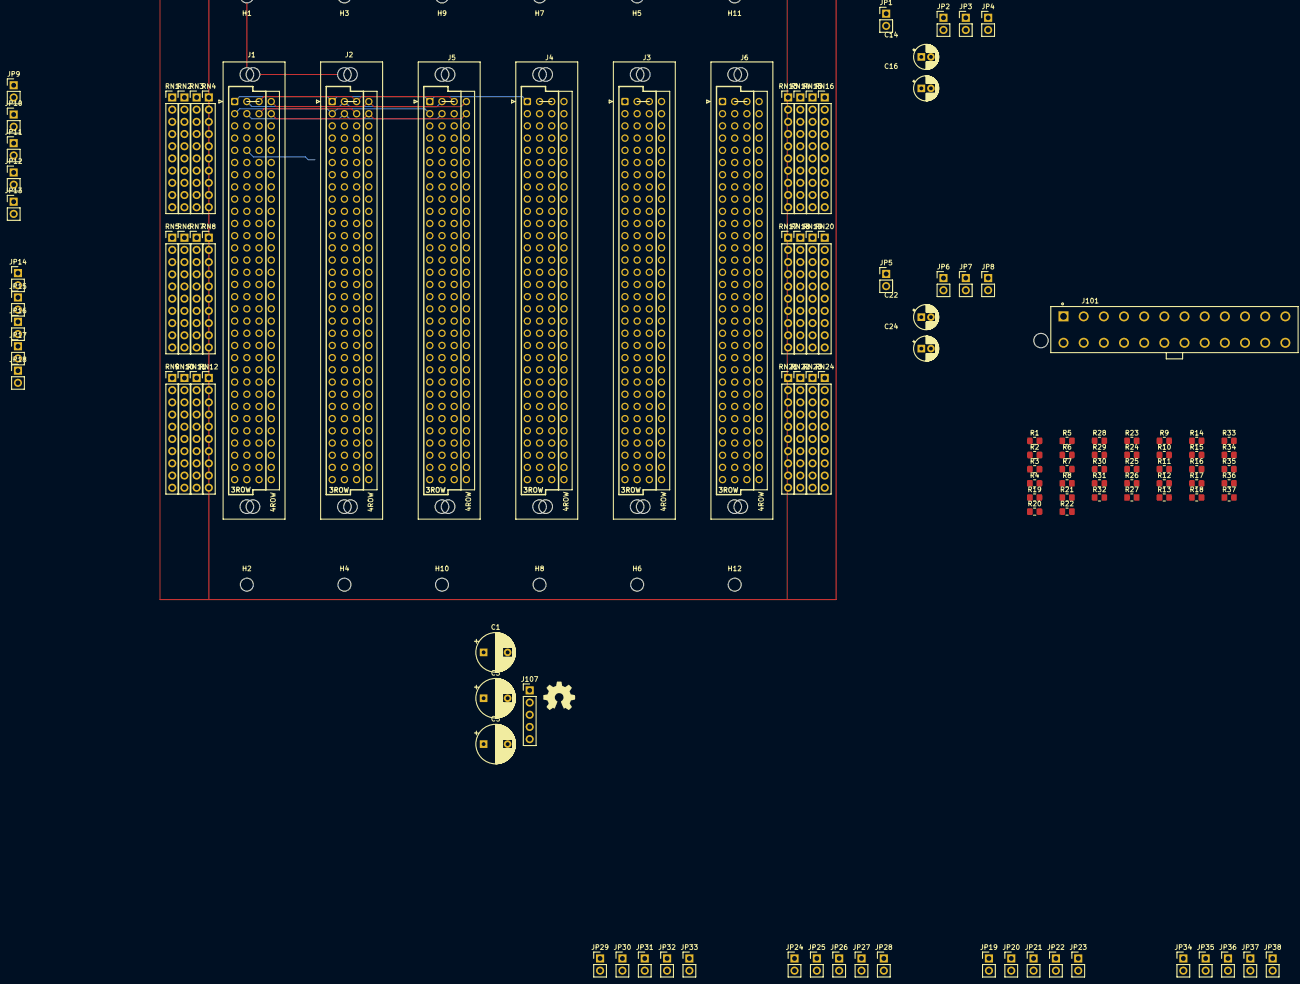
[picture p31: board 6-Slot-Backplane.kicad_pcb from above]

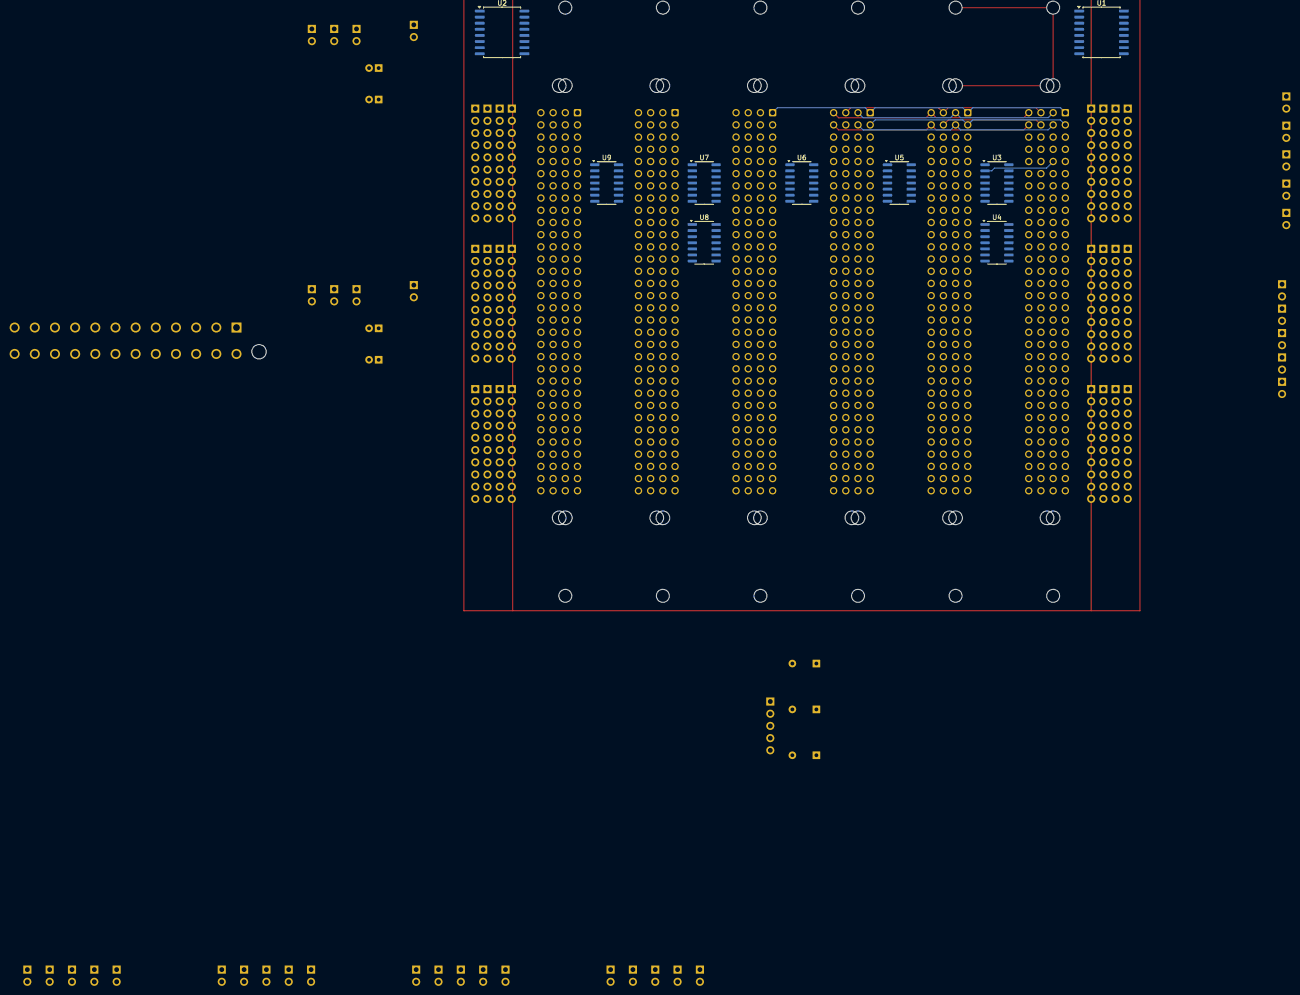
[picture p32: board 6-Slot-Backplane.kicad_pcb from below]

Board: 4 copper layers, 136 parts (9 on the bottom side), 139 nets.

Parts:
C1, C3, C5: 10uF; CP_Radial_D8.0mm_P5.00mm
C14, C16, C22, C24: 4.7uF; CP_Radial_D5.0mm_P2.00mm
H1, H2, H3, H4, H5, H6, H7, H8, H9, H10, H11, H12: MountingHole; MountingHole_2.7mm_M2.5_DIN965
J1, J2, J3, J4, J5, J6: VME-J1-4R-NS; DIN41612_C_4x32_Female_Vertical_THT
J101: ATX-24; TE_1-1775099-3_ATX_24_Pin_PowerSupply
J107: SYSTEM MONITOR; PinHeader_1x05_P2.54mm_Vertical
JP1, JP2, JP3, JP4, JP5, JP6, JP7, JP8: PASSIVE/ACTIVE; PinHeader_1x02_P2.54mm_Vertical
JP9: BR0 LOOPBACK; PinHeader_1x02_P2.54mm_Vertical
JP10: BR1 LOOPBACK; PinHeader_1x02_P2.54mm_Vertical
JP11: BR2 LOOPBACK; PinHeader_1x02_P2.54mm_Vertical
JP12: BR3 LOOPBACK; PinHeader_1x02_P2.54mm_Vertical
JP13: IACK LOOPBACK; PinHeader_1x02_P2.54mm_Vertical
JP14, JP19, JP24, JP29, JP34: BG0; PinHeader_1x02_P2.54mm_Vertical
JP15, JP20, JP25, JP30, JP35: BG1; PinHeader_1x02_P2.54mm_Vertical
JP16, JP21, JP26, JP31, JP36: BG2; PinHeader_1x02_P2.54mm_Vertical
JP17, JP22, JP27, JP32, JP37: BG3; PinHeader_1x02_P2.54mm_Vertical
JP18, JP23, JP28, JP33, JP38: IACK; PinHeader_1x02_P2.54mm_Vertical
R1, R4, R6, R8, R20, R22: 470; R_0805_2012Metric_Pad1.20x1.40mm_HandSolder
R2, R3, R5, R7, R19, R21: 330; R_0805_2012Metric_Pad1.20x1.40mm_HandSolder
R9, R10, R11, R12, R13, R14, R15, R16, R17, R18, R23, R24, R25, R26, R27, R28, R29, R30, R31, R32, R33, R34, R35, R36, R37: 82k; R_0805_2012Metric_Pad1.20x1.40mm_HandSolder
RN1, RN2, RN3, RN4, RN5, RN6, RN7, RN8, RN9, RN10, RN11, RN12, RN13, RN14, RN15, RN16, RN17, RN18, RN19, RN20, RN21, RN22, RN23, RN24: 4610X-104-331/471L; PinHeader_1x10_P2.54mm_Vertical
S1: Logo_Open_Hardware_Small; OSHW-Symbol_6.7x6mm_SilkScreen
U1, U2: TCA0372_Dual_OpAmp; SOIC-16W_7.5x10.3mm_P1.27mm
U3, U4, U5, U6, U7, U8, U9: 74ACT32; SOIC-14_3.9x8.7mm_P1.27mm

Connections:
+5V: C1.1, J1.a32 (+5V), J1.b32 (+5V), J1.c32 (+5V), J1.d1 (+5V), J1.d13 (+5V), J1.d32 (+5V), J2.a32 (+5V), J2.b32 (+5V), J2.c32 (+5V), J2.d1 (+5V), J2.d13 (+5V), J2.d32 (+5V), J3.a32 (+5V), J3.b32 (+5V), J3.c32 (+5V), J3.d1 (+5V), J3.d13 (+5V), J3.d32 (+5V), J4.a32 (+5V), J4.b32 (+5V), J4.c32 (+5V), J4.d1 (+5V), J4.d13 (+5V), J4.d32 (+5V), J5.a32 (+5V), J5.b32 (+5V), J5.c32 (+5V), J5.d1 (+5V), J5.d13 (+5V), J5.d32 (+5V), J6.a32 (+5V), J6.b32 (+5V), J6.c32 (+5V), J6.d1 (+5V), J6.d13 (+5V), J6.d32 (+5V), J101.4 (+5V), J101.6 (+5V), J101.21 (+5V), J101.22 (+5V), J101.23 (+5V), J107.4, JP1.1 (A), JP3.1 (A), JP5.1 (A), JP7.1 (A), R3.1, R7.1, R19.1, R21.1, U1.1 (V+), U2.1 (V+), U3.14 (VCC), U4.14 (VCC), U5.14 (VCC), U6.14 (VCC), U7.14 (VCC), U8.14 (VCC), U9.14 (VCC)
+5VStdby: J1.b31 (+5VStdby), J2.b31 (+5VStdby), J3.b31 (+5VStdby), J4.b31 (+5VStdby), J5.b31 (+5VStdby), J6.b31 (+5VStdby), J101.9 (+5VSB)
+12V: C3.1, J1.c31 (+12V), J2.c31 (+12V), J3.c31 (+12V), J4.c31 (+12V), J5.c31 (+12V), J6.c31 (+12V), J101.10 (+12V), J101.11 (+12V)
-12V: C5.1, J1.a31 (-12V), J2.a31 (-12V), J3.a31 (-12V), J4.a31 (-12V), J5.a31 (-12V), J6.a31 (-12V), J101.14 (-12V)
A1: J1.a30 (A01), J2.a30 (A01), J3.a30 (A01), J4.a30 (A01), J5.a30 (A01), J6.a30 (A01), RN3.2 (R1), RN23.2 (R1)
A2: J1.a29 (A02), J2.a29 (A02), J3.a29 (A02), J4.a29 (A02), J5.a29 (A02), J6.a29 (A02), RN3.3 (R2), RN23.3 (R2)
A3: J1.a28 (A03), J2.a28 (A03), J3.a28 (A03), J4.a28 (A03), J5.a28 (A03), J6.a28 (A03), RN3.4 (R3), RN23.4 (R3)
A4: J1.a27 (A04), J2.a27 (A04), J3.a27 (A04), J4.a27 (A04), J5.a27 (A04), J6.a27 (A04), RN3.5 (R4), RN23.5 (R4)
A5: J1.a26 (A05), J2.a26 (A05), J3.a26 (A05), J4.a26 (A05), J5.a26 (A05), J6.a26 (A05), RN3.6 (R5), RN23.6 (R5)
A6: J1.a25 (A06), J2.a25 (A06), J3.a25 (A06), J4.a25 (A06), J5.a25 (A06), J6.a25 (A06), RN3.7 (R6), RN23.7 (R6)
A7: J1.a24 (A07), J2.a24 (A07), J3.a24 (A07), J4.a24 (A07), J5.a24 (A07), J6.a24 (A07), RN3.8 (R7), RN23.8 (R7)
A8: J1.c30 (A8), J2.c30 (A8), J3.c30 (A8), J4.c30 (A8), J5.c30 (A8), J6.c30 (A8), RN4.2 (R1), RN24.2 (R1)
A9: J1.c29 (A9), J2.c29 (A9), J3.c29 (A9), J4.c29 (A9), J5.c29 (A9), J6.c29 (A9), RN4.3 (R2), RN24.3 (R2)
A10: J1.c28 (A10), J2.c28 (A10), J3.c28 (A10), J4.c28 (A10), J5.c28 (A10), J6.c28 (A10), RN4.4 (R3), RN24.4 (R3)
A11: J1.c27 (A11), J2.c27 (A11), J3.c27 (A11), J4.c27 (A11), J5.c27 (A11), J6.c27 (A11), RN4.5 (R4), RN24.5 (R4)
A12: J1.c26 (A12), J2.c26 (A12), J3.c26 (A12), J4.c26 (A12), J5.c26 (A12), J6.c26 (A12), RN4.6 (R5), RN24.6 (R5)
A13: J1.c25 (A13), J2.c25 (A13), J3.c25 (A13), J4.c25 (A13), J5.c25 (A13), J6.c25 (A13), RN4.7 (R6), RN24.7 (R6)
A14: J1.c24 (A14), J2.c24 (A14), J3.c24 (A14), J4.c24 (A14), J5.c24 (A14), J6.c24 (A14), RN4.8 (R7), RN24.8 (R7)
A15: J1.c23 (A15), J2.c23 (A15), J3.c23 (A15), J4.c23 (A15), J5.c23 (A15), J6.c23 (A15), RN4.9 (R8), RN24.9 (R8)
A16: J1.c22 (A16), J2.c22 (A16), J3.c22 (A16), J4.c22 (A16), J5.c22 (A16), J6.c22 (A16), RN5.2 (R1), RN17.2 (R1)
A17: J1.c21 (A17), J2.c21 (A17), J3.c21 (A17), J4.c21 (A17), J5.c21 (A17), J6.c21 (A17), RN5.3 (R2), RN17.3 (R2)
A18: J1.c20 (A18), J2.c20 (A18), J3.c20 (A18), J4.c20 (A18), J5.c20 (A18), J6.c20 (A18), RN5.4 (R3), RN17.4 (R3)
A19: J1.c19 (A19), J2.c19 (A19), J3.c19 (A19), J4.c19 (A19), J5.c19 (A19), J6.c19 (A19), RN5.5 (R4), RN17.5 (R4)
A20: J1.c18 (A20), J2.c18 (A20), J3.c18 (A20), J4.c18 (A20), J5.c18 (A20), J6.c18 (A20), RN5.6 (R5), RN17.6 (R5)
A21: J1.c17 (A21), J2.c17 (A21), J3.c17 (A21), J4.c17 (A21), J5.c17 (A21), J6.c17 (A21), RN5.7 (R6), RN17.7 (R6)
A22: J1.c16 (A22), J2.c16 (A22), J3.c16 (A22), J4.c16 (A22), J5.c16 (A22), J6.c16 (A22), RN5.8 (R7), RN17.8 (R7)
A23: J1.c15 (A23), J2.c15 (A23), J3.c15 (A23), J4.c15 (A23), J5.c15 (A23), J6.c15 (A23), RN5.9 (R8), RN17.9 (R8)
A24: J1.d4 (A24), J2.d4 (A24), J3.d4 (A24), J4.d4 (A24), J5.d4 (A24), J6.d4 (A24), RN6.2 (R1), RN18.2 (R1)
A25: J1.d5 (A25), J2.d5 (A25), J3.d5 (A25), J4.d5 (A25), J5.d5 (A25), J6.d5 (A25), RN6.3 (R2), RN18.3 (R2)
A26: J1.d6 (A26), J2.d6 (A26), J3.d6 (A26), J4.d6 (A26), J5.d6 (A26), J6.d6 (A26), RN6.4 (R3), RN18.4 (R3)
A27: J1.d7 (A27), J2.d7 (A27), J3.d7 (A27), J4.d7 (A27), J5.d7 (A27), J6.d7 (A27), RN6.5 (R4), RN18.5 (R4)
A28: J1.d8 (A28), J2.d8 (A28), J3.d8 (A28), J4.d8 (A28), J5.d8 (A28), J6.d8 (A28), RN6.6 (R5), RN18.6 (R5)
A29: J1.d9 (A29), J2.d9 (A29), J3.d9 (A29), J4.d9 (A29), J5.d9 (A29), J6.d9 (A29), RN6.7 (R6), RN18.7 (R6)
A30: J1.d10 (A30), J2.d10 (A30), J3.d10 (A30), J4.d10 (A30), J5.d10 (A30), J6.d10 (A30), RN6.8 (R7), RN18.8 (R7)
A31: J1.d11 (A31), J2.d11 (A31), J3.d11 (A31), J4.d11 (A31), J5.d11 (A31), J6.d11 (A31), RN6.9 (R8), RN18.9 (R8)
AM0: J1.b16 (AM0), J2.b16 (AM0), J3.b16 (AM0), J4.b16 (AM0), J5.b16 (AM0), J6.b16 (AM0), RN10.9 (R8), RN14.9 (R8)
AM1: J1.b17 (AM1), J2.b17 (AM1), J3.b17 (AM1), J4.b17 (AM1), J5.b17 (AM1), J6.b17 (AM1), RN11.2 (R1), RN15.2 (R1)
AM2: J1.b18 (AM2), J2.b18 (AM2), J3.b18 (AM2), J4.b18 (AM2), J5.b18 (AM2), J6.b18 (AM2), RN11.3 (R2), RN15.3 (R2)
AM3: J1.b19 (AM3), J2.b19 (AM3), J3.b19 (AM3), J4.b19 (AM3), J5.b19 (AM3), J6.b19 (AM3), RN11.4 (R3), RN15.4 (R3)
AM4: J1.a23 (AM4), J2.a23 (AM4), J3.a23 (AM4), J4.a23 (AM4), J5.a23 (AM4), J6.a23 (AM4), RN9.9 (R8), RN13.9 (R8)
AM5: J1.c14 (AM5), J2.c14 (AM5), J3.c14 (AM5), J4.c14 (AM5), J5.c14 (AM5), J6.c14 (AM5), RN3.9 (R8), RN23.9 (R8)
D0: J1.a1 (D00), J2.a1 (D00), J3.a1 (D00), J4.a1 (D00), J5.a1 (D00), J6.a1 (D00), RN1.2 (R1), RN21.2 (R1)
D1: J1.a2 (D01), J2.a2 (D01), J3.a2 (D01), J4.a2 (D01), J5.a2 (D01), J6.a2 (D01), RN1.3 (R2), RN21.3 (R2)
D2: J1.a3 (D02), J2.a3 (D02), J3.a3 (D02), J4.a3 (D02), J5.a3 (D02), J6.a3 (D02), RN1.4 (R3), RN21.4 (R3)
D3: J1.a4 (D03), J2.a4 (D03), J3.a4 (D03), J4.a4 (D03), J5.a4 (D03), J6.a4 (D03), RN1.5 (R4), RN21.5 (R4)
D4: J1.a5 (D04), J2.a5 (D04), J3.a5 (D04), J4.a5 (D04), J5.a5 (D04), J6.a5 (D04), RN1.6 (R5), RN21.6 (R5)
D5: J1.a6 (D05), J2.a6 (D05), J3.a6 (D05), J4.a6 (D05), J5.a6 (D05), J6.a6 (D05), RN1.7 (R6), RN21.7 (R6)
D6: J1.a7 (D06), J2.a7 (D06), J3.a7 (D06), J4.a7 (D06), J5.a7 (D06), J6.a7 (D06), RN1.8 (R7), RN21.8 (R7)
D7: J1.a8 (D07), J2.a8 (D07), J3.a8 (D07), J4.a8 (D07), J5.a8 (D07), J6.a8 (D07), RN1.9 (R8), RN21.9 (R8)
D8: J1.c1 (D08), J2.c1 (D08), J3.c1 (D08), J4.c1 (D08), J5.c1 (D08), J6.c1 (D08), RN2.2 (R1), RN22.2 (R1)
D9: J1.c2 (D09), J2.c2 (D09), J3.c2 (D09), J4.c2 (D09), J5.c2 (D09), J6.c2 (D09), RN2.3 (R2), RN22.3 (R2)
D10: J1.c3 (D10), J2.c3 (D10), J3.c3 (D10), J4.c3 (D10), J5.c3 (D10), J6.c3 (D10), RN2.4 (R3), RN22.4 (R3)
D11: J1.c4 (D11), J2.c4 (D11), J3.c4 (D11), J4.c4 (D11), J5.c4 (D11), J6.c4 (D11), RN2.5 (R4), RN22.5 (R4)
D12: J1.c5 (D12), J2.c5 (D12), J3.c5 (D12), J4.c5 (D12), J5.c5 (D12), J6.c5 (D12), RN2.6 (R5), RN22.6 (R5)
D13: J1.c6 (D13), J2.c6 (D13), J3.c6 (D13), J4.c6 (D13), J5.c6 (D13), J6.c6 (D13), RN2.7 (R6), RN22.7 (R6)
D14: J1.c7 (D14), J2.c7 (D14), J3.c7 (D14), J4.c7 (D14), J5.c7 (D14), J6.c7 (D14), RN2.8 (R7), RN22.8 (R7)
D15: J1.c8 (D15), J2.c8 (D15), J3.c8 (D15), J4.c8 (D15), J5.c8 (D15), J6.c8 (D15), RN2.9 (R8), RN22.9 (R8)
D16: J1.d14 (D16), J2.d14 (D16), J3.d14 (D16), J4.d14 (D16), J5.d14 (D16), J6.d14 (D16), RN7.2 (R1), RN19.2 (R1)
D17: J1.d15 (D17), J2.d15 (D17), J3.d15 (D17), J4.d15 (D17), J5.d15 (D17), J6.d15 (D17), RN7.3 (R2), RN19.3 (R2)
D18: J1.d16 (D18), J2.d16 (D18), J3.d16 (D18), J4.d16 (D18), J5.d16 (D18), J6.d16 (D18), RN7.4 (R3), RN19.4 (R3)
D19: J1.d17 (D19), J2.d17 (D19), J3.d17 (D19), J4.d17 (D19), J5.d17 (D19), J6.d17 (D19), RN7.5 (R4), RN19.5 (R4)
D20: J1.d18 (D20), J2.d18 (D20), J3.d18 (D20), J4.d18 (D20), J5.d18 (D20), J6.d18 (D20), RN7.6 (R5), RN19.6 (R5)
D21: J1.d19 (D21), J2.d19 (D21), J3.d19 (D21), J4.d19 (D21), J5.d19 (D21), J6.d19 (D21), RN7.7 (R6), RN19.7 (R6)
D22: J1.d20 (D22), J2.d20 (D22), J3.d20 (D22), J4.d20 (D22), J5.d20 (D22), J6.d20 (D22), RN7.8 (R7), RN19.8 (R7)
D23: J1.d21 (D23), J2.d21 (D23), J3.d21 (D23), J4.d21 (D23), J5.d21 (D23), J6.d21 (D23), RN7.9 (R8), RN19.9 (R8)
D24: J1.d23 (D24), J2.d23 (D24), J3.d23 (D24), J4.d23 (D24), J5.d23 (D24), J6.d23 (D24), RN8.2 (R1), RN20.2 (R1)
D25: J1.d24 (D25), J2.d24 (D25), J3.d24 (D25), J4.d24 (D25), J5.d24 (D25), J6.d24 (D25), RN8.3 (R2), RN20.3 (R2)
D26: J1.d25 (D26), J2.d25 (D26), J3.d25 (D26), J4.d25 (D26), J5.d25 (D26), J6.d25 (D26), RN8.4 (R3), RN20.4 (R3)
D27: J1.d26 (D27), J2.d26 (D27), J3.d26 (D27), J4.d26 (D27), J5.d26 (D27), J6.d26 (D27), RN8.5 (R4), RN20.5 (R4)
D28: J1.d27 (D28), J2.d27 (D28), J3.d27 (D28), J4.d27 (D28), J5.d27 (D28), J6.d27 (D28), RN8.6 (R5), RN20.6 (R5)
D29: J1.d28 (D29), J2.d28 (D29), J3.d28 (D29), J4.d28 (D29), J5.d28 (D29), J6.d28 (D29), RN8.7 (R6), RN20.7 (R6)
D30: J1.d29 (D30), J2.d29 (D30), J3.d29 (D30), J4.d29 (D30), J5.d29 (D30), J6.d29 (D30), RN8.8 (R7), RN20.8 (R7)
D31: J1.d30 (D31), J2.d30 (D31), J3.d30 (D31), J4.d30 (D31), J5.d30 (D31), J6.d30 (D31), RN8.9 (R8), RN20.9 (R8)
GND: C1.2, C3.2, C5.2, C14.2, C16.2, C22.2, C24.2, J1.a9 (GND), J1.a11 (GND), J1.a15 (GND), J1.a17 (GND), J1.a19 (GND), J1.b20 (GND), J1.b23 (GND), J1.c9 (GND), J1.d2 (GND), J1.d12 (GND), J1.d22 (GND), J1.d31 (GND), J2.a9 (GND), J2.a11 (GND), J2.a15 (GND), J2.a17 (GND), J2.a19 (GND), J2.b20 (GND), J2.b23 (GND), J2.c9 (GND), J2.d2 (GND), J2.d12 (GND), J2.d22 (GND), J2.d31 (GND), J3.a9 (GND), J3.a11 (GND), J3.a15 (GND), J3.a17 (GND), J3.a19 (GND), J3.b20 (GND), J3.b23 (GND), J3.c9 (GND), J3.d2 (GND), J3.d12 (GND), J3.d22 (GND), J3.d31 (GND), J4.a9 (GND), J4.a11 (GND), J4.a15 (GND), J4.a17 (GND), J4.a19 (GND), J4.b20 (GND), J4.b23 (GND), J4.c9 (GND), J4.d2 (GND), J4.d12 (GND), J4.d22 (GND), J4.d31 (GND), J5.a9 (GND), J5.a11 (GND), J5.a15 (GND), J5.a17 (GND), J5.a19 (GND), J5.b20 (GND), J5.b23 (GND), J5.c9 (GND), J5.d2 (GND), J5.d12 (GND), J5.d22 (GND), J5.d31 (GND), J6.a9 (GND), J6.a11 (GND), J6.a15 (GND), J6.a17 (GND), J6.a19 (GND), J6.b20 (GND), J6.b23 (GND), J6.c9 (GND), J6.d2 (GND), J6.d12 (GND), J6.d22 (GND), J6.d31 (GND), J101.3 (GND), J101.5 (GND), J101.7 (GND), J101.15 (GND), J101.16 (PS_ON#), J101.17 (GND), J101.18 (GND), J101.19 (GND), J101.24 (GND), J107.5, JP2.1 (A), JP4.1 (A), JP6.1 (A), JP8.1 (A), R4.2, R8.2, R9.2, R10.2, R11.2, R12.2, R13.2, R14.2, R15.2, R16.2, R17.2, R18.2, R20.2, R22.2, R23.2, R24.2, R25.2, R26.2, R27.2, R28.2, R29.2, R30.2, R31.2, R32.2, R33.2, R34.2, R35.2, R36.2, R37.2, U1.4 (V-), U1.5 (V-), U1.12 (V-), U1.13 (V-), U2.4 (V-), U2.5 (V-), U2.12 (V-), U2.13 (V-), U3.7 (GND), U4.7 (GND), U5.7 (GND), U6.7 (GND), U7.7 (GND), U8.7 (GND), U9.7 (GND)
unnamed: J101.1 (+3.3V), J101.2 (+3.3V), J101.12 (+3.3V), J101.13 (+3.3V)
unnamed: C14.1, U1.9 (+), U1.16
unnamed: C16.1, U1.2, U1.8 (+)
unnamed: C22.1, U2.9 (+), U2.16
unnamed: C24.1, U2.2, U2.8 (+)
unnamed: R3.2, R4.1, U1.10 (-)
unnamed: R19.2, R20.1, U1.7 (-)
unnamed: R7.2, R8.1, U2.10 (-)
unnamed: R21.2, R22.1, U2.7 (-)
SYSCLK: J1.a10 (SYSCLK), J2.a10 (SYSCLK), J3.a10 (SYSCLK), J4.a10 (SYSCLK), J5.a10 (SYSCLK), J6.a10 (SYSCLK), RN9.2 (R1), RN13.2 (R1)
TERM_L1_HIGH: JP1.2 (C), RN1.10 (COM2), RN2.10 (COM2), RN3.10 (COM2), RN4.10 (COM2), RN5.10 (COM2), RN9.10 (COM2), RN10.10 (COM2), RN11.10 (COM2), RN12.10 (COM2)
TERM_L1_LOW: JP2.2 (C), RN1.1 (COM1), RN2.1 (COM1), RN3.1 (COM1), RN4.1 (COM1), RN5.1 (COM1), RN9.1 (COM1), RN10.1 (COM1), RN11.1 (COM1), RN12.1 (COM1)
TERM_L2_HIGH: JP3.2 (C), R2.2, RN6.10 (COM2), RN7.10 (COM2), RN8.10 (COM2)
TERM_L2_LOW: JP4.2 (C), R1.1, RN6.1 (COM1), RN7.1 (COM1), RN8.1 (COM1)
TERM_R1_HIGH: JP5.2 (C), RN13.10 (COM2), RN14.10 (COM2), RN15.10 (COM2), RN16.10 (COM2), RN17.10 (COM2), RN21.10 (COM2), RN22.10 (COM2), RN23.10 (COM2), RN24.10 (COM2)
TERM_R1_LOW: JP6.2 (C), RN13.1 (COM1), RN14.1 (COM1), RN15.1 (COM1), RN16.1 (COM1), RN17.1 (COM1), RN21.1 (COM1), RN22.1 (COM1), RN23.1 (COM1), RN24.1 (COM1)
TERM_R2_HIGH: JP7.2 (C), R5.2, RN18.10 (COM2), RN19.10 (COM2), RN20.10 (COM2)
TERM_R2_LOW: JP8.2 (C), R6.1, RN18.1 (COM1), RN19.1 (COM1), RN20.1 (COM1)
~ACFAIL: J1.b3 (~ACFAIL), J2.b3 (~ACFAIL), J3.b3 (~ACFAIL), J4.b3 (~ACFAIL), J5.b3 (~ACFAIL), J6.b3 (~ACFAIL), J107.3, RN10.4 (R3), RN14.4 (R3)
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

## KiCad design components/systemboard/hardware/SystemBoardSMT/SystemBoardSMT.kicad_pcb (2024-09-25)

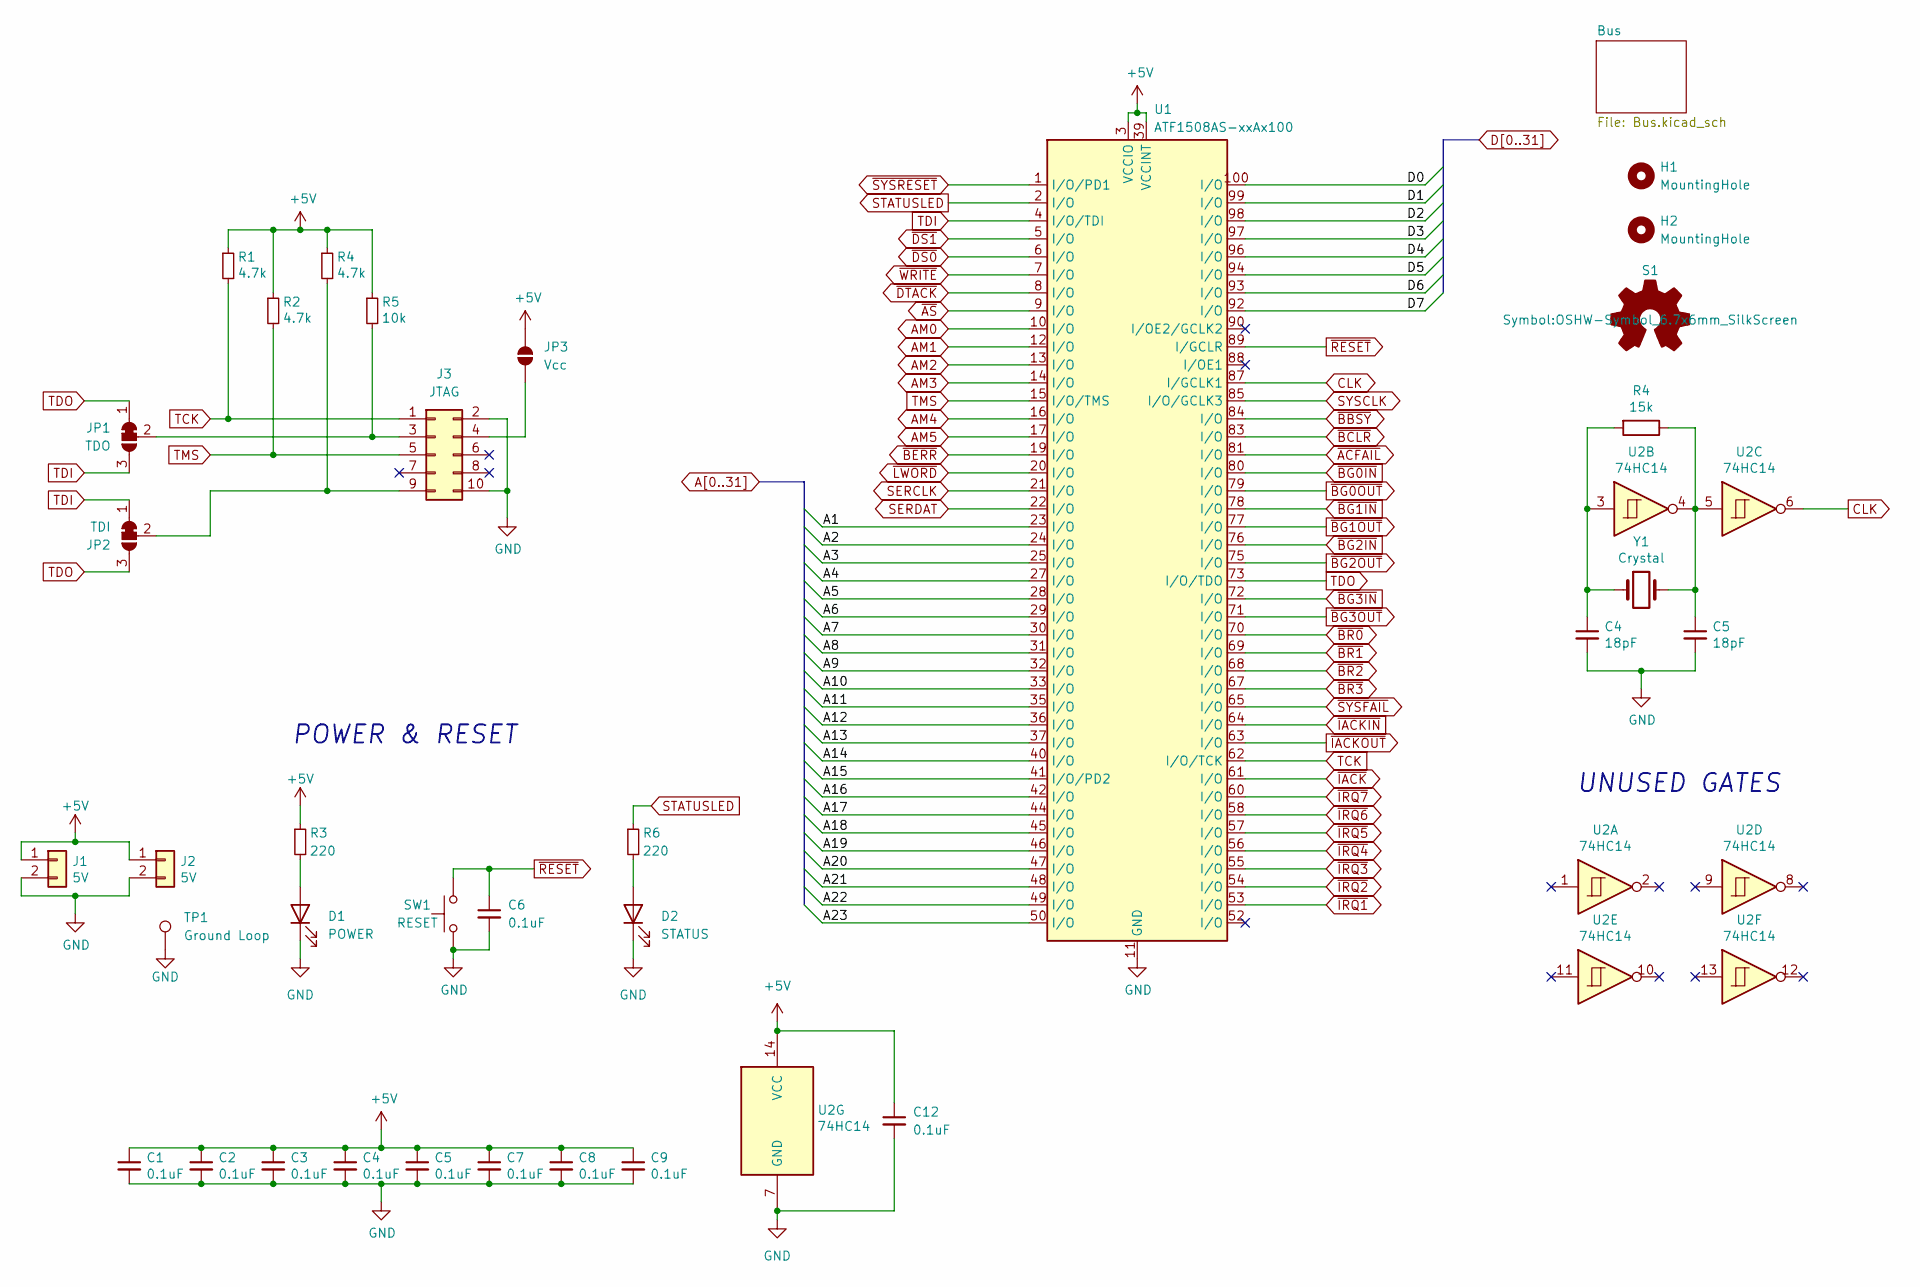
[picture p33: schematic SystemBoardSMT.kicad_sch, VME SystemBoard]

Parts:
C1, C2, C3, C4, C6, C7, C8, C9, C12: 0.1uF; C_0805_2012Metric_Pad1.18x1.45mm_HandSolder
C5: 18pF; C_Disc_D3.0mm_W2.0mm_P2.50mm
D1: POWER; LED_D3.0mm
D2: STATUS; LED_D3.0mm
H1, H2: MountingHole; MountingHole_2.7mm_M2.5_DIN965
J1, J2: 5V; PinHeader_1x02_P2.54mm_Vertical
J3: JTAG; PinHeader_2x05_P2.54mm_Vertical
JP1: TDO; SolderJumper-3_P1.3mm_Bridged12_RoundedPad1.0x1.5mm_NumberL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
JP2: TDI; SolderJumper-3_P1.3mm_Bridged12_RoundedPad1.0x1.5mm_NumberL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
JP3: Vcc; SolderJumper-2_P1.3mm_Open_RoundedPad1.0x1.5mm
R1, R2, R4: 4.7k; R_Axial_DIN0204_L3.6mm_D1.6mm_P5.08mm_Horizontal
R3, R6: 220; R_Axial_DIN0204_L3.6mm_D1.6mm_P5.08mm_Horizontal
R5: 10k; R_Axial_DIN0204_L3.6mm_D1.6mm_P5.08mm_Horizontal
S1: Logo_Open_Hardware_Small; OSHW-Symbol_6.7x6mm_SilkScreen
SW1: RESET; SW_PUSH_6mm
TP1: Ground Loop; TestPoint_Loop_D2.60mm_Drill1.6mm_Beaded
U1: ATF1508AS-xxAx100; TQFP-100_14x14mm_P0.5mm
U2: 74HC14; TSSOP-14_4.4x5mm_P0.65mm
Y1: Crystal; Crystal_HC49-4H_Vertical

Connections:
A1: U1.23 (I/O); also elsewhere on the board
A2: U1.24 (I/O); also elsewhere on the board
A3: U1.25 (I/O); also elsewhere on the board
A4: U1.27 (I/O); also elsewhere on the board
A5: U1.28 (I/O); also elsewhere on the board
A6: U1.29 (I/O); also elsewhere on the board
A7: U1.30 (I/O); also elsewhere on the board
A8: U1.31 (I/O); also elsewhere on the board
A9: U1.32 (I/O); also elsewhere on the board
A10: U1.33 (I/O); also elsewhere on the board
A11: U1.35 (I/O); also elsewhere on the board
A12: U1.36 (I/O); also elsewhere on the board
A13: U1.37 (I/O); also elsewhere on the board
A14: U1.40 (I/O); also elsewhere on the board
A15: U1.41 (I/O/PD2); also elsewhere on the board
A16: U1.42 (I/O); also elsewhere on the board
A17: U1.44 (I/O); also elsewhere on the board
A18: U1.45 (I/O); also elsewhere on the board
A19: U1.46 (I/O); also elsewhere on the board
A20: U1.47 (I/O); also elsewhere on the board
A21: U1.48 (I/O); also elsewhere on the board
A22: U1.49 (I/O); also elsewhere on the board
A23: U1.50 (I/O); also elsewhere on the board
AM0: U1.10 (I/O); also elsewhere on the board
AM1: U1.12 (I/O); also elsewhere on the board
AM2: U1.13 (I/O); also elsewhere on the board
AM3: U1.14 (I/O); also elsewhere on the board
AM4: U1.16 (I/O); also elsewhere on the board
AM5: U1.17 (I/O); also elsewhere on the board
CLK: U1.87 (I/GCLK1), U2.6
D0: U1.100 (I/O); also elsewhere on the board
D1: U1.99 (I/O); also elsewhere on the board
D2: U1.98 (I/O); also elsewhere on the board
D3: U1.97 (I/O); also elsewhere on the board
D4: U1.96 (I/O); also elsewhere on the board
D5: U1.94 (I/O); also elsewhere on the board
D6: U1.93 (I/O); also elsewhere on the board
D7: U1.92 (I/O); also elsewhere on the board
GND: C1.2, C2.2, C3.2, C4.2, C5.2, C6.2, C7.2, C8.2, C9.2, C12.2, D1.1 (K), D2.1 (K), J1.2, J2.2, J3.2, J3.10, SW1.1, TP1.1, U1.11 (GND), U1.26 (GND), U1.38 (GND), U1.43 (GND), U1.59 (GND), U1.74 (GND), U1.86 (GND), U1.95 (GND), U2.7 (GND); also elsewhere on the board
unnamed: D1.2 (A), R3.2
unnamed: D2.2 (A), R6.2
unnamed: J3.3, JP1.2 (C), R5.2
unnamed: J3.4, JP3.1 (A)
SERCLK: U1.21 (I/O); also elsewhere on the board
SERDAT: U1.22 (I/O); also elsewhere on the board
STATUSLED: R6.1, U1.2 (I/O)
SYSCLK: U1.85 (I/O/GCLK3); also elsewhere on the board
TCK: J3.1, R1.2, U1.62 (I/O/TCK)
TDI: JP1.3 (B), JP2.1 (A), U1.4 (I/O/TDI)
TDO: JP1.1 (A), JP2.3 (B), U1.73 (I/O/TDO)
TMS: J3.5, R2.2, U1.15 (I/O/TMS)
~ACFAIL: U1.81 (I/O); also elsewhere on the board
~AS: U1.9 (I/O); also elsewhere on the board
~BBSY: U1.84 (I/O); also elsewhere on the board
~BCLR: U1.83 (I/O); also elsewhere on the board
~BERR: U1.19 (I/O); also elsewhere on the board
~BG0IN: U1.80 (I/O); also elsewhere on the board
~BG0OUT: U1.79 (I/O); also elsewhere on the board
~BG1IN: U1.78 (I/O); also elsewhere on the board
~BG1OUT: U1.77 (I/O); also elsewhere on the board
~BG2IN: U1.76 (I/O); also elsewhere on the board
~BG2OUT: U1.75 (I/O); also elsewhere on the board
~BG3IN: U1.72 (I/O); also elsewhere on the board
~BG3OUT: U1.71 (I/O); also elsewhere on the board
~BR0: U1.70 (I/O); also elsewhere on the board
~BR1: U1.69 (I/O); also elsewhere on the board
~BR2: U1.68 (I/O); also elsewhere on the board
~BR3: U1.67 (I/O); also elsewhere on the board
~DS0: U1.6 (I/O); also elsewhere on the board
~DS1: U1.5 (I/O); also elsewhere on the board
~DTACK: U1.8 (I/O); also elsewhere on the board
~IACKIN: U1.64 (I/O); also elsewhere on the board
~IACKOUT: U1.63 (I/O); also elsewhere on the board
~IACK: U1.61 (I/O); also elsewhere on the board
~IRQ1: U1.53 (I/O); also elsewhere on the board
~IRQ2: U1.54 (I/O); also elsewhere on the board
~IRQ3: U1.55 (I/O); also elsewhere on the board
~IRQ4: U1.56 (I/O); also elsewhere on the board
~IRQ5: U1.57 (I/O); also elsewhere on the board
~IRQ6: U1.58 (I/O); also elsewhere on the board
~IRQ7: U1.60 (I/O); also elsewhere on the board
~LWORD: U1.20 (I/O); also elsewhere on the board
~RESET: C6.1, SW1.2, U1.89 (I/GCLR)
~SYSFAIL: U1.65 (I/O); also elsewhere on the board
~SYSRESET: U1.1 (I/O/PD1); also elsewhere on the board
~WRITE: U1.7 (I/O); also elsewhere on the board

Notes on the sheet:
POWER & RESET
UNUSED GATES

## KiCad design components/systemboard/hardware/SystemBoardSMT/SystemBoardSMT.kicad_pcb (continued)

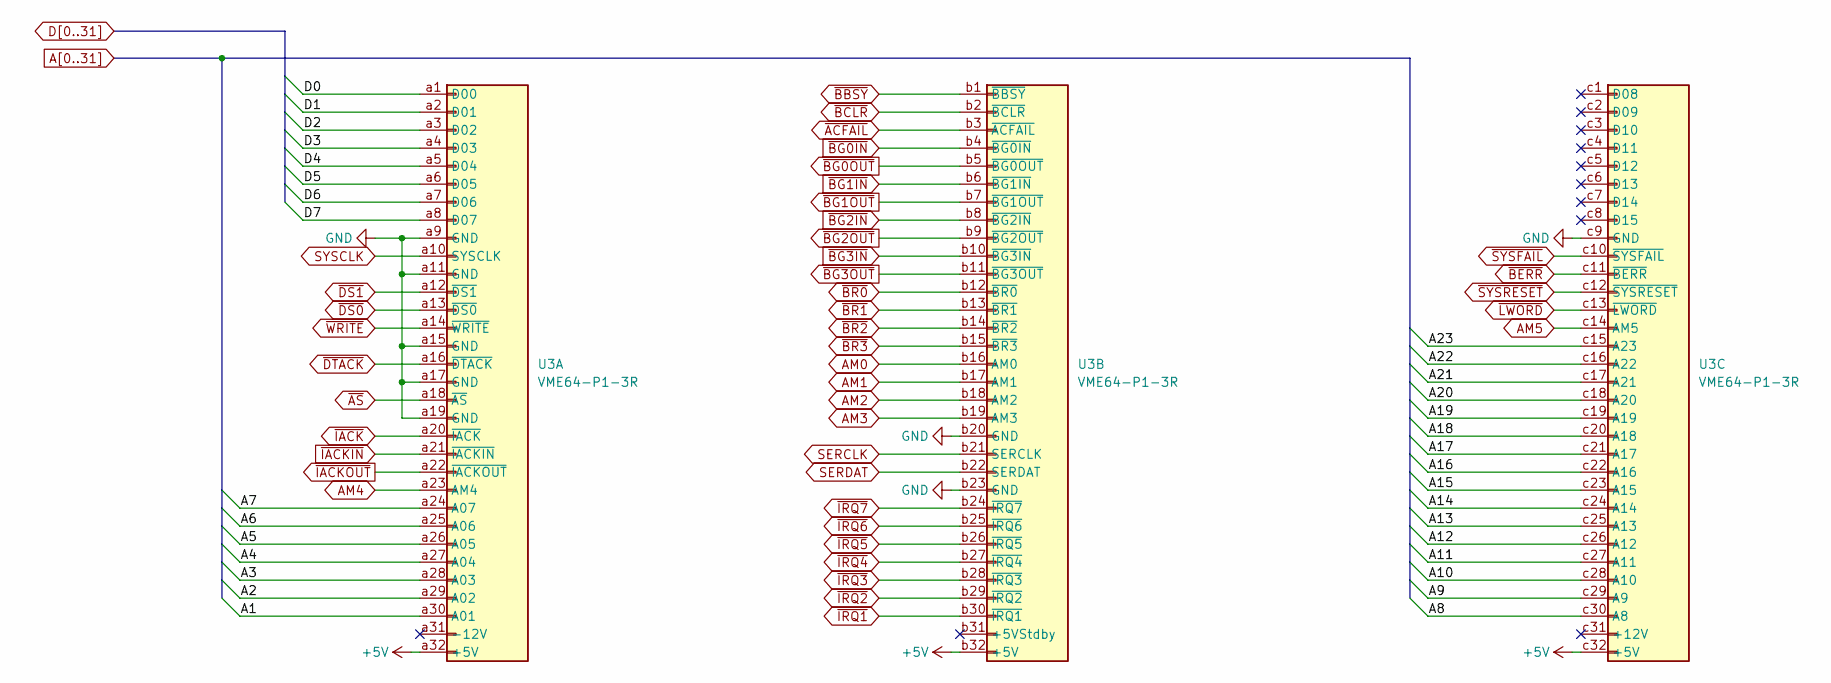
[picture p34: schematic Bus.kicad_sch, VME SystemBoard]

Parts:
U3: VME64-P1-3R; DIN41612_C_3x32_Male_Horizontal_THT

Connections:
A1: U3.a30 (A01); also elsewhere on the board
A2: U3.a29 (A02); also elsewhere on the board
A3: U3.a28 (A03); also elsewhere on the board
A4: U3.a27 (A04); also elsewhere on the board
A5: U3.a26 (A05); also elsewhere on the board
A6: U3.a25 (A06); also elsewhere on the board
A7: U3.a24 (A07); also elsewhere on the board
A8: U3.c30 (A8); also elsewhere on the board
A9: U3.c29 (A9); also elsewhere on the board
A10: U3.c28 (A10); also elsewhere on the board
A11: U3.c27 (A11); also elsewhere on the board
A12: U3.c26 (A12); also elsewhere on the board
A13: U3.c25 (A13); also elsewhere on the board
A14: U3.c24 (A14); also elsewhere on the board
A15: U3.c23 (A15); also elsewhere on the board
A16: U3.c22 (A16); also elsewhere on the board
A17: U3.c21 (A17); also elsewhere on the board
A18: U3.c20 (A18); also elsewhere on the board
A19: U3.c19 (A19); also elsewhere on the board
A20: U3.c18 (A20); also elsewhere on the board
A21: U3.c17 (A21); also elsewhere on the board
A22: U3.c16 (A22); also elsewhere on the board
A23: U3.c15 (A23); also elsewhere on the board
AM0: U3.b16 (AM0); also elsewhere on the board
AM1: U3.b17 (AM1); also elsewhere on the board
AM2: U3.b18 (AM2); also elsewhere on the board
AM3: U3.b19 (AM3); also elsewhere on the board
AM4: U3.a23 (AM4); also elsewhere on the board
AM5: U3.c14 (AM5); also elsewhere on the board
D0: U3.a1 (D00); also elsewhere on the board
D1: U3.a2 (D01); also elsewhere on the board
D2: U3.a3 (D02); also elsewhere on the board
D3: U3.a4 (D03); also elsewhere on the board
D4: U3.a5 (D04); also elsewhere on the board
D5: U3.a6 (D05); also elsewhere on the board
D6: U3.a7 (D06); also elsewhere on the board
D7: U3.a8 (D07); also elsewhere on the board
GND: U3.a9 (GND), U3.a11 (GND), U3.a15 (GND), U3.a17 (GND), U3.a19 (GND), U3.b20 (GND), U3.b23 (GND), U3.c9 (GND); also elsewhere on the board
SERCLK: U3.b21 (SERCLK); also elsewhere on the board
SERDAT: U3.b22 (SERDAT); also elsewhere on the board
SYSCLK: U3.a10 (SYSCLK); also elsewhere on the board
~ACFAIL: U3.b3 (~ACFAIL); also elsewhere on the board
~AS: U3.a18 (~AS); also elsewhere on the board
~BBSY: U3.b1 (~BBSY); also elsewhere on the board
~BCLR: U3.b2 (~BCLR); also elsewhere on the board
~BERR: U3.c11 (~BERR); also elsewhere on the board
~BG0IN: U3.b4 (~BG0IN); also elsewhere on the board
~BG0OUT: U3.b5 (~BG0OUT); also elsewhere on the board
~BG1IN: U3.b6 (~BG1IN); also elsewhere on the board
~BG1OUT: U3.b7 (~BG1OUT); also elsewhere on the board
~BG2IN: U3.b8 (~BG2IN); also elsewhere on the board
~BG2OUT: U3.b9 (~BG2OUT); also elsewhere on the board
~BG3IN: U3.b10 (~BG3IN); also elsewhere on the board
~BG3OUT: U3.b11 (~BG3OUT); also elsewhere on the board
~BR0: U3.b12 (~BR0); also elsewhere on the board
~BR1: U3.b13 (~BR1); also elsewhere on the board
~BR2: U3.b14 (~BR2); also elsewhere on the board
~BR3: U3.b15 (~BR3); also elsewhere on the board
~DS0: U3.a13 (~DS0); also elsewhere on the board
~DS1: U3.a12 (~DS1); also elsewhere on the board
~DTACK: U3.a16 (~DTACK); also elsewhere on the board
~IACKIN: U3.a21 (~IACKIN); also elsewhere on the board
~IACKOUT: U3.a22 (~IACKOUT); also elsewhere on the board
~IACK: U3.a20 (~IACK); also elsewhere on the board
~IRQ1: U3.b30 (~IRQ1); also elsewhere on the board
~IRQ2: U3.b29 (~IRQ2); also elsewhere on the board
~IRQ3: U3.b28 (~IRQ3); also elsewhere on the board
~IRQ4: U3.b27 (~IRQ4); also elsewhere on the board
~IRQ5: U3.b26 (~IRQ5); also elsewhere on the board
~IRQ6: U3.b25 (~IRQ6); also elsewhere on the board
~IRQ7: U3.b24 (~IRQ7); also elsewhere on the board
~LWORD: U3.c13 (~LWORD); also elsewhere on the board
~SYSFAIL: U3.c10 (~SYSFAIL); also elsewhere on the board
~SYSRESET: U3.c12 (~SYSRESET); also elsewhere on the board
~WRITE: U3.a14 (~WRITE); also elsewhere on the board

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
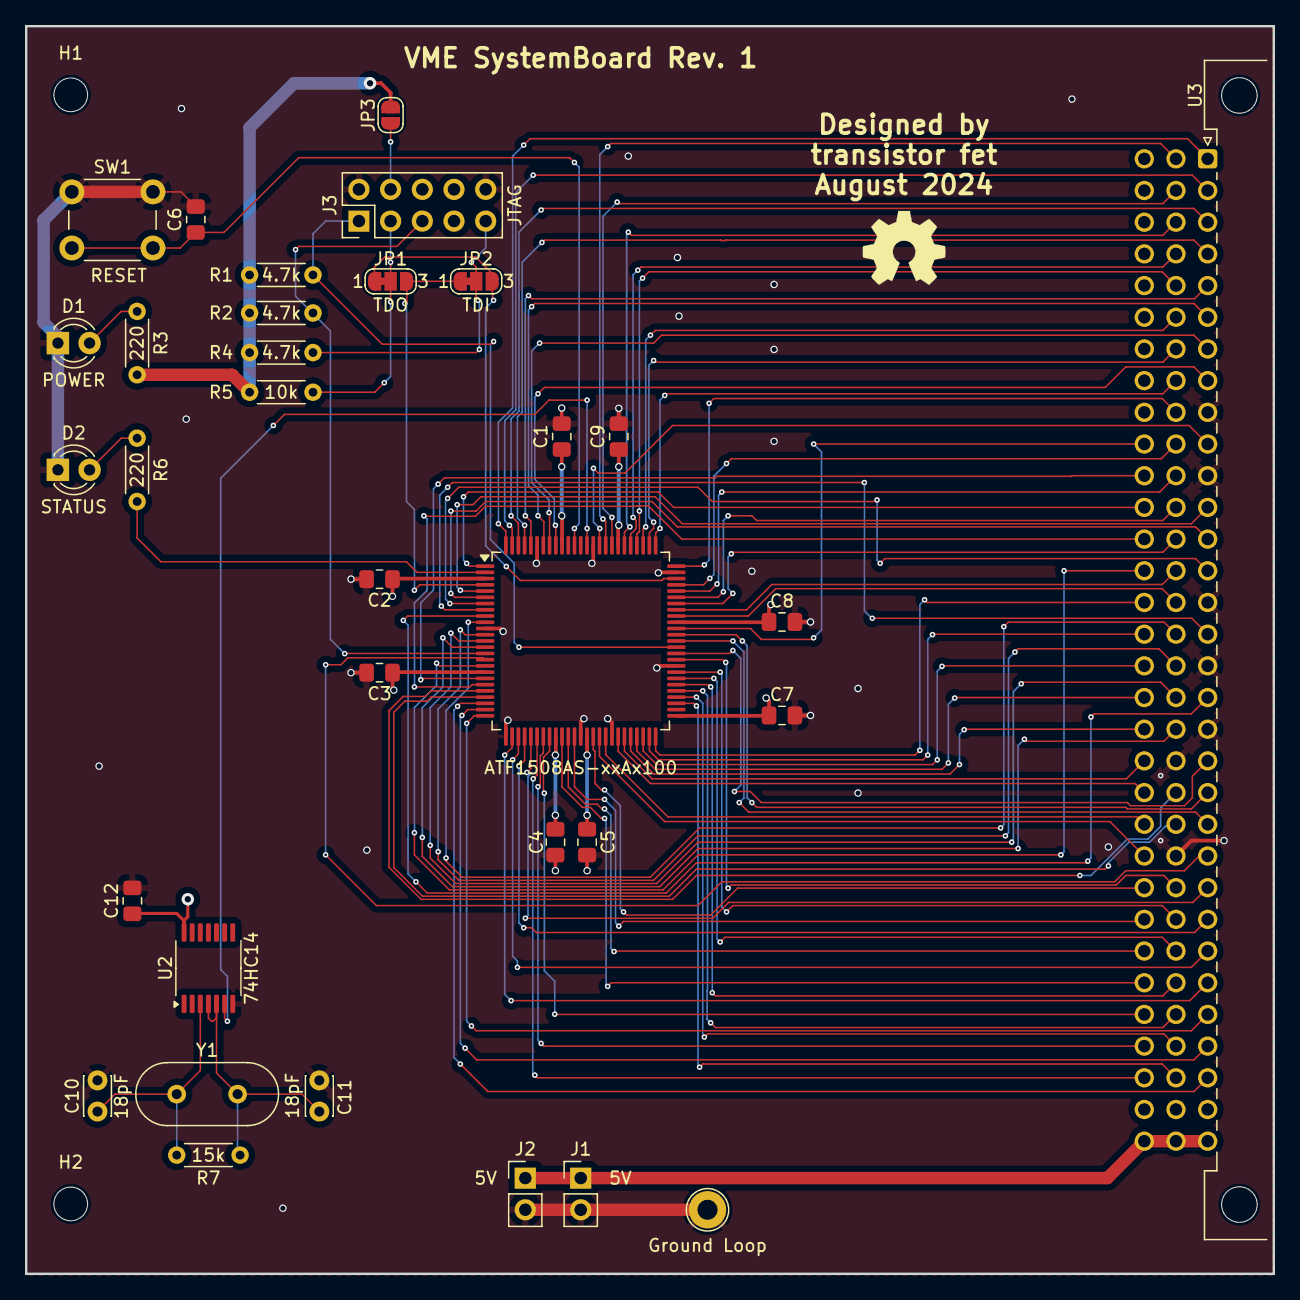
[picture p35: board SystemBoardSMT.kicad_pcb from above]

Board: 4 copper layers, 100.0 x 100.0 mm, 36 parts (0 on the bottom side), 90 nets.

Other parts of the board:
C10, C11: 18pF; C_Disc_D3.0mm_W2.0mm_P2.50mm
R7: 15k; R_Axial_DIN0204_L3.6mm_D1.6mm_P5.08mm_Horizontal

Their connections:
GND: C10.2, C11.2; also elsewhere on the board

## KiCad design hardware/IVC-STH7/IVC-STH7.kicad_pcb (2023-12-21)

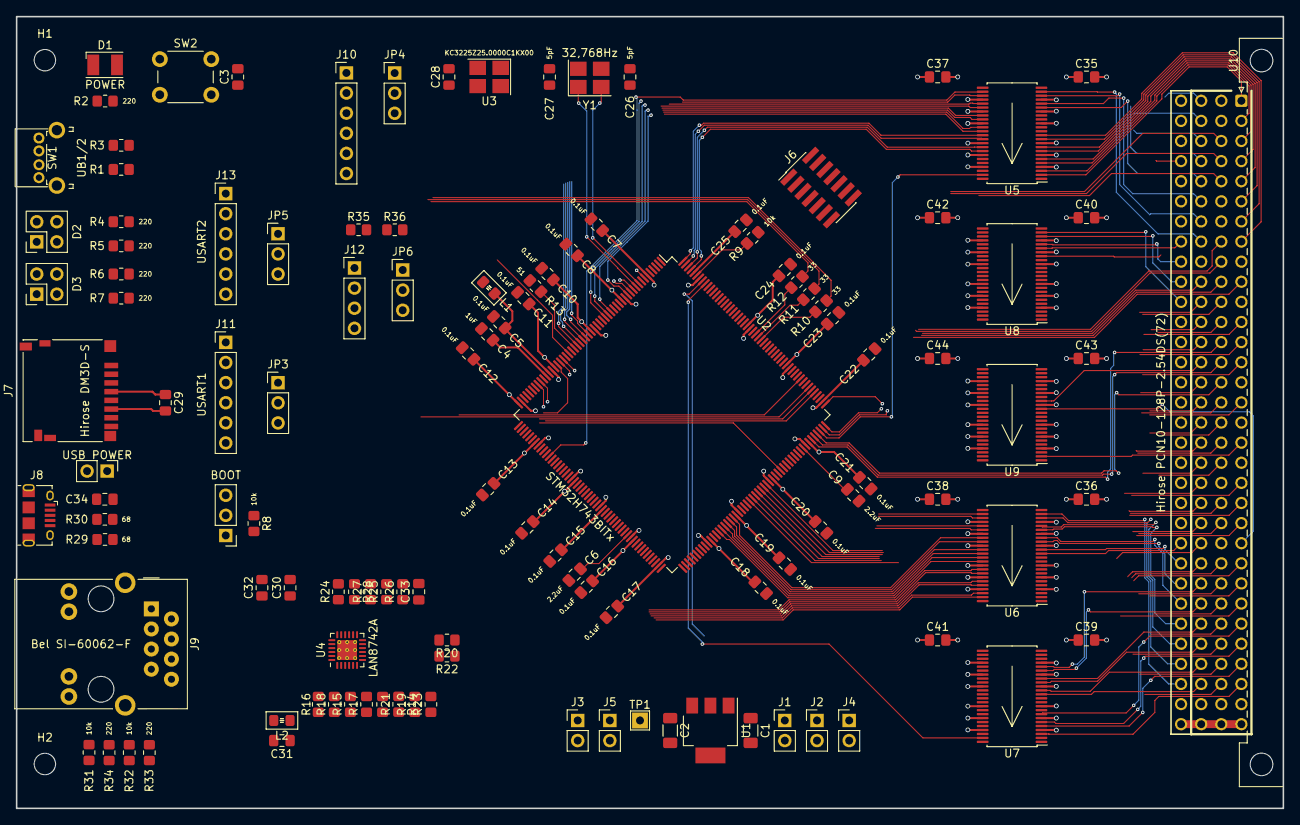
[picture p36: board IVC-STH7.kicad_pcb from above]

Board: 4 copper layers, 160.0 x 100.0 mm, 120 parts (0 on the bottom side), 282 nets.

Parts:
C1, C2: 4.7uF; C_1206_3216Metric_Pad1.33x1.80mm_HandSolder
C3, C5, C7, C8, C10, C11, C12, C13, C14, C15, C16, C17, C18, C19, C20, C21, C22, C23, C24, C25, C28, C29, C30, C31, C32, C34, C35, C36, C37, C38, C39, C40, C41, C42, C43, C44: 0.1uF; C_0805_2012Metric_Pad1.18x1.45mm_HandSolder
C4: 1uF; C_0805_2012Metric_Pad1.18x1.45mm_HandSolder
C6, C9: 2.2uF; C_0805_2012Metric_Pad1.18x1.45mm_HandSolder
C26, C27: 5pF; C_0805_2012Metric_Pad1.18x1.45mm_HandSolder
C33: 10uF; C_0805_2012Metric_Pad1.18x1.45mm_HandSolder
D1: POWER; LED_PLCC-2_3.4x3.0mm_KA
D2: Dialight 5530188F; Dialight 553-0xxxF
D3: Dialight 5530177F; Dialight 553-0xxxF
H1, H2: MountingHole; MountingHole_2.7mm_M2.5_DIN965
J1, J2, J4: 5V; PinHeader_1x02_P2.54mm_Vertical
J3, J5: 3.3V; PinHeader_1x02_P2.54mm_Vertical
J6: Conn_ST_STDC14; PinHeader_2x07_P1.27mm_Vertical_SMD
J7: Hirose DM3D-S; microSD_HC_Hirose_DM3D-SF
J8: Amphenol 10118194-0001LF; USB_Micro-B_Amphenol_10118194_Horizontal
J9: Bel SI-60062-F; RJ45_Bel_SI-60062-F
J10: SPI2; PinHeader_1x06_P2.54mm_Vertical
J11: USART1; PinHeader_1x06_P2.54mm_Vertical
J12: I^{2}C1; PinHeader_1x04_P2.54mm_Vertical
J13: USART2; PinHeader_1x06_P2.54mm_Vertical
JP1: BOOT; PinHeader_1x03_P2.54mm_Vertical
JP2: USB POWER; PinHeader_1x02_P2.54mm_Vertical
JP3: USART1; PinHeader_1x03_P2.54mm_Vertical
JP4: SPI1; PinHeader_1x03_P2.54mm_Vertical
JP5: USART2; PinHeader_1x03_P2.54mm_Vertical
JP6: I^{2}C1; PinHeader_1x03_P2.54mm_Vertical
L1, L2: 600Ω @ 100MHz (MI0805K601R-10); Ferrite_0805_2012Metric_Pad1.15x1.40mm_BigPads
R1, R3, R8, R9, R14, R15, R16, R21, R22, R31, R32: 10k; R_0805_2012Metric_Pad1.20x1.40mm_HandSolder
R2, R4, R5, R6, R7, R33, R34: 220; R_0805_2012Metric_Pad1.20x1.40mm_HandSolder
R10, R11, R12, R17, R18, R19, R20: 33; R_0805_2012Metric_Pad1.20x1.40mm_HandSolder
R13: 51; R_0805_2012Metric_Pad1.20x1.40mm_HandSolder
R23: 1.5k; R_0805_2012Metric_Pad1.20x1.40mm_HandSolder
R24: 12.1k; R_0805_2012Metric_Pad1.20x1.40mm_HandSolder
R25, R26, R27, R28: 50; R_0805_2012Metric_Pad1.20x1.40mm_HandSolder
R29, R30: 68; R_0805_2012Metric_Pad1.20x1.40mm_HandSolder
R35, R36: 4.7k; R_0805_2012Metric_Pad1.20x1.40mm_HandSolder
SW1: UB1/2; E-Switch TL2243
SW2: ~{RESET}; SW_PUSH_6mm
TP1: 3.3V; TestPoint_THTPad_2.0x2.0mm_Drill1.0mm
U1: AP7361EA-33E-13; SOT-223
U2: STM32H743BITx; LQFP-208_28x28mm_P0.5mm
U3: KC3225Z25.0000C1KX00; Crystal_SMD_3225-4Pin_3.2x2.5mm_HandSoldering
U4: LAN8742A; VQFN-24-1EP_4x4mm_P0.5mm_EP2.5x2.5mm_ThermalVias
U5, U6, U7, U8, U9: 74ALVC16245DG; TSSOP-48_6.1x12.5mm_P0.5mm
U10: Hirose PCN10-128P-2.54DS(72); DIN41612_C_4x32_Male_Horizontal_THT
Y1: 32,768Hz; Crystal_SMD_3225-4Pin_3.2x2.5mm_HandSoldering

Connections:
+3.3V: C2.1, C7.1, C8.1, C10.1, C11.1, C12.1, C13.1, C14.1, C15.1, C16.1, C17.1, C18.1, C19.1, C20.1, C21.1, C22.1, C23.1, C24.1, C25.1, C28.1, C29.1, C30.1, C37.1, C38.1, C41.1, C42.1, C44.1, J3.1, J5.1, J6.3 (VCC), J7.4 (VDD), JP3.3 (B), JP4.3 (B), JP5.3 (B), JP6.3 (B), L1.2, L2.2, R1.1, R2.1, R3.1, R8.1, R9.1, R15.1, R16.1, R21.1, R22.1, R23.1, TP1.1, U1.3 (VO), U2.6 (VBAT), U2.15 (VDD), U2.26 (VDD), U2.39 (VDD), U2.52 (VDD), U2.59 (VDD), U2.73 (VDD), U2.83 (VDD), U2.94 (VDD), U2.103 (VDD), U2.115 (VDD), U2.124 (VDD), U2.137 (VDD33_USB), U2.150 (VDD), U2.158 (VDD), U2.171 (VDD), U2.185 (VDD), U2.204 (VDD), U3.1 (INH), U3.4 (VCC), U4.9 (VDDIO), U5.31 (VCCa), U5.42 (VCCa), U6.31 (VCCa), U6.42 (VCCa), U7.31 (VCCa), U7.42 (VCCa), U8.31 (VCCa), U8.42 (VCCa), U9.31 (VCCa), U9.42 (VCCa)
+5V: C1.1, C34.1, C35.2, C36.2, C39.2, C40.2, C43.2, J1.1, J2.1, J4.1, JP2.1 (A), JP3.1 (A), JP4.1 (A), JP5.1 (A), JP6.1 (A), U1.1 (VI), U5.7 (VCCb), U5.18 (VCCb), U6.7 (VCCb), U6.18 (VCCb), U7.7 (VCCb), U7.18 (VCCb), U8.7 (VCCb), U8.18 (VCCb), U9.7 (VCCb), U9.18 (VCCb), U10.a32 (+5V), U10.b32 (+5V), U10.c32 (+5V), U10.d1 (+5V), U10.d13 (+5V), U10.d32 (+5V)
/IO/RD+: J9.4 (RD+), R27.2, U4.23 (RXP)
/IO/RD-: J9.6 (RD-), R28.2, U4.22 (RXN)
/IO/TD+: J9.1 (TD+), R25.2, U4.21 (TXP)
/IO/TD-: J9.3 (TD-), R26.2, U4.20 (TXN)
AH_DIR: U2.54 (PA5), U6.24 (DIR2)
AL_DIR: U2.55 (PA6), U5.1 (DIR1), U5.24 (DIR2), U6.1 (DIR1)
CLK_25M: R13.2, U3.3 (CLK), U4.5 (XTAL1/CLKIN)
DH_DIR: U2.62 (PB1), U8.1 (DIR1), U8.24 (DIR2)
DL_DIR: U2.63 (PB2), U7.1 (DIR1), U7.24 (DIR2)
GND: C1.2, C2.2, C3.2, C4.1, C5.1, C6.2, C7.2, C8.2, C9.2, C10.2, C11.2, C12.2, C13.2, C14.2, C15.2, C16.2, C17.2, C18.2, C19.2, C20.2, C21.2, C22.2, C23.2, C24.2, C25.2, C26.2, C27.2, C28.2, C29.2, C30.2, C31.2, C32.2, C33.2, C34.2, C35.1, C36.1, C37.2, C38.2, C39.1, C40.1, C41.2, C42.2, C43.1, C44.2, D1.1 (K), D2.1 (A1), D2.3 (A2), D3.1 (A1), D3.3 (A2), J1.2, J2.2, J3.2, J4.2, J5.2, J6.5 (GND), J6.7 (GND), J6.11 (GNDDetect), J7.6 (VSS), J7.10 (SHIELD), J8.5 (GND), J8.6 (Shield), J9.8, J9.SH, J10.2, J11.6, J12.2, J13.6, JP1.3 (B), R14.2, R24.2, R31.2, R32.2, R33.2, R34.2, SW1.1 (C), SW1.3 (C), SW2.1, U1.2 (GND), U2.14 (VSS), U2.25 (VSS), U2.40 (VSSA), U2.51 (VSS), U2.60 (VSS), U2.72 (VSS), U2.82 (VSS), U2.93 (VSS), U2.114 (VSS), U2.125 (VSS), U2.136 (VSS), U2.149 (VSS), U2.170 (VSS), U2.184 (VSS), U2.202 (VSS), U3.2 (GND), U4.25 (VSS), U5.4 (GND), U5.10 (GND), U5.15 (GND), U5.21 (GND), U5.28 (GND), U5.34 (GND), U5.39 (GND), U5.45 (GND), U6.4 (GND), U6.10 (GND), U6.15 (GND), U6.21 (GND), U6.28 (GND), U6.34 (GND), U6.39 (GND), U6.45 (GND), U7.4 (GND), U7.10 (GND), U7.15 (GND), U7.21 (GND), U7.28 (GND), U7.34 (GND), U7.39 (GND), U7.45 (GND), U8.4 (GND), U8.10 (GND), U8.15 (GND), U8.21 (GND), U8.28 (GND), U8.34 (GND), U8.39 (GND), U8.45 (GND), U9.4 (GND), U9.10 (GND), U9.15 (GND), U9.21 (GND), U9.28 (GND), U9.34 (GND), U9.39 (GND), U9.45 (GND), U10.a9 (GND), U10.a11 (GND), U10.a15 (GND), U10.a17 (GND), U10.a19 (GND), U10.b20 (GND), U10.b23 (GND), U10.c9 (GND), U10.d2 (GND), U10.d12 (GND), U10.d22 (GND), U10.d31 (GND)
I2C_SCL: J12.3, R35.2, U2.198 (PB8)
I2C_SDA: J12.4, R36.2, U2.199 (PB9)
LA0: U2.200 (PE0), U7.47 (A0)
LA1: U2.201 (PE1), U7.46 (A1)
LA2: U2.1 (PE2), U7.44 (A2)
LA3: U2.2 (PE3), U7.43 (A3)
LA4: U2.3 (PE4), U7.41 (A4)
LA5: U2.4 (PE5), U7.40 (A5)
LA6: U2.5 (PE6), U7.38 (A6)
LA7: U2.79 (PE7), U7.37 (A7)
LA8: U2.80 (PE8), U7.36 (A8)
LA9: U2.81 (PE9), U7.35 (A9)
LA10: U2.84 (PE10), U7.33 (A10)
LA11: U2.85 (PE11), U7.32 (A11)
LA12: U2.86 (PE12), U7.30 (A12)
LA13: U2.87 (PE13), U7.29 (A13)
LA14: U2.88 (PE14), U7.27 (A14)
LA15: U2.89 (PE15), U7.26 (A15)
LA16: U2.16 (PF0), U8.47 (A0)
LA17: U2.17 (PF1), U8.46 (A1)
LA18: U2.18 (PF2), U8.44 (A2)
LA19: U2.22 (PF3), U8.43 (A3)
LA20: U2.23 (PF4), U8.41 (A4)
LA21: U2.24 (PF5), U8.40 (A5)
LA22: U2.27 (PF6), U8.38 (A6)
LA23: U2.28 (PF7), U8.37 (A7)
LA24: U2.29 (PF8), U8.36 (A8)
LA25: U2.30 (PF9), U8.35 (A9)
LA26: U2.31 (PF10), U8.33 (A10)
LA27: U2.70 (PF11), U8.32 (A11)
LA28: U2.71 (PF12), U8.30 (A12)
LA29: U2.74 (PF13), U8.29 (A13)
LA30: U2.75 (PF14), U8.27 (A14)
LA31: U2.76 (PF15), U8.26 (A15)
LAM0: U2.132 (PG5), U9.40 (A5)
LAM1: U2.133 (PG6), U9.38 (A6)
LAM2: U2.134 (PG7), U9.37 (A7)
LAM3: U2.135 (PG8), U9.36 (A8)
LAM4: U2.178 (PG9), U9.35 (A9)
LAM5: U2.179 (PG10), U9.33 (A10)
LD0: U2.154 (PI0), U5.47 (A0)
LD1: U2.155 (PI1), U5.46 (A1)
LD2: U2.156 (PI2), U5.44 (A2)
LD3: U2.157 (PI3), U5.43 (A3)
LD4: U2.205 (PI4), U5.41 (A4)
LD5: U2.206 (PI5), U5.40 (A5)
LD6: U2.207 (PI6), U5.38 (A6)
LD7: U2.208 (PI7), U5.37 (A7)
LD8: U2.7 (PI8), U5.36 (A8)
LD9: U2.11 (PI9), U5.35 (A9)
LD10: U2.12 (PI10), U5.33 (A10)
LD11: U2.13 (PI11), U5.32 (A11)
LD12: U2.19 (PI12), U5.30 (A12)
LD13: U2.20 (PI13), U5.29 (A13)
LD14: U2.21 (PI14), U5.27 (A14)
LD15: U2.64 (PI15), U5.26 (A15)
LD16: U2.65 (PJ0), U6.47 (A0)
LD17: U2.66 (PJ1), U6.46 (A1)
LD18: U2.67 (PJ2), U6.44 (A2)
LD19: U2.68 (PJ3), U6.43 (A3)
LD20: U2.69 (PJ4), U6.41 (A4)
LD21: U2.95 (PJ5), U6.40 (A5)
LD22: U2.118 (PJ6), U6.38 (A6)
LD23: U2.119 (PJ7), U6.37 (A7)
LD24: U2.120 (PJ8), U6.36 (A8)
LD25: U2.121 (PJ9), U6.35 (A9)
LD26: U2.122 (PJ10), U6.33 (A10)
LD27: U2.123 (PJ11), U6.32 (A11)
LD28: U2.174 (PJ12), U6.30 (A12)
LD29: U2.175 (PJ13), U6.29 (A13)
LD30: U2.176 (PJ14), U6.27 (A14)
LD31: U2.177 (PJ15), U6.26 (A15)
unnamed: C6.1, U2.92 (VCAP)
unnamed: C9.1, U2.148 (VCAP)
unnamed: D1.2 (A), R2.2
unnamed: D2.2 (K1), R4.2
unnamed: D2.4 (K2), R5.2
unnamed: D3.2 (K1), R6.2
unnamed: D3.4 (K2), R7.2
unnamed: J8.3 (D+), R29.1
unnamed: J8.2 (D-), R30.1
unnamed: J8.1 (VBUS), JP2.2 (B)
unnamed: J9.L2, R34.1
unnamed: J9.L4, R33.1
unnamed: C32.1, C33.1, J9.2 (TCT), J9.5 (RCT), L2.1, R25.1, R26.1, R27.1, R28.1, U4.1 (VDD2A), U4.19 (VDD1A)
unnamed: J10.1, JP4.2 (C)
unnamed: J11.4, JP3.2 (C)
unnamed: J12.1, JP6.2 (C), R35.1, R36.1
unnamed: J13.4, JP5.2 (C)
unnamed: JP1.1 (A), R8.2
unnamed: JP1.2 (C), U2.197 (BOOT0)
unnamed: C26.1, U2.9 (PC14), Y1.2
unnamed: C27.1, U2.10 (PC15), Y1.1
unnamed: R10.1, U2.180 (PG11)
unnamed: R11.1, U2.181 (PG12)
unnamed: R12.1, U2.182 (PG13)
unnamed: R13.1, U2.32 (PH0)
unnamed: R9.2, U2.203 (PDR_ON)
unnamed: C4.2, C5.2, L1.1, U2.41 (VREF+), U2.42 (VDDA)
unnamed: R19.2, R21.2, U4.11 (CRS_DV/MODE2)
unnamed: J9.L1, R31.1, U4.3 (LED1/REGOFF)
unnamed: R24.1, U4.24 (RBIAS)
unnamed: R15.2, R17.2, U4.8 (RXD0/MODE0)
unnamed: R16.2, R18.2, U4.7 (RXD1/MODE1)
unnamed: R14.1, U4.10 (RXER/PHYAD0)
unnamed: C31.1, U4.6 (VDDCR)
unnamed: R20.2, R22.2, U4.14 (~INT/REFCLKO)
RMII_CRS_DV: R19.1, U2.56 (PA7)
RMII_MDC: U2.36 (PC1), U4.13 (MDC)
RMII_MDIO: R23.2, U2.45 (PA2), U4.12 (MDIO)
RMII_REF_CLK: R20.1, U2.44 (PA1)
RMII_RXD0: R17.1, U2.57 (PC4)
RMII_RXD1: R18.1, U2.58 (PC5)
RMII_TXD0: R12.2, U4.17 (TXD0)
RMII_TXD1: R11.2, U4.18 (TXD1)
RMII_TXEN: R10.2, U4.16 (TXEN)
RMII_nINT: J9.L3, R32.1, U2.37 (PC2_C), U4.2 (LED2/~INTSEL)
SDIO_CLK: J7.5 (CLK), U2.163 (PC12)
SDIO_CMD: J7.3 (CMD), U2.166 (PD2)
SDIO_D0: J7.7 (DAT0), U2.140 (PC8)
SDIO_D1: J7.8 (DAT1), U2.141 (PC9)
SDIO_D2: J7.1 (DAT2), U2.161 (PC10)
SDIO_D3: J7.2 (DAT3/CD), U2.162 (PC11)
SDIO_DET: J7.9 (DET), U2.38 (PC3_C)
SPI_SCK: J10.5, U2.105 (PB13)
SPI_SDI: J10.4, U2.107 (PB15)
SPI_SDO: J10.3, U2.106 (PB14)
TCK/SWCLK: J6.6 (JCLK/SWCLK), U2.159 (PA14)
TDI: J6.10 (JTDI/NC), U2.160 (PA15)
TDO/SWO: J6.8 (JTDO/SWO), U2.192 (PB3)
TMS/SWDIO: J6.4 (JTMS/SWDIO), U2.147 (PA13)
UB1: R1.2, SW1.2 (D), U2.143 (PA9)
UB2: R3.2, SW1.4 (D), U2.110 (PD10)
UL1: R4.1, U2.35 (PC0)
UL2: R5.1, U2.138 (PC6)
UL3: R6.1, U2.139 (PC7)
UL4: R7.1, U2.8 (PC13)
USART1_CTS: J11.1, U2.111 (PD11)
USART1_RTS: J11.5, U2.112 (PD12)
USART1_RX: J11.3, U2.109 (PD9)
USART1_TX: J11.2, U2.108 (PD8)
USART2_CTS: J13.1, U2.167 (PD3)
USART2_RTS: J13.5, U2.168 (PD4)
USART2_RX: J13.3, U2.172 (PD6)
USART2_TX: J13.2, U2.169 (PD5)
USB_DN: R30.2, U2.145 (PA11)
USB_DP: R29.2, U2.146 (PA12)
USB_ID: J8.4 (ID), U2.144 (PA10)
VA1: U7.3 (B1), U10.a30 (A01)
VA2: U7.5 (B2), U10.a29 (A02)
VA3: U7.6 (B3), U10.a28 (A03)
VA4: U7.8 (B4), U10.a27 (A04)
VA5: U7.9 (B5), U10.a26 (A05)
VA6: U7.11 (B6), U10.a25 (A06)
VA7: U7.12 (B7), U10.a24 (A07)
VA8: U7.13 (B8), U10.c30 (A8)
VA9: U7.14 (B9), U10.c29 (A9)
VA10: U7.16 (B10), U10.c28 (A10)
VA11: U7.17 (B11), U10.c27 (A11)
VA12: U7.19 (B12), U10.c26 (A12)
VA13: U7.20 (B13), U10.c25 (A13)
VA14: U7.22 (B14), U10.c24 (A14)
VA15: U7.23 (B15), U10.c23 (A15)
VA16: U8.2 (B0), U10.c22 (A16)
VA17: U8.3 (B1), U10.c21 (A17)
VA18: U8.5 (B2), U10.c20 (A18)
VA19: U8.6 (B3), U10.c19 (A19)
VA20: U8.8 (B4), U10.c18 (A20)
VA21: U8.9 (B5), U10.c17 (A21)
VA22: U8.11 (B6), U10.c16 (A22)
VA23: U8.12 (B7), U10.c15 (A23)
VA24: U8.13 (B8), U10.d4 (A24)
VA25: U8.14 (B9), U10.d5 (A25)
VA26: U8.16 (B10), U10.d6 (A26)
VA27: U8.17 (B11), U10.d7 (A27)
VA28: U8.19 (B12), U10.d8 (A28)
VA29: U8.20 (B13), U10.d9 (A29)
VA30: U8.22 (B14), U10.d10 (A30)
VA31: U8.23 (B15), U10.d11 (A31)
VAM0: U9.9 (B5), U10.b16 (AM0)
VAM1: U9.11 (B6), U10.b17 (AM1)
VAM2: U9.12 (B7), U10.b18 (AM2)
VAM3: U9.13 (B8), U10.b19 (AM3)
VAM4: U9.14 (B9), U10.a23 (AM4)
VAM5: U9.16 (B10), U10.c14 (AM5)
VCP_RX: J6.13 (VCP_RX), U2.196 (PB7)
VCP_TX: J6.14 (VCP_TX), U2.195 (PB6)
VD0: U5.2 (B0), U10.a1 (D00)
VD1: U5.3 (B1), U10.a2 (D01)
VD2: U5.5 (B2), U10.a3 (D02)
VD3: U5.6 (B3), U10.a4 (D03)
VD4: U5.8 (B4), U10.a5 (D04)
VD5: U5.9 (B5), U10.a6 (D05)
VD6: U5.11 (B6), U10.a7 (D06)
VD7: U5.12 (B7), U10.a8 (D07)
VD8: U5.13 (B8), U10.c1 (D08)
VD9: U5.14 (B9), U10.c2 (D09)
VD10: U5.16 (B10), U10.c3 (D10)
VD11: U5.17 (B11), U10.c4 (D11)
VD12: U5.19 (B12), U10.c5 (D12)
VD13: U5.20 (B13), U10.c6 (D13)
VD14: U5.22 (B14), U10.c7 (D14)
VD15: U5.23 (B15), U10.c8 (D15)
VD16: U6.2 (B0), U10.d14 (D16)
VD17: U6.3 (B1), U10.d15 (D17)
VD18: U6.5 (B2), U10.d16 (D18)
VD19: U6.6 (B3), U10.d17 (D19)
VD20: U6.8 (B4), U10.d18 (D20)
VD21: U6.9 (B5), U10.d19 (D21)
VD22: U6.11 (B6), U10.d20 (D22)
VD23: U6.12 (B7), U10.d21 (D23)
VD24: U6.13 (B8), U10.d23 (D24)
VD25: U6.14 (B9), U10.d24 (D25)
VD26: U6.16 (B10), U10.d25 (D26)
VD27: U6.17 (B11), U10.d26 (D27)
VD28: U6.19 (B12), U10.d27 (D28)
VD29: U6.20 (B13), U10.d28 (D29)
VD30: U6.22 (B14), U10.d29 (D30)
VD31: U6.23 (B15), U10.d30 (D31)
~AH_OE: U2.50 (PA3), U6.25 (~OE2)
~AL_OE: U2.53 (PA4), U5.25 (~OE2), U5.48 (~OE1), U6.48 (~OE1)
~CTRL_DIR: U2.194 (PB5), U9.1 (DIR1), U9.24 (DIR2)
~CTRL_OE: U2.193 (PB4), U9.25 (~OE2), U9.48 (~OE1)
~DH_OE: U2.142 (PA8), U8.25 (~OE2), U8.48 (~OE1)
~DL_OE: U2.61 (PB0), U7.25 (~OE2), U7.48 (~OE1)
~LAS: U2.77 (PG0), U9.47 (A0)
~LDS0: U2.129 (PG2), U9.44 (A2)
~LDS1: U2.78 (PG1), U9.46 (A1)
~LLWORD: U2.131 (PG4), U9.41 (A4)
~LWRITE: U2.130 (PG3), U9.43 (A3)
~RESET: C3.1, J6.12 (~RST), SW2.2, U2.34 (NRST), U4.15 (~RST)
~SPI_CS: J10.6, U2.104 (PB12)
~VACFAIL: U2.113 (PD13), U10.b3 (~ACFAIL)
~VAS: U9.2 (B0), U10.a18 (~AS)
~VBBSY: U2.46 (PH2), U10.b1 (~BBSY)
~VBCLR: U2.47 (PH3), U10.b2 (~BCLR)
~VBERR: U2.191 (PG15), U10.c11 (~BERR)
~VBG0IN: U2.48 (PH4), U10.b4 (~BG0IN)
~VBG0OUT: U2.49 (PH5), U10.b5 (~BG0OUT)
~VBG1IN: U2.96 (PH6), U10.b6 (~BG1IN)
~VBG1OUT: U2.97 (PH7), U10.b7 (~BG1OUT)
~VBG2IN: U2.98 (PH8), U10.b8 (~BG2IN)
~VBG2OUT: U2.99 (PH9), U10.b9 (~BG2OUT)
~VBG3IN: U2.100 (PH10), U10.b10 (~BG3IN)
~VBG3OUT: U2.101 (PH11), U10.b11 (~BG3OUT)
~VBR0: U2.102 (PH12), U10.b12 (~BR0)
~VBR1: U2.151 (PH13), U10.b13 (~BR1)
~VBR2: U2.152 (PH14), U10.b14 (~BR2)
~VBR3: U2.153 (PH15), U10.b15 (~BR3)
~VDS0: U9.5 (B2), U10.a13 (~DS0)
~VDS1: U9.3 (B1), U10.a12 (~DS1)
~VDTACK: U2.183 (PG14), U10.a16 (~DTACK)
~VIACKIN: U2.164 (PD0), U10.a21 (~IACKIN)
~VIACKOUT: U2.165 (PD1), U10.a22 (~IACKOUT)
~VIACK: U2.126 (PK0), U10.a20 (~IACK)
~VIRQ1: U2.127 (PK1), U10.b30 (~IRQ1)
~VIRQ2: U2.128 (PK2), U10.b29 (~IRQ2)
~VIRQ3: U2.186 (PK3), U10.b28 (~IRQ3)
~VIRQ4: U2.187 (PK4), U10.b27 (~IRQ4)
~VIRQ5: U2.188 (PK5), U10.b26 (~IRQ5)
~VIRQ6: U2.189 (PK6), U10.b25 (~IRQ6)
~VIRQ7: U2.190 (PK7), U10.b24 (~IRQ7)
~VLWORD: U9.8 (B4), U10.c13 (~LWORD)
~VRETRY: U2.173 (PD7), U10.d3 (~RETRY)
~VSERCLK: U2.90 (PB10), U10.b21 (SERCLK)
~VSERDAT: U2.91 (PB11), U10.b22 (SERDAT)
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

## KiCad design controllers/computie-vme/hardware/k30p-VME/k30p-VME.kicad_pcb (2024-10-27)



Board: 4 copper layers, 160.0 x 100.0 mm, 111 parts (5 on the bottom side), 245 nets.

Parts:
C1: 0.47uF; C_0805_2012Metric_Pad1.18x1.45mm_HandSolder
C2, C3: 18pF; C_Disc_D3.0mm_W2.0mm_P2.50mm
C4: 15pF; C_Disc_D3.0mm_W2.0mm_P2.50mm
C5: 5pF; C_Disc_D3.0mm_W2.0mm_P2.50mm
C6, C7, C12, C13, C14, C15, C16, C17, C18, C19, C20, C21, C22, C23, C24, C25, C26, C27, C28, C29, C30, C31, C32, C33: 0.1uF; C_0805_2012Metric_Pad1.18x1.45mm_HandSolder
C8, C9, C10, C11: 47pF; C_0805_2012Metric_Pad1.18x1.45mm_HandSolder
D1: Harvatek HV-32H307B; Harvatek_HV-32312-260-2SUB
D2, D3: Harvatek HV-32312; Harvatek_HV-32312-260-2SUB
D4, D5: IN; LED_1206_3216Metric_Pad1.42x1.75mm_HandSolder
D6, D7: OUT; LED_1206_3216Metric_Pad1.42x1.75mm_HandSolder
H1, H2: MountingHole; MountingHole_2.7mm_M2.5_DIN965
J1, J2: 5V; PinHeader_1x02_P2.54mm_Vertical
J3: JTAG; PinHeader_2x05_P2.54mm_Vertical
J4: Serial1; PinHeader_1x06_P2.54mm_Vertical
J5: Serial2; PinHeader_1x06_P2.54mm_Vertical
JP1: CDIS; PinHeader_1x02_P2.54mm_Vertical
JP2: MMUDIS; PinHeader_1x02_P2.54mm_Vertical
JP3: Vcc; SolderJumper-2_P1.3mm_Open_RoundedPad1.0x1.5mm
JP4: USB POWER; PinHeader_1x02_P2.54mm_Vertical
JP5: BG0IN; PinHeader_1x02_P2.54mm_Vertical
JP6: BG0OUT; PinHeader_1x02_P2.54mm_Vertical
JP7: BR0; PinHeader_1x02_P2.54mm_Vertical
JP8: SUSPEND; PinHeader_1x02_P2.54mm_Vertical
L1: MI0805K601R-10; Ferrite_0805_2012Metric_Pad1.15x1.40mm_BigPads
P1: VME64-P1-3R; DIN41612_C_3x32_Male_Horizontal_THT
R1, R3, R12, R13, R14, R15: 1k; R_0805_2012Metric_Pad1.20x1.40mm_HandSolder
R2, R16, R17, R18, R19: 220; R_0805_2012Metric_Pad1.20x1.40mm_HandSolder
R4, R9, R10, R11: 10k; R_0805_2012Metric_Pad1.20x1.40mm_HandSolder
R5: 15k; R_0805_2012Metric_Pad1.20x1.40mm_HandSolder
R6, R7, R8: 4.7k; R_0805_2012Metric_Pad1.20x1.40mm_HandSolder
R20, R21, R22, R23: 68; R_0805_2012Metric_Pad1.20x1.40mm_HandSolder
RN1, RN2, RN3, RN4: CAT16-103J4LF; R_Cat16-4
S1: Logo_Open_Hardware_Small; OSHW-Symbol_6.7x6mm_SilkScreen
SW1: ~{RESET}; E-Switch_TL1105
SW2: E-Switch TL2243; E-Switch_TL2243
TP1: Ground Loop; TestPoint_Loop_D2.60mm_Drill1.6mm_Beaded
TP5: IP3; TestPoint_THTPad_2.0x2.0mm_Drill1.0mm
TP6: IP2; TestPoint_THTPad_2.0x2.0mm_Drill1.0mm
U1: MC68030RC; PGA-128_13x13_THT-Socket
U2: 74HC14; TSSOP-14_4.4x5mm_P0.65mm
U3: 74HC05; TSSOP-14_4.4x5mm_P0.65mm
U4: ATF1508AS-xxAx100; TQFP-100_14x14mm_P0.5mm
U5, U6: AS6C8016; TSOP-II-44_10.16x18.41mm_P0.8mm
U7: AM29F040; PLCC-32_THT-Socket
U8: MC68681; PLCC-44_THT-Socket
U9, U10: FT231XS; SSOP-20_3.9x8.7mm_P0.635mm
U11, U12, U13, U14, U15: 74ABT16245DL; TSSOP-48_6.1x12.5mm_P0.5mm
U16: 74HC148; SOIC-16_3.9x9.9mm_P1.27mm
U17: 74LS30; TSSOP-14_4.4x5mm_P0.65mm
USB1, USB2: USB_C_Plug_USB2.0; USB_C_Receptacle_GCT_USB4105-xx-A_16P_TopMnt_Horizontal
Y1, Y2: Crystal; Crystal_HC49-4H_Vertical

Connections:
+5V: C12.1, C13.1, C14.1, C15.1, C16.1, C17.1, C18.1, C19.1, C20.1, C21.1, C22.1, C23.1, C24.1, C25.1, C26.1, C27.1, C28.1, C29.1, C30.1, C31.1, C32.1, C33.1, J1.1, J2.1, JP3.2 (B), JP4.1 (A), P1.a32 (+5V), P1.b32 (+5V), P1.c32 (+5V), R1.2, R4.1, R6.1, R7.1, R8.1, R9.1, R12.2, R13.2, R14.2, R15.2, RN1.5 (R4.2), RN1.6 (R3.2), RN1.7 (R2.2), RN1.8 (R1.2), RN2.5 (R4.2), RN2.6 (R3.2), RN2.7 (R2.2), RN2.8 (R1.2), RN3.5 (R4.2), RN3.6 (R3.2), RN3.7 (R2.2), RN3.8 (R1.2), RN4.5 (R4.2), RN4.6 (R3.2), RN4.7 (R2.2), RN4.8 (R1.2), SW2.2 (D), SW2.4 (D), U1.C6 (VCC), U1.D4 (VCC), U1.D10 (VCC), U1.F2 (VCC), U1.F11 (VCC), U1.H3 (VCC), U1.H11 (VCC), U1.K4 (VCC), U1.K10 (VCC), U1.L6 (VCC), U2.14 (VCC), U3.14 (VCC), U4.3 (VCCIO), U4.18 (VCCIO), U4.34 (VCCIO), U4.39 (VCCINT), U4.51 (VCCIO), U4.66 (VCCIO), U4.82 (VCCIO), U4.91 (VCCINT), U5.11 (VCC), U5.33 (VCC), U6.11 (VCC), U6.33 (VCC), U7.32 (VCC), U8.44 (VCC), U9.15 (VCC), U10.15 (VCC), U11.7 (VCC), U11.18 (VCC), U11.31 (VCC), U11.42 (VCC), U12.7 (VCC), U12.18 (VCC), U12.31 (VCC), U12.42 (VCC), U13.7 (VCC), U13.18 (VCC), U13.31 (VCC), U13.42 (VCC), U14.7 (VCC), U14.18 (VCC), U14.31 (VCC), U14.42 (VCC), U15.7 (VCC), U15.18 (VCC), U15.31 (VCC), U15.42 (VCC), U16.16 (VCC), U17.14 (VCC)
CPU_CLK: U1.E1 (CLK), U4.83 (I/O)
D16X_DIR: U4.94 (I/O), U13.1 (DIR1), U13.24 (DIR2)
DL_DIR: U4.97 (I/O), U14.1 (DIR1), U14.24 (DIR2)
FC0: U1.D2 (FC0), U4.12 (I/O)
FC1: U1.C1 (FC1), U4.13 (I/O)
FC2: U1.D1 (FC2), U4.14 (I/O)
GND: C1.2, C2.2, C3.2, C4.1, C5.1, C6.2, C7.2, C8.2, C9.2, C10.2, C11.2, C12.2, C13.2, C14.2, C15.2, C16.2, C17.2, C18.2, C19.2, C20.2, C21.2, C22.2, C23.2, C24.2, C25.2, C26.2, C27.2, C28.2, C29.2, C30.2, C31.2, C32.2, C33.2, J1.2, J2.2, J3.2, J3.10, J4.6, J5.1, JP1.2 (B), JP2.2 (B), JP8.2 (B), P1.a9 (GND), P1.a11 (GND), P1.a15 (GND), P1.a17 (GND), P1.a19 (GND), P1.b20 (GND), P1.b23 (GND), P1.c9 (GND), R2.1, R3.1, R10.2, R11.2, SW1.1, TP1.1, U1.C5 (GND), U1.C7 (GND), U1.C9 (GND), U1.E3 (GND), U1.E11 (GND), U1.F3 (GND), U1.G3 (GND), U1.G11 (GND), U1.J3 (GND), U1.J11 (GND), U1.L5 (GND), U1.L7 (GND), U1.L8 (GND), U1.L9 (GND), U2.7 (GND), U3.7 (GND), U4.11 (GND), U4.26 (GND), U4.38 (GND), U4.43 (GND), U4.59 (GND), U4.74 (GND), U4.86 (GND), U4.95 (GND), U5.12 (VSS), U5.34 (VSS), U6.12 (VSS), U6.34 (VSS), U7.16 (GND), U8.22 (GND), U9.6 (GND), U9.16 (GND), U10.6 (GND), U10.16 (GND), U11.1 (DIR1), U11.4 (GND), U11.10 (GND), U11.15 (GND), U11.21 (GND), U11.24 (DIR2), U11.28 (GND), U11.34 (GND), U11.39 (GND), U11.45 (GND), U12.1 (DIR1), U12.4 (GND), U12.10 (GND), U12.15 (GND), U12.21 (GND), U12.24 (DIR2), U12.28 (GND), U12.34 (GND), U12.39 (GND), U12.45 (GND), U13.4 (GND), U13.10 (GND), U13.15 (GND), U13.21 (GND), U13.28 (GND), U13.34 (GND), U13.39 (GND), U13.45 (GND), U14.4 (GND), U14.10 (GND), U14.15 (GND), U14.21 (GND), U14.28 (GND), U14.34 (GND), U14.39 (GND), U14.45 (GND), U15.4 (GND), U15.10 (GND), U15.15 (GND), U15.21 (GND), U15.28 (GND), U15.34 (GND), U15.39 (GND), U15.45 (GND), U16.5 (EI), U16.8 (GND), U16.10 (IO), U17.7 (GND), USB1.A1 (GND), USB1.A12 (GND), USB1.B1 (GND), USB1.B12 (GND), USB1.S1 (SHIELD), USB2.A1 (GND), USB2.A12 (GND), USB2.B1 (GND), USB2.B12 (GND), USB2.S1 (SHIELD)
IP4: U4.54 (I/O), U8.43 (IP4)
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

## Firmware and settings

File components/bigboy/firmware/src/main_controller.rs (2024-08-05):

//#![deny(warnings)]
#![no_main]
#![no_std]

use panic_rtt_target as _;
use rtt_target::{rtt_init_print, rprintln};

use core::fmt::Write;
use hal::prelude::*;
use hal::gpio::PinState;
use hal::pac;
use stm32h7xx_hal as hal;
use hal::rcc::ResetEnable;

mod vme;
use vme::{Bus, BusPins, Transceiver, TransceiverPins, AddressModifier, AddressModifierPins, ControlPins, ControlBus, DataTransferBus, BusArbitration};

#[cortex_m_rt::entry]
fn main() -> ! {
    rtt_init_print!();
    rprintln!("booting");

    rprintln!("starting power");
    let mut cp = pac::CorePeripherals::take().unwrap();
    let dp = pac::Peripherals::take().unwrap();

    rprintln!("starting power");
    let pwr = dp.PWR.constrain();
    rprintln!("freezing power");
    let pwrcfg = pwr.freeze();

    let rcc = dp.RCC.constrain();
    let ccdr = rcc.sys_ck(200.MHz()).freeze(pwrcfg, &dp.SYSCFG);

    rprintln!("configuring I/O");
    let gpioa = dp.GPIOA.split(ccdr.peripheral.GPIOA);
    let gpiob = dp.GPIOB.split(ccdr.peripheral.GPIOB);
    let gpioc = dp.GPIOC.split(ccdr.peripheral.GPIOC);
    let gpiod = dp.GPIOD.split(ccdr.peripheral.GPIOD);

    let gpiog = dp.GPIOG.split(ccdr.peripheral.GPIOG);
    let gpioh = dp.GPIOH.split(ccdr.peripheral.GPIOH);
    let gpiok = dp.GPIOK.split(ccdr.peripheral.GPIOK);

    let mut led1 = gpioc.pc0.into_push_pull_output();
    let mut led2 = gpioa.pa3.into_push_pull_output();
    let mut led3 = gpioa.pa4.into_push_pull_output();
    let mut led4 = gpioc.pc13.into_push_pull_output();
    let button1 = gpioa.pa9.into_floating_input();


    let mut dl_oe = gpioa.pa5.into_push_pull_output();
    let mut dl_dir = gpioa.pa6.into_push_pull_output();
    let mut dh_oe = gpioc.pc6.into_push_pull_output();
    let mut dh_dir = gpioc.pc7.into_push_pull_output();
    let mut al_oe = gpiob.pb0.into_push_pull_output();
    let mut al_dir = gpiob.pb2.into_push_pull_output();
    let mut ah_oe = gpioa.pa8.into_push_pull_output();
    let mut ah_dir = gpiob.pb1.into_push_pull_output();
    let mut ctrl_oe = gpiob.pb4.into_push_pull_output();
    let mut ctrl_dir = gpiob.pb5.into_push_pull_output();
    al_oe.set_high();
    al_dir.set_high(); // low = INPUT (from bus), high = OUTPUT (to bus)
    ah_oe.set_high();
    ah_dir.set_high(); // low = INPUT (from bus), high = OUTPUT (to bus)
    dl_oe.set_high();
    dl_dir.set_high(); // low = INPUT (from bus), high = OUTPUT (to bus)
    dh_oe.set_high();
    dh_dir.set_high(); // low = INPUT (from bus), high = OUTPUT (to bus)
    ctrl_oe.set_high();
    ctrl_dir.set_high(); // low = INPUT (from bus), high = OUTPUT (to bus)


    let al = TransceiverPins::new(al_oe, al_dir);
    let ah = TransceiverPins::new(ah_oe, ah_dir);
    let dl = TransceiverPins::new(dl_oe, dl_dir);
    let dh = TransceiverPins::new(dh_oe, dh_dir);
    let ctrl = TransceiverPins::new(ctrl_oe, ctrl_dir);

    ccdr.peripheral.GPIOE.enable().reset();
    ccdr.peripheral.GPIOF.enable().reset();
    ccdr.peripheral.GPIOI.enable().reset();
    ccdr.peripheral.GPIOJ.enable().reset();
    let address_bus = BusPins::new("address", ah, al, dp.GPIOF, dp.GPIOE);
    let data_bus = BusPins::new("data", dh, dl, dp.GPIOJ, dp.GPIOI);

    let address_strobe = gpiog.pg0.into_push_pull_output();
    let data_strobe0 = gpiog.pg2.into_push_pull_output();
    let data_strobe1 = gpiog.pg1.into_push_pull_output();
    let write = gpiog.pg3.into_push_pull_output();
    let lword = gpiog.pg4.into_push_pull_output();

    let am0 = gpiog.pg5.into_push_pull_output();
    let am1 = gpiog.pg6.into_push_pull_output();
    let am2 = gpiog.pg7.into_push_pull_output();
    let am3 = gpiog.pg8.into_push_pull_output();
    let am4 = gpiog.pg9.into_push_pull_output();
    let am5 = gpiog.pg10.into_push_pull_output();
    let address_modifier = AddressModifierPins::new(am0, am1, am2, am3, am4, am5);

    let dtack = gpiog.pg14.into_floating_input();
    let berr = gpiog.pg15.into_floating_input();
    let retry = gpiod.pd7.into_floating_input();

    let control_bus = ControlPins::new(
        ctrl,
        address_strobe,
        data_strobe0,
        data_strobe1,
        write,
        lword,
        address_modifier,
        dtack,
        berr,
        retry,
    );

    let mut vmebus = DataTransferBus::new(control_bus, address_bus, data_bus);

    let sysreset = gpioa.pa0.into_open_drain_output_in_state(PinState::High);
    let acfail = gpiod.pd13.into_open_drain_output_in_state(PinState::High);
    let sysfail = gpiod.pd14.into_open_drain_output_in_state(PinState::High);

    let bbsy = gpioh.ph2.into_open_drain_output_in_state(PinState::High).erase();
    let bclr = gpioh.ph3.into_open_drain_output_in_state(PinState::High).erase();

    let br0 = gpioh.ph12.into_open_drain_output_in_state(PinState::High).erase();
    let br1 = gpioh.ph13.into_open_drain_output_in_state(PinState::High).erase();
    let br2 = gpioh.ph14.into_open_drain_output_in_state(PinState::High).erase();
    let br3 = gpioh.ph15.into_open_drain_output_in_state(PinState::High).erase();

    let bg0in = gpioh.ph4.into_floating_input().erase();
    let bg0out = gpioh.ph5.into_push_pull_output_in_state(PinState::High).erase();
    let bg1in = gpioh.ph6.into_floating_input().erase();
    let bg1out = gpioh.ph7.into_push_pull_output_in_state(PinState::High).erase();
    let bg2in = gpioh.ph8.into_floating_input().erase();
    let bg2out = gpioh.ph9.into_push_pull_output_in_state(PinState::High).erase();
    let bg3in = gpioh.ph10.into_floating_input().erase();
    let bg3out = gpioh.ph11.into_push_pull_output_in_state(PinState::High).erase();

    let arbitration = BusArbitration {
        bbsy,
        bclr,
        br: [br0, br1, br2, br3],
        bgin: [bg0in, bg1in, bg2in, bg3in],
        bgout: [bg0out, bg1out, bg2out, bg3out],
    };

    let sysclk_pin = gpiod.pd15.into_alternate_af2();

    let (control, mut sysclk) = dp.TIM4
        .pwm_advanced(
            sysclk_pin,
            ccdr.peripheral.TIM4,
            &ccdr.clocks
        )
        .frequency(100.Hz())
        .center_aligned()
        .finalize();
    sysclk.set_duty(sysclk.get_max_duty() / 2);
    sysclk.enable();

    let mut delay = cp.SYST.delay(ccdr.clocks);
    //let mut output = gpioa.pa3.into_alternate();
    let mut timer = dp.TIM2.tick_timer(1.MHz(), ccdr.peripheral.TIM2, &ccdr.clocks);

    let tx = gpiod.pd8.into_alternate();
    let rx = gpiod.pd9.into_alternate();

    // Configure the serial peripheral
    let serial = dp
        .USART3
        .serial((tx, rx), 115_200.bps(), ccdr.peripheral.USART3, &ccdr.clocks)
        .unwrap();

    let (mut tx, mut rx) = serial.split();

    writeln!(tx, "Hello, world!").unwrap();

    led1.set_high();
    led2.set_high();
    led3.set_high();
    led4.set_high();

    // Configure the interrupt signals
    let iack = gpiok.pk0.into_open_drain_output_in_state(PinState::High);
    let irq = [
        gpiok.pk1.into_push_pull_output_in_state(PinState::High).erase(),
        gpiok.pk2.into_push_pull_output_in_state(PinState::High).erase(),
        gpiok.pk3.into_push_pull_output_in_state(PinState::High).erase(),
        gpiok.pk4.into_push_pull_output_in_state(PinState::High).erase(),
        gpiok.pk5.into_push_pull_output_in_state(PinState::High).erase(),
        gpiok.pk6.into_push_pull_output_in_state(PinState::High).erase(),
        gpiok.pk7.into_push_pull_output_in_state(PinState::High).erase(),
    ];

    let mut value = 0_u32;
    let mut latch = false;
    rprintln!("main loop");
    loop {
        //led1.toggle();
        //led2.toggle();
        //led3.toggle();
        //led4.toggle();
        //delay.delay_ms(1_u16);

        value += 1;
        //vmebus.data_bus.output(value);
        //vmebus.data_bus.output(value);

        //if (value ^ last) & 0x80 != 0 {
        //    let state = if value & 0x80 == 0 { PinState::Low } else { PinState::High };
        //    virq1.set_state(state);
        //    dtack.set_state(state);
        //    last = value;
        //}

        if button1.is_low() {
            latch = true;
        }

        if latch {
            //vmebus.write_a16(&mut delay, 0x0000, 0xAAAA).unwrap();
            for address in 0..8 {
                let data = vmebus.read_a16(&mut delay, address).unwrap();
                rprintln!("read in {:x}", data);
            }
            delay.delay_ms(100_u32);
            latch = false;
        }
    }

/*
    let mut value = false;
    rprintln!("main loop");
    loop {
        led1.toggle();
        led2.toggle();
        led3.toggle();
        led4.toggle();
        delay.delay_ms(100_u16);

        value = !value;
        if value {
            virq1.set_high();
            al_oe.set_low();
            dp.GPIOE.moder.write(|w| unsafe { w.bits(0x5555_5555) });
            dp.GPIOE.odr.write(|w| unsafe { w.bits(0xFFFF) });
        } else {
            virq1.set_low();
            al_oe.set_high();
            dp.GPIOE.moder.write(|w| unsafe { w.bits(0x0000_0000) });
        }
        //rprintln!("Led toggled");
    }
*/
}



/*
//! Demo for STM32H747I-DISCO eval board using the Real Time for the Masses
//! (RTIC) framework.
//!
//! STM32H747I-DISCO: RMII TXD1 is on PG12
//!
//! If you are using the following boards, you will need to change the TXD1 pin
//! assignment below!
//! NUCLEO-H743ZI2: RMII TXD1 is on PB13
//! NUCLEO-H745I-Q: RMII TXD1 is on PB13
//!
//! This demo responds to pings on 192.168.1.99 (IP address hardcoded below)
//!
//! We use the SysTick timer to create a 1ms timebase for use with smoltcp.
//!
//! The ethernet ring buffers are placed in SRAM3, where they can be
//! accessed by both the core and the Ethernet DMA.
//#![deny(warnings)]
#![no_main]
#![no_std]

use panic_rtt_target as _;
use rtt_target::{rtt_init_print, rprintln};

use core::mem::MaybeUninit;
use core::ptr::addr_of_mut;
use core::sync::atomic::AtomicU32;

use smoltcp::iface::{Config, Interface, SocketSet, SocketStorage};
use smoltcp::time::Instant;
use smoltcp::wire::{HardwareAddress, IpAddress, IpCidr};

use stm32h7xx_hal::{ethernet, rcc::CoreClocks, stm32};

/// Configure SYSTICK for 1ms timebase
fn systick_init(mut syst: stm32::SYST, clocks: CoreClocks) {
    let c_ck_mhz = clocks.c_ck().to_MHz();

    let syst_calib = 0x3E8;

    syst.set_clock_source(cortex_m::peripheral::syst::SystClkSource::Core);
    syst.set_reload((syst_calib * c_ck_mhz) - 1);
    syst.enable_interrupt();
    syst.enable_counter();
}

/// TIME is an atomic u32 that counts milliseconds.
static TIME: AtomicU32 = AtomicU32::new(0);

/// Locally administered MAC address
const MAC_ADDRESS: [u8; 6] = [0x02, 0x00, 0x11, 0x22, 0x33, 0x44];

/// Ethernet descriptor rings are a global singleton
#[link_section = ".sram3.eth"]
static mut DES_RING: ethernet::DesRing<4, 4> = ethernet::DesRing::new();

// This data will be held by Net through a mutable reference
pub struct NetStorageStatic<'a> {
    socket_storage: [SocketStorage<'a>; 8],
}
// MaybeUninit allows us write code that is correct even if STORE is not
// initialised by the runtime
static mut STORE: MaybeUninit<NetStorageStatic> = MaybeUninit::uninit();

pub struct Net<'a> {
    iface: Interface,
    ethdev: ethernet::EthernetDMA<4, 4>,
    sockets: SocketSet<'a>,
}
impl<'a> Net<'a> {
    pub fn new(
        store: &'a mut NetStorageStatic<'a>,
        mut ethdev: ethernet::EthernetDMA<4, 4>,
        ethernet_addr: HardwareAddress,
        now: Instant,
    ) -> Self {
        let config = Config::new(ethernet_addr);
        let mut iface = Interface::new(config, &mut ethdev, now);
        // Set IP address
        iface.update_ip_addrs(|addrs| {
            let _ = addrs.push(IpCidr::new(IpAddress::v4(192, 168, 2, 99), 0));
        });

        let sockets = SocketSet::new(&mut store.socket_storage[..]);

        Net::<'a> {
            iface,
            ethdev,
            sockets,
        }
    }

    /// Polls on the ethernet interface. You should refer to the smoltcp
    /// documentation for poll() to understand how to call poll efficiently
    pub fn poll(&mut self, now: i64) {
        let timestamp = Instant::from_millis(now);

        self.iface
            .poll(timestamp, &mut self.ethdev, &mut self.sockets);
    }
}
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
unsafe fn main() -> ! {
    let cp = cortex_m::Peripherals::take().unwrap();
    let dp = stm32::Peripherals::take().unwrap();

    // Power
    let pwr = dp.PWR.constrain();
    let vos = pwr.smps().freeze();

    // RCC
    let rcc = dp.RCC.constrain();
    let mut ccdr = rcc.sys_ck(80.MHz()).freeze(vos, &dp.SYSCFG);

    // 48MHz CLOCK
    let _ = ccdr.clocks.hsi48_ck().expect("HSI48 must run");
    ccdr.peripheral.kernel_usb_clk_mux(UsbClkSel::Hsi48);

    // If your hardware uses the internal USB voltage regulator in ON mode, you
    // should uncomment this block.
    // unsafe {
    //     let pwr = &*stm32::PWR::ptr();
    //     pwr.cr3.modify(|_, w| w.usbregen().set_bit());
    //     while pwr.cr3.read().usb33rdy().bit_is_clear() {}
    // }

    // Get the delay provider.
    let mut delay = cp.SYST.delay(ccdr.clocks);

    // GPIO
    let (
        gpioa,
        gpiob,
        gpioc,
        _gpiod,
        _gpioe,
        _gpiof,
        _gpiog,
        gpioh,
        gpioi,
        gpioj,
        _gpiok,
    ) = {
        (
            dp.GPIOA.split(ccdr.peripheral.GPIOA),
            dp.GPIOB.split(ccdr.peripheral.GPIOB),
            dp.GPIOC.split(ccdr.peripheral.GPIOC),
            dp.GPIOD.split(ccdr.peripheral.GPIOD),
            dp.GPIOE.split(ccdr.peripheral.GPIOE),
            dp.GPIOF.split(ccdr.peripheral.GPIOF),
            dp.GPIOG.split(ccdr.peripheral.GPIOG),
            dp.GPIOH.split(ccdr.peripheral.GPIOH),
            dp.GPIOI.split(ccdr.peripheral.GPIOI),
            dp.GPIOJ.split(ccdr.peripheral.GPIOJ),
            dp.GPIOK.split(ccdr.peripheral.GPIOK),
        )
    };

    // It is very likely that the board you're using has an external
    // clock source. Sometimes you have to enable them by yourself.
    // This is the case on the Arduino Portenta H7.
    let mut oscen = gpioh.ph1.into_push_pull_output();
    delay.delay_ms(10u32);
    oscen.set_high();
    // Wait for osc to be stable
    delay.delay_ms(100u32);

    // Set USB OTG pin floating
    let mut _usb_otg = gpioj.pj6.into_floating_input();

    // Reset USB Phy
    let mut usb_phy_rst = gpioj.pj4.into_push_pull_output();
    usb_phy_rst.set_low();
    delay.delay_ms(10u8);
    usb_phy_rst.set_high();
    delay.delay_ms(10u8);

    // Enable USB OTG_HS interrupt
    cortex_m::peripheral::NVIC::unmask(pac::Interrupt::OTG_HS);

    let usb = USB1_ULPI::new(
        dp.OTG1_HS_GLOBAL,
        dp.OTG1_HS_DEVICE,
        dp.OTG1_HS_PWRCLK,
        gpioa.pa5.into_alternate(),
        gpioi.pi11.into_alternate(),
        gpioh.ph4.into_alternate(),
        gpioc.pc0.into_alternate(),
        gpioa.pa3.into_alternate(),
        gpiob.pb0.into_alternate(),
        gpiob.pb1.into_alternate(),
        gpiob.pb10.into_alternate(),
        gpiob.pb11.into_alternate(),
        gpiob.pb12.into_alternate(),
        gpiob.pb13.into_alternate(),
        gpiob.pb5.into_alternate(),
        ccdr.peripheral.USB1OTG,
        &ccdr.clocks,
    );

    USB_BUS_ALLOCATOR = Some(UsbBus::new(usb, &mut USB_MEMORY_1));

    let usb_serial =
        usbd_serial::SerialPort::new(USB_BUS_ALLOCATOR.as_ref().unwrap());

    let usb_dev = UsbDeviceBuilder::new(
        USB_BUS_ALLOCATOR.as_ref().unwrap(),
        UsbVidPid(VID, PID),
    )
    .strings(&[usb_device::device::StringDescriptors::default()
        .manufacturer("Fake company")
        .product("Serial port")
        .serial_number("TEST PORT 1")])
    .unwrap()
    .device_class(usbd_serial::USB_CLASS_CDC)
    .max_packet_size_0(64)
    .unwrap()
    .build();

    interrupt_free(|cs| {
        USB_DEVICE.borrow(cs).replace(Some(usb_dev));
        SERIAL_PORT.borrow(cs).replace(Some(usb_serial));
    });

    loop {
        cortex_m::asm::nop();
    }
}

#[interrupt]
fn OTG_HS() {
    interrupt_free(|cs| {
        if let (Some(port), Some(device)) = (
            SERIAL_PORT.borrow(cs).borrow_mut().as_mut(),
            USB_DEVICE.borrow(cs).borrow_mut().as_mut(),
        ) {
            if device.poll(&mut [port]) {
                let mut buf = [0u8; 64];
                match port.read(&mut buf) {
                    Ok(count) if count > 0 => {
                        // Echo back in upper case
                        for c in buf[0..count].iter_mut() {
                            if 0x61 <= *c && *c <= 0x7a {
                                *c &= !0x20;
                            }
                        }

                        let mut write_offset = 0;
                        while write_offset < count {
                            match port.write(&buf[write_offset..count]) {
                                Ok(len) if len > 0 => {
                                    write_offset += len;
                                }
                                _ => {}
                            }
                        }
                    }
                    _ => {}
                }
            }
        }
    })
}
*/

#[exception]
unsafe fn HardFault(ef: &cortex_m_rt::ExceptionFrame) -> ! {
    panic!("HardFault at {:#?}", ef);
}

#[exception]
unsafe fn DefaultHandler(irqn: i16) {
    panic!("Unhandled exception (IRQn = {})", irqn);
}
*/

#[cfg(test)]
mod test {}

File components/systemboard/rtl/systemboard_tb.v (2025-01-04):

module systemboard_tb();

    localparam ACTIVE = 1'b0;
    localparam INACTIVE = 1'b1;

    reg clock;
    reg reset;
    wire status_led;

    wire vme_sysclk;

    reg vme_address_strobe;
    reg [1:0] vme_data_strobe;
    reg vme_lword;
    reg vme_write;
    wire vme_dtack;
    reg [5:0] vme_address_mod;
    reg [23:0] vme_address;
    wire [7:0] vme_data;

    wire vme_bclr;
    wire [3:0] vme_bgout;
    reg [3:0] vme_br;

    systemboard DTS(
        .clock(clock),
        .reset(reset),
        .status_led(status_led),

        .vme_sysclk(vme_sysclk),

        .vme_address_strobe(vme_address_strobe),
        .vme_data_strobe(vme_data_strobe),
        .vme_lword(vme_lword),
        .vme_write(vme_write),
        .vme_dtack(vme_dtack),
        .vme_address_mod(vme_address_mod),
        .vme_address(vme_address),
        .vme_data(vme_data),

        .vme_bclr(vme_bclr),
        .vme_bgout(vme_bgout),
        .vme_br(vme_br)
    );

    initial begin
        $display("Starting");

        $dumpfile("systemboard.vcd");
        $dumpvars(0, DTS);
    end

    always
        #10 clock = !clock;

    initial begin
        #0
            reset = INACTIVE;
            vme_address_strobe = INACTIVE;
            vme_data_strobe = { INACTIVE, INACTIVE };
            vme_lword = INACTIVE;
            vme_write = INACTIVE;
            vme_address_mod = 6'b111111;
            vme_address = 24'hFFFFFF;
            vme_data = 8'hFF;

        #10

            vme_write = ACTIVE;

        #10
            vme_address = 24'h555554;
            vme_address_mod = 6'h3D;
            vme_address_strobe = ACTIVE;
        #8
            vme_data_strobe = { ACTIVE, ACTIVE };


            while (vme_dtack == INACTIVE) begin
                #10;
            end

        #10
            vme_address_strobe = INACTIVE;
            vme_data_strobe = INACTIVE;
            vme_write = INACTIVE;

        #50
            $finish;

    end

endmodule

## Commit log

2023-09-04 Start of backplane and cpu card design
    [Bus.kicad_sch, CPU.kicad_sch, IO.kicad_sch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]
2023-09-30 Updated k30 CPU card
    [Bus.kicad_sch, CPU.kicad_sch, IO.kicad_sch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]
2023-10-01 Renamed BP8 to BUS8
    [IVB-BUS8.kicad_pcb, IVB-BUS8.kicad_sch, Socket.kicad_sch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]
2023-12-10 Committed changes to k30 board from Oct 9th 2023
    [Bus.kicad_sch, Logic.kicad_sch, Memory.kicad_sch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]
2023-12-19 Added STM32H7-based controller schematic, and start of board layout
    [Bus.kicad_sch, Controller.kicad_sch, IO.kicad_sch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]
2023-12-21 STM32H7 PCB work in progress
    [Bus.kicad_sch, IO.kicad_sch, IVC-STH7.csv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]
2023-12-23 Reorganized to make it easier to group hardware and firmware files together
    [BigBoy.csv, BigBoy.kicad_pcb, BigBoy.kicad_sch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]
2023-12-28 Most of the routing for BigBoy is done
    [BigBoy.csv, BigBoy.kicad_sch, Controller.kicad_sch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]
2023-12-28 Completed all connections for BigBoy
    Now it's just final checks and adjustments lefts
    [BigBoy.csv, BigBoy.kicad_sch]
2023-12-30 BigBoy Rev.1 is complete and ready to order
    [BigBoy.kicad_sch, Bus.kicad_sch, Controller.kicad_sch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]
2024-08-05 Reorganized, and completed SystemBoard PCB
    [6-Slot-Backplane.kicad_pcb, 6-Slot-Backplane.kicad_sch, 60mm-Extender.kicad_pcb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]
2024-08-31 Added SystemBoardSMT, renamed k30 boards, and added progress
    [6-Slot-Backplane.kicad_pcb, 6-Slot-Backplane.kicad_sch, Bus.kicad_sch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]
2024-09-07 Updating with more work in progress
    [60mm-Extender.kicad_pcb, 60mm-Extender.kicad_sch, Bus.kicad_sch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]
2024-09-25 Reorganized a bit
    [6-Slot-Backplane.kicad_pcb, 60mm-Extender.kicad_pcb, Bus.kicad_sch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]
2024-09-27 Added SystemBoardSMT schematics
2024-10-13 Basic systemboard logic for bus arbitration is working and tested
    [Bus.kicad_sch, CPU.kicad_sch, IO.kicad_sch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]
2024-10-19 Schematics for k30p-VME more or less done
    [Bus.kicad_sch, CPU.kicad_sch, Logic.kicad_sch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]
2024-10-23 WIP on k30p-VME
    [CPU.kicad_sch, Transceivers.kicad_sch, k30p-VME.kicad_pcb]
2024-10-27 Removed unstarted computie designs
    [Bus.kicad_sch, CPU.kicad_sch, IO.kicad_sch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]
2024-10-27 k30p-VME PCB work in progress
    [CPU.kicad_sch, Transceivers.kicad_sch, k30p-VME.kicad_pcb]
2024-11-12 Mostly finished k30p-VME board and frontpanel
    [BigBoy-Frontpanel.kicad_pcb, BigBoy-Frontpanel.kicad_sch, Bus.kicad_sch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]
2024-11-24 Added MemBird - Woodcock (16-bit VME memory card)
    [Bus.kicad_sch, IO.kicad_sch, Logic.kicad_sch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]
2024-11-27 MemBird - Woodcock Rev.1 Schematic is complete
    [Bus.kicad_sch, Logic.kicad_sch, MemBird - Woodcock.kicad_pcb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]
2024-12-01 Finished the MemBird - Woodcock 16-bit memory board layout
    [Logic.kicad_sch, MemBird - Woodcock.csv, MemBird - Woodcock.kicad_pcb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]
2024-12-03 k30p-VME rev.1, MemBird Woodcock rev.1, and frontpanels
    [BigBoy-Frontpanel.kicad_pcb, Bus.kicad_sch, CPU.kicad_sch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]
2025-01-13 Minor fixes and notes
    [main.rs, main_busanalyzer.rs, main_peripheral.rs]
2025-01-16 Fixed k30p running code from membird
    The issue turned out to be the DS0 and DS1 signals were swapped, but
    everything else was correct on both the memory card and the k30p, with
    the transceivers and which pins they were connected to. The k30p can
    now run the monitor from the memory card
    [main_analyzer.rs]
2025-01-27 Reorganized all subprojects into `components`
    [6-Slot-Backplane.kicad_pcb, 6-Slot-Backplane.kicad_sch, 60mm-Extender.kicad_pcb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]
2025-01-28 Fixed board readmes
    [Bus.kicad_sch, SystemBoard.kicad_pcb, SystemBoard.kicad_sch]
2025-02-09 Added system reset logic to SystemBoard CPLD
    An extra capacitor needs to be installed to get power-on reset
    functionality, but pressing the reset button will now reset the whole
    system via the /SYSRESET signal on the VME bus, with a timer before the
    reset is released
2025-02-11 I thought I'd fixed the issue where two CPU cycles would sometimes occur per VME cycle
    Things were seemingly working after I increased the clock to 25MHz from
    12.5MHz, but it would read ATA sectors from the CF card that were all
    the same non-zero value, which wasn't the correct data at that sector.
    The problem in the logic analyzer traces was that CPU_AS would go high,
    and then low again, before VME_AS would go high. This was a problem
    especially for writing the sector number to the ATA registers, when the
    data bus value would change before the CF card had latched it in.
    I tried adding an extra state in the vme logic to stop the signals and
    then wait for DTACK to be de-asserted. I managed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
2025-02-15 k30p logic: works as best as it has, but still can't ls /bin
    This uses an inverted clock, which should smooth out the clock a bit
    more, compensating for only using 2 gates for the clock circuit. It
    also rearranges the dsack logic a bit. I'm going to try clocking the
    dsack logic, and other more drastic changes to get the last issues out.
2025-02-17 Fixed systemboard bus logic to not hang
    I also went through a length weeks long debugging arc that thought it
    was the buslogic only to find it was the systemboard *and* the bus
    logic, and trying to focus on the buslogic to get the last bug sorted
    only to find it was actually a bug that happens on the k30-SBC as well,
    so it's not related to the logic most likely. Now I've fixed the system
    board bug and I need to debug the listing bug from the software side
2025-03-05 Added images of the schroff case
2026-09-18 Reorganized computie rtl a bit
    The RTL has been moved to a rev1 directory, and a copy of the RTL will
    be in a rev2 directory, since the pin assignments will change, and the
    logic will be different. This way, I can modify and fix bugs for older
    revisions
2026-10-04 Renamed gerber zips and added kicad zips for each printed revisions
